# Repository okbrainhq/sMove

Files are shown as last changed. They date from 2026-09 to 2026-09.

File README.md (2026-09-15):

# sMove — PCB + three-piece enclosure

> **Schematic ECO 2026-09-15 (SCHEMATIC ONLY — no PCB change, no routing).** Added **SW1**, an off-board pack toggle switch in series in the battery + lead (hard "True OFF", ≥0.5 A / <50 mΩ, wired to the same 2.54 mm wire-pad footprint as J2); routed the charger's open-drain **CHG_N** to **U1 GPIO6** with a 100k pull-up (**R24**); and changed **U4** to **XC6220B331MR-G** (SOT-25, LCSC C86534) with a new footprint `SOT-25_XC6220`. The AP2112K's SOT-23-5 pin map is identical (1=VIN 2=VSS 3=CE 4=NC 5=VOUT), so no rewire was needed. ERC is **0 violations**, matching the pre-change baseline; the board, `dist/` and enclosure data are unchanged and stale until a forward update (F8) plus placement is done. See [Main PCB status](PCB/main/README.md) and [radio/battery architecture](docs/revision-r2/integrated/RADIO-BATTERY.md).

> **Current PCB workspace revision: components staged, UNROUTED.** [Main PCB status](PCB/main/README.md): schematic links repaired; ESP32/U1, USB-C/J1, IMU/U2 and battery +/− holes/J2 remain fixed, with the other 43 footprints staged to the right for manual placement. No tracks/vias; latest zone state preserved. Forward schematic update reports 0 errors/warnings and DRC finds 0 schematic-parity issues. A pre-existing J2/U1 courtyard overlap and unrouted connections remain. **Not for fabrication or charging; exports/enclosure data are stale.**

> **Historical routed PCB revision:** [Routing completion, plane selection and verification](docs/revision-r2/main-routing/README.md): the user's rotated-U8 USB layout is retained, remaining nets use top/bottom routing, In1 is GND and In2 contains power regions. **0 DRC errors, 0 unconnected items, 0 parity issues; one existing J2 library warning.** [Reusable routing/rotation tools](scripts/pcb_tools/README.md) include exact manual coordinates and vias. **Not a fabrication/charging release; `dist/` and enclosure exports remain stale.** Earlier enclosure descriptions below are historical. The prior RED LED GPIO3 change remains required.

> **Previous PCB update:** The [LED is now fully routed on the user's revised layout](docs/revision-r2/led-routing/README.md), with top-left/bottom-right space reserved for future M3 hardware. The enclosure and `PCB/main/dist/` remain older snapshots; their alignment/manufacturing claims below do not apply to the revised PCB without regeneration and review.

**Current review: white rounded Midframe + Top cover + Bottom cover. No screws, nuts, inserts or PCB enclosure-mounting holes. Default outer wall 0.8 mm; configurable and checked at 1.2 mm. No merge, manufacturing release or charging release.**

- [Current enclosure and regeneration](housing/README.md): opposite-side battery/PCB pockets, insulated support, optional PCB adhesive, screwless sleeve/snap covers and an internal perimeter BAT route around the separator edge.
- [PCB](PCB/main/README.md): targeted H1/keepout removal and copper refill; all 1,726 tracks and 97 vias preserved. Circuit, pad geometry, aligned buttons, antenna rules and battery interface unchanged.
- [JLCPCB fabrication/assembly export](scripts/jlcpcb/README.md): regenerates `PCB/main/dist/jlcpcb/` (`gerber.zip`, `bom.csv`, `pick_and_place.csv`, `export-report.json`) from the native KiCad `LCSC`/`MPN` fields on the symbols and footprints.
- [Historical screwless revision evidence](docs/revision-r2/screwless/README.md): fresh configured DRC/ERC, full native comparisons, manifold solids, collision/access checks, actual wall variation, FreeCAD images and hash manifests.
- [Printing/assembly and physical gates](housing/PRINTING-ASSEMBLY.md): actual pack/lead exit, insulation/adhesive, print supports, snap fit/creep, PCB deflection and charging qualification still required. No proven physical fit.

Default envelope including snap reinforcement: **42.85 L × 34.3 W × 19.0 H mm**. Accepted 30×20×3 mm battery candidate / 31×21×4.3 mm complete-pack allowance retained, behind the north antenna exclusion. Main underside faces the body; IMU +Z remains outward. LED, RESET/BOOT and USB-C accesses align to the current native PCB.

Previous [button alignment](docs/revision-r2/button-alignment/README.md), [PCB repair](docs/revision-r2/pcb-repair/README.md), and [two-part case](docs/revision-r2/two-part-case/README.md) records are historical snapshots, not current assembly instructions. Unrelated electronics and history are preserved.

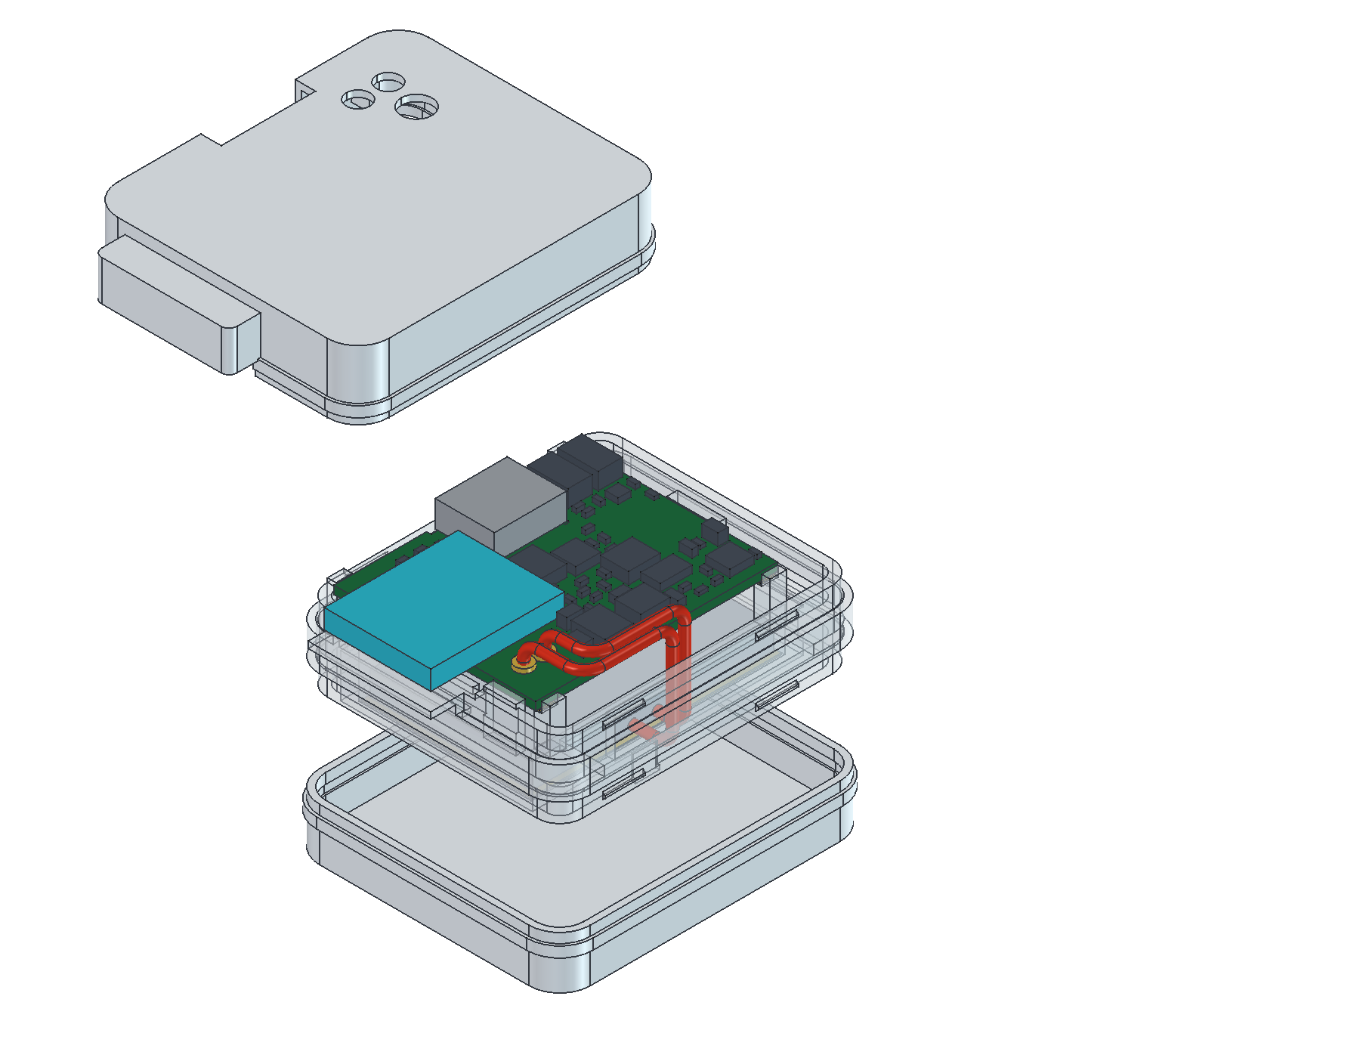
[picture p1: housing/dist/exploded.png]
Current three-piece exploded CAD


### Enclosure-only RF test prototype

Current `housing/` preserves the validated 25×30 mm PCB unchanged. Three screwless prints integrate a protected original-module antenna cap, source-derived flush USB mouth and internal perimeter BAT route around (not through) the separator. Overall 42.85×34.3×19.0 mm at 0.8 mm walls. See [housing documentation](housing/README.md) for source evidence, nominal checks and physical/RF/sweat qualification holds. No PCB shrinking or external antenna substitution.

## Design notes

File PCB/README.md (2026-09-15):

# PCB deliverables

> **Current alignment revision:** [RESET/BOOT switches and matching lid openings](../docs/revision-r2/button-alignment/README.md). Supersedes the historical unchanged-PCB claims below; review only, not released.

**Current design:** [repaired 25×30×1 mm main PCB](main/README.md), with the IMU fitted directly on top. All PCB/main files remain byte-identical to the complete e033031 repair recovered as 0610d60; no PCB edit accompanied the central-screw case revision.

The historical PCB-only mounting warning is retained in its original report. For the current central H1 M3×8 assembly use the [combined delivery](../docs/revision-r2/two-part-case/README.md) and [case assembly/insulation gates](../housing/PRINTING-ASSEMBLY.md). CAD checks do not release it for manufacture or charging.

Old compact-placement reviews are archival, NOT part of the current assembly; see the [bounded cleanup inventory](../docs/revision-r2/two-part-case/integration-cleanup.md) for their status.

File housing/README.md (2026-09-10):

# Enclosure-only — RF TEST PROTOTYPE

Three white rounded screwless prints: **Midframe + Top cover + Bottom cover**. Existing validated **25×30 mm PCB, schematic, routing, copper RF exclusions and native module remain unchanged**. No PCB shrinking or external antenna substitution. No manufacturing/charging release, no full Espressif housing-clearance compliance. Enlarge the housing if on-player testing requires it.

## Geometry and fit

- Default ordinary walls/roof/floor: **0.8 mm**, configurable through 1.2 mm. Main body including snap bands: **39.3 L ×34.3 W ×19.0 H mm**. Protected antenna extension makes overall **42.85 L ×34.3 W ×19.0 H mm**. At 1.2 mm: overall **43.65×35.1×19.4 mm**. Main-body length was reduced, not the PCB; the internal perimeter wire corridor adds width.
- Existing module end extends past the main compartment into a thin nonmetallic cap: floor integral with midframe, roof/skirt integral with top cover. No fourth print or bare exposed antenna. Cap floor/roof follow wall setting. This close plastic cap is explicitly an RF compromise, not a clearance-compliant housing or liquid seal.
- Battery candidate remains 30×20×3 mm; complete-pack allowance remains 31×21×4.3 mm (case XYZ 21×31×4.3). Pocket 21.4×31.4; separator gap 0.7. Optional qualified adhesive/insulating supports, no pouch compression. Hard perimeter stops take closure load.
- BAT wires now leave pads **upward +Z**, opposite the inherited below-board model, bend west and run along the **internal midframe perimeter**, descend around the separator's west edge, and return through a locator-only relief to the underside battery. The separator remains continuous over the entire pack. No wire hole through the separator. Exact two routes are in `validation/mechanical.json` and visible in `dist/assembled-wire-path.png` (orange wires, cyan module).
- Conditional wire OD≤1.2 mm, R2 centreline bends, 0.25 mm radial routing reserve; solder reserve radius 1.1 mm, height 0.55 mm above pads. Minimum nominal lead-to-print clearance 0.43 mm; reserve-to-print 0.18 mm, lead-to-lead 0.30 mm at both checked walls. Battery and wire reserves remain respectively 1.5 and 2.18 mm away from the retained forward RF exclusion. These are CAD measurements, not manufacturing tolerance guarantees.
- Sleeve clearance 0.18 mm; insertion flex 0.12 mm; groove radial clearance 0.12 mm. Snug covers require physical printer/material calibration. RESET/BOOT holes 2.9 mm, web 0.85 mm; LED aperture 3.8 mm retained.

## Source-derived flush USB-C

J1 is **HRO TYPE-C-31-M-12 / LCSC C165948**, retained native footprint. `sources/hro-type-c-31-m-12.pdf` is the supplier-hosted HRO drawing copied from workspace 032's mechanical evidence only, not its failed layout. `sources/usb-mechanical-evidence.json` preserves source URLs, drawing SHA256 and dimensional evidence; its prior proposed cutout is historical, superseded here.

Drawing nominal body W×D×H = 8.94×7.35×3.26 mm; maximum W/H = 9.09/3.36 mm. Native locator datum case X18.5 + drawing front distance 6.28 puts the metal mouth at **X24.78** (native X124.78), 0.03 mm beyond the inherited simplified envelope face. The local stepped exterior surround terminates at that exact nominal mouth plane; the plastic outside it is relieved. This is not a recessed insertion tunnel. Main lower shoulder remains wider.

Opening **10×4.3 mm** exceeds the source maximum plus **0.2 mm placement +0.2 mm print/fit allowance per side** (minimum 9.89×4.16). Nominal source body/mating aperture geometry is separately modeled; component collision checks also retain the conservative native envelope. Check the actual connector placement and selected cable overmould on a print: **no “any cable” guarantee**, and exact as-built flushness cannot be guaranteed from nominal CAD.

## Files and regeneration

`smove-r2-enclosure.FCStd` is editable native CSG with live `Parameters.Wall`. `dist/smove-r2-printable.step` contains exactly three solids; `dist/smove-r2-assembly.step` includes reference electronics, battery, insulation, wires and solder. Three STLs have print orientations; seven PNGs include opaque assembled, transparent wire-path, exploded and section views. Prints are white; transparent presentation is diagnostic only.

Edit `housing/screwless.json` → `outer_wall_mm` (default 0.8). From repository root:

```sh
/usr/bin/python3 scripts/freecad/bootstrap.py --verify-only
# If runtime absent, run bootstrap.py without --verify-only first.
/usr/bin/python3 scripts/r2/enclosure/extract.py
/usr/bin/python3 scripts/freecad/run.py housing/entry.py generate
/usr/bin/python3 scripts/freecad/run.py housing/entry.py generate 1.2
cp .cache/wall-1.2/validation/mechanical.json housing/validation/wall-1.2.json
/usr/bin/python3 scripts/freecad/run.py housing/check_native.py
/usr/bin/python3 scripts/freecad/run.py housing/qualify.py
# In an available authorized X11 display:
/usr/bin/python3 scripts/freecad/run.py housing/render.py
python3 housing/seal.py
python3 housing/seal.py --check
```

**Do not regenerate PCB exports.** Generation asserts hashes of retained PCB and board STEP. Alternate wall outputs stay in `.cache/wall-1.2`; default outputs remain 0.8. `check_native.py` and `qualify.py` expect the default 0.8 delivery and alternate 1.2 build. `entry.py verify` regenerates; it is not read-only. Other dimensions/route changes require deliberate source edits and complete revalidation, not just changing Wall.

## Evidence and qualification limits

`validation/mechanical.json` and `wall-1.2.json`: 819 nominal checks each, including three valid closed solids/STEP reimport, component/pack/wire interference, measured wall, accesses and sampled insertion. `native-parameter.json`: 16 reopened-native/live-wall checks. `prototype.json`: independent manifold/orientation checks of both sets of STLs, sampled cover travel without lead collision, cap coverage rays and outward USB opening. Sampled motion/coverage are not continuous physical simulations or waterproofness proofs. `pcb-preservation.json` hashes every tracked PCB file against the unchanged Git baseline. `dist/manifest.json` binds sources, CAD, exports and reports (self excluded).

Physical gates: actual pack lead exit and soldering process, wire bend rating/strain relief, print accuracy/support removal, snap force/creep/cycles, drop/body movement, skin contact, RF on-player in intended orientations, sweat ingress/abrasion, thermal and charging suitability. The vendor pack-to-modeled-entry connection remains conditional on the selected pack. Do not force fit, charge, or claim sweat resistance from these nominal checks. See `PRINTING-ASSEMBLY.md`.

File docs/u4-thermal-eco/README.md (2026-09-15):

# U4 thermal layout ECO — workspace delivery

## Result and scope

Implemented in `/home/azero/.okbrain/workspaces/smove-files/045`, branch
`okbrain/smove-files/045-ebca5b6f`, based on `main` at **43ee2ea**. No commit or
base-branch modification was made. All ignored/untracked lock, backup,
`docs/revision-r2/` and `housing/` content was left alone.

- Board: eight **GND / net 18** plated through vias, **0.6 mm land / 0.3 mm drill**, and two solid GND pours.
- `smove-r2-main.kicad_dru`: six appended lines defining a **0.21 mm clearance rule scoped only to the two named new zones**. The pre-existing global 0.15 mm rule overrides the zone-local clearance, so setting the zone property alone is insufficient. The original rules are unchanged.
- No new tracks; no moved/deleted tracks, vias, pads, footprints, outlines or existing zones. **Every existing board UUID object, including all four complete zones and their filled polygons, is byte-identical.**
- No schematic, symbol, footprint-library, project-settings or fabrication-output file changed. `dist/jlcpcb/*` was not regenerated.
- U6 was intentionally left untouched. Its exposed-pad cooling warrants a separate layout/assembly review; a drilled cluster under that SMD pad must not be casually treated as standard no-via-in-pad construction.

## Preflight, exact output

`git log --oneline -3`:

```text
43ee2ea board: user routing + direct C11 ground path (thermal-ECO baseline)
5c86d78 Merge okbrain/smove-files/043-2e05b855 into main
267618d fab: regenerate JLCPCB assembly/fab outputs for the routed board
```

`git status --porcelain -- PCB/`:

```text
?? PCB/main/smove-r2-main-backups/
?? PCB/main/~smove-r2-main.kicad_pcb.lck
?? PCB/main/~smove-r2-main.kicad_sch.lck
```

`git merge-base --is-ancestor 43ee2ea HEAD` returned 0. No tracked PCB changes;
only the allowed untracked noise. The base directory was checked again at the
end and still had exactly this HEAD and PCB status.

## Measured geometry — not thermal performance

Measurements are from native copper geometry in millimetres. Saved zone
polygons are unioned, other connected components excluded, and actual drill
voids subtracted. Pads/tracks use KiCad polygonization with maximum 0.001 mm
curve error; circular holes use 1024-sided polygons. Values are reported to
0.001 mm², not with a claim of fabricated-board dimensional accuracy.

### Copper area

| Metric | Before | After |
|---|---:|---:|
| F.Cu same-layer contiguous GND copper containing U4 pin 2, including pads/tracks/via lands, minus holes | 1.058 mm² | 27.802 mm² |
| Directly attached F.Cu zone-only copper, minus cutouts/other components/drills | 0 | **26.008 mm²** |
| B.Cu same-layer contiguous copper reached from U4's original via, minus holes | 0.212 mm² | 50.281 mm² |
| New B.Cu zone-only copper, minus cutouts/drills | 0 | **50.025 mm²** |
| Existing In1.Cu GND filled polygon (before subtracting drilled voids) | 680.173 mm² | 680.173 mm², unchanged |

**Important baseline correction:** the saved board does NOT have 15 mm² of
contiguous front copper on pin 2 or no interlayer path. It already has a
0.6/0.3 mm through via at **(110.3, 119.7)**, UUID
`84533de4-9e53-4210-9cdf-38a20bf1c6b0`, connected by a 0.2 mm track to pin 2
and to the existing In1.Cu plane. Its bottom copper was only an annular land,
not a spreader. The ECO improves an existing narrow connection; it does not
create the first interlayer connection. Electrically connected board-wide GND
area is not interchangeable with thermally effective area.

### Polygon area proof

Both new outlines are the same rectangle:

```text
(104.5,117.0) → (113.2,117.0) → (113.2,123.2) → (104.5,123.2)
gross area = 8.7 × 6.2 = 53.940000 mm²
```

**F.Cu** (`U4_THERMAL_F.Cu`):

```text
53.940000  gross polygon
-26.448115 clearance cutouts / unfilled regions
 -0.777169 other F.Cu component (not counted towards the requirement)
 -0.706854 drilled voids in the directly attached component
=26.007862 mm² directly attached to U4 pin 2 — exceeds 25 mm² by 1.008 mm²
```

**B.Cu** (`U4_THERMAL_B.Cu`):

```text
53.940000 - 3.145030 clearance/unfilled cutouts - 0.769796 drilled voids
=50.025175 mm², one contiguous spreader
```

All eight new via centres lie in both the **same directly attached F.Cu
component** and the B.Cu spreader. U4 pin 2 inherits the zone's **solid/full
connection**, not a thermal relief; its footprint/pad record was not edited.
Both zones use priority 1, 0.2 mm minimum fill thickness, 0.21 mm clearance and
unconnected-island removal. All original zone definitions and fills remain
verbatim. The new rectangles are **17.000 mm** from the antenna keep-out.

### New vias and measured clearances

All are ordinary F.Cu–B.Cu through vias spanning the four-copper-layer board,
GND/net 18, diameter **0.600 mm**, drill **0.300 mm**, no via-in-pad. Coordinates
are absolute KiCad board coordinates, not fabrication-origin offsets.

| X mm | Y mm | Minimum gap to ANY existing track/via/pad, all copper layers |
|---:|---:|---:|
| 108.500 | 121.400 | 0.215887 mm |
| 108.600 | 119.700 | 0.267680 mm |
| 110.200 | 120.600 | 0.300000 mm |
| 111.400 | 121.900 | 0.236396 mm |
| 111.700 | 119.500 | 0.233773 mm |
| 112.100 | 120.300 | 0.300000 mm |
| 112.100 | 121.200 | 0.300005 mm |
| 112.900 | 121.600 | 0.237500 mm |

Minimum new-via/new-via edge gap: **0.294427 mm**. The array is staggered around
existing routing rather than forcing a regular grid through it. Zone/foreign
copper minimum gaps: **0.209490 mm F.Cu**, **0.209585 mm B.Cu**. These additional
geometric checks are important because the board-wide rule permits 0.15 mm.

### Counts and preservation proof

| Board item | Before | After | Change |
|---|---:|---:|---:|
| Track segments | 426 | 426 | 0 |
| Vias | 77 | 85 | +8 GND |
| Zones, including 3 rule/keep-out areas | 4 | 6 | +2 GND |
| Footprints | 53 | 53 | 0 |

The PCB text diff is **243 insertions / 0 deletions**; the scoped rules diff
is **6 insertions / 0 deletions**. All **570 original UUID-bearing board
objects**, plus the board settings and net table, are identical. SHA-256 of
the sorted original-object contents, before AND after:

```text
2395968efe291f80d9d4094aeb9fcb709e6de5a6fb2a11288028f21f4feb7b15
```

C11's direct grounding path remains exactly:

```text
F.Cu, GND, width 0.2 mm:
(113.8,116.3) → (113.8,116.127486) → (113.987486,115.94)
0.6/0.3 mm GND through via at (113.987486,115.94)
```

Its two segments and terminal via have matching before/after individual
SHA-256 hashes, UUIDs and complete s-expressions in `geometry.json`:

| UUID | Before = after SHA-256 |
|---|---|
| d8e59a01-d4bc-4fee-9aa6-d1b957c9a084 | 3efd501127e1100831a573a04b7a733f456befd1b488be982abbc4ddbfa67016 |
| 772e4247-d55b-4c14-9ccd-2492ecce88d9 | cea57377c59c4c5105f0b803d8feb91c202f6ae6ba926a14cab701b00d2d21b4 |
| 8855345a-7815-4444-8592-dd19988b35d9 | 7880821dcc05619653ac3cdfea56daa081877ceac84ed72dd1585ad4da671673 |

C11's entire footprint and all other nets' geometry are also covered by the
byte-equality assertions. Added objects are restricted to eight GND vias
and two GND zones; nothing was silently deleted or reserialized.

## DRC and refill evidence

Baseline command, before any change:

```sh
kicad-cli pcb drc --exit-code-violations --format json --output /tmp/smove-u4-eco-045/before-drc.json PCB/main/smove-r2-main.kicad_pcb
```

Result: **0 violations, 0 unconnected items**, exit 0; archived as
`baseline-drc.json` (default errors/warnings).

Final command, KiCad **9.0.8**, all severities including exclusions:

```sh
kicad-cli pcb drc --exit-code-violations --severity-all --all-track-errors --format json --output docs/u4-thermal-eco/drc.json PCB/main/smove-r2-main.kicad_pcb
```

Result: **0 violations, 0 unrouted/unconnected**, exit 0. No rule suppression
or DRC exclusions were added. Schematic parity was not requested/tested.

A full second refill was also run on an isolated copy with the actual
`.kicad_pro` and `.kicad_dru`. The geometric symmetric difference for **each
of the three copper zones was exactly 0 mm²**, including the original In1.Cu
plane (`refill-check.json`). The copied project files are essential: refilling
a standalone PCB with default project rules gives different copper clearances.

## Estimated thermal result — conditional, not measured

**This ECO is not thermal sign-off for sustained 470–700 mW.** Neither
junction temperature nor thetaJA was measured. The baseline review's
220–250 °C/W is not independently validated, especially given the existing
via/inner-plane path found above. A claim of ~130 °C/W or halving the RF peak
rise would be unsupported.

### Datasheet reference

Torex's XC6220 datasheet, SOT-25 power-dissipation page 26, gives **166.67 °C/W**
for a **40 × 40 mm**, 1.6 mm FR-4 test board, approximately **800 mm² copper
on each face**, four 0.8 mm through holes, natural convection. Its 600 mW
rating at 25 °C uses **Tj = 125 °C**. That much larger reference fixture cannot
be substituted for this board. The unmounted 250 mW figure corresponds to
400 °C/W on the same 100 °C rise basis. [source](https://media.digikey.com/pdf/Data%20Sheets/Torex/XC6220.pdf)

### Transparent copper/connection adjustment

For an illustrative, deliberately limited estimate, use:

```text
thetaJA = 400 || (Rshared + Raccess + Rvia)
X || Y = X*Y/(X+Y)
```

- The 400 °C/W parallel bypass is an **assumed heuristic** based on the
  unmounted reference, not a measured package thetaJC or independently known
  heat-flow branch.
- Calibrate the before network to the review's **250 °C/W** upper estimate.
- **Measured/design geometry:** the old 0.2 mm neck has 0.341697 mm centreline
  outside the U4 pad and original via land. The specified copper is 35 µm;
  F.Cu-to-In1.Cu centre spacing is 0.315 mm. Importantly, the old via already
  reaches this inner plane; do NOT charge it the full 1 mm barrel resistance
  when modelling that path.
- **Assume** copper conductivity 390 W/(m·K) and 25 µm plated via walls.
  `R = L/(k*A)` gives **125.16 °C/W old neck**, **31.64 °C/W old via to In1**,
  and about 100.45 °C/W for a full-depth 1 mm barrel.
- The calibration leaves `Rshared = 509.86 °C/W`, representing the unknown
  die/lead/board path. This is fitted, not a datasheet parameter.
- After the solid F.Cu pour, **assume 60 °C/W spreading/access resistance**
  (~0.82 squares of 35 µm copper). Credit only **4.5 effective parallel vias**
  from the original one plus eight new ones, acknowledging non-isothermal
  access. The other existing vias now reached by the pour receive no credit.
- Keep the shared package/board resistance fixed: give **no additional
  board-to-air cooling credit** to the measured 50.025 mm² bottom spreader.
  This avoids inventing an area-to-thetaJA curve that the datasheet does not
  supply. It is a limited connection-improvement model, not an enclosure
  thermal simulation, and the assumptions are not guaranteed conservative.

```text
Before: 400 || (509.86 + 125.16 + 31.64) = 250.00 °C/W
After:  400 || (509.86 + 60.00 + 31.64/4.5) = 236.22 °C/W
Delta: -13.78 °C/W (~5.5%)

Relative to the 166.67 °C/W datasheet fixture:
assumed board/connection penalty +83.33 → +69.55 °C/W
```

Varying assumed access 40–120 °C/W and effective vias 2–9 gives **232–247 °C/W**
with the same 250 °C/W baseline. This is a model-sensitivity span, **not** a
confidence interval or a guaranteed bound; unknown die-to-GND coupling,
plating, assembly, U6 heating, airflow and enclosure conditions may dominate.

### Peak-power steady-state projections

Stated design scenario: **40 °C local board ambient**, Vin **5.3 V**, Vout
**3.3 V**. Treat peak dissipation as continuous for this deliberately severe
steady-state projection; quiescent power is neglected relative to the stated
470/700 mW. These are *pre-protection linear projections*, not actual measured
RF burst peaks.

| Peak-power scenario held continuously | Before thetaJA 250 | After estimated thetaJA 236.22 | Delta |
|---|---:|---:|---:|
| 235 mA, 470 mW: junction rise | 117.50 °C | 111.02 °C | **−6.48 °C** |
| 235 mA, 470 mW: junction temperature | 157.50 °C | 151.02 °C | **−6.48 °C** |
| 350 mA, 700 mW: junction rise | 175.00 °C | 165.35 °C | −9.65 °C |
| 350 mA, 700 mW: junction temperature | 215.00 °C | 205.35 °C | −9.65 °C |

These projections exceed the 125 °C power-rating basis and reach/exceed the
**typical 150 °C thermal shutdown** region; the device cannot be assumed to
remain regulating at those projected temperatures. Thermal shutdown is not
an operating target or a substitute for qualification. [source](https://media.digikey.com/pdf/Data%20Sheets/Torex/XC6220.pdf)

**Unverified:** actual transient RF peak temperature, duty-cycle response,
physical thetaJA, worst-case enclosure ambient/airflow, actual via plating,
and XC6220 die-to-pin-2 thermal coupling. Verify a populated board under the
real RF workload and charging conditions. If 470–700 mW is sustained at the
stated ambient, use a lower-loss supply/thermally stronger regulator solution
rather than treating this copper ECO as sufficient.

## Reproduction and artifacts

`verify.py` reads the baseline with `git show 43ee2ea:...`, asserts byte-level
preservation, measures net copper area and checks clearances/connectivity.
It never writes a PCB/project file. `thermal-model.py` separately calculates
the labelled conditional model; it does not conflate geometric and thermal
measurements. Both require KiCad's Python `pcbnew` module and Shapely 2.x.

The commands used with the temporary dependency directory were:

```sh
PYTHONPATH=/tmp/smove-u4-eco-045/pylibs /usr/bin/python3 docs/u4-thermal-eco/verify.py > docs/u4-thermal-eco/geometry.json
PYTHONPATH=/tmp/smove-u4-eco-045/pylibs /usr/bin/python3 docs/u4-thermal-eco/thermal-model.py > docs/u4-thermal-eco/thermal-model.json
```

With Shapely installed in the same Python environment, omit `PYTHONPATH`.
No project trick was silently saved.

- `geometry.json`: counts, positions, clearances, area arithmetic, individual and aggregate preservation hashes.
- `drc.json`, `baseline-drc.json`: CLI DRC reports.
- `refill-check.json`: all copper fills reproduce with zero symmetric difference.
- `thermal-model.json`: input geometry, assumptions, network values and temperature projections.
- `after-front.png`, `after-back.png`: native-copper review diagrams, **not fabrication artwork**.

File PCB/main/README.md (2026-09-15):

# Main PCB — 25 × 30 × 1 mm manual-layout reset

## Current schematic ECO — pack cutoff switch, charger status, 3V3 LDO (2026-09-15, SCHEMATIC ONLY)

Applied to `power.kicad_sch`, `compute.kicad_sch` and `smove-r2-main.kicad_sch`:

* **SW1 — hard pack cutoff.** An off-board toggle switch in series in the battery **+** lead, upstream of the `PACK_P` node. Schematic symbol uses the same 2.54 mm two-pad wire footprint as J2 (`smove-r2-main:BatteryWire_2x_PTH_P2.54mm_D1.0mm`), `in_bom no` (user-supplied off-board part: **≥0.5 A rating, contacts <50 mΩ, ≥6 V DC**). Net split: `/Power/PACK_RAW` = J2.1 + SW1.2, `/Power/PACK_P` = SW1.1 + C2.1 + R14.1 + U6.2 + U6.3. This provides the *True OFF* that `docs/revision-r2/integrated/RADIO-BATTERY.md` records as missing.
* **R24 (100k, LCSC C25741) + `/CHG_N` net — charger status to the MCU.** Charger open-drain `CHG_N` (U6 pin 9) is pulled up to 3V3_MAIN and routed to **U1 pad 20 = GPIO6**; `/CHG_N` = U6.9 + R24.2 + U1.20. New sheet pin added to both the Power and Compute sheet symbols.
* **U4 = XC6220B331MR-G** (Torex, LCSC C86534) replaces `AP2112K-3.3TRG1`. The SOT-25 pin map **1=VIN 2=VSS 3=CE 4=NC 5=VOUT** is the *same function map* as the AP2112K SOT-23-5 it replaces, so no rewire and no pad remap was needed. New footprint `assets/smove-r2-main.pretty/SOT-25_XC6220.kicad_mod` (JEDEC MO-178 Var AA land pattern, identical geometry to `SOT-23-5`); the SW1 symbol was added to `assets/smove-r2-main.kicad_sym`.
* `J2` was moved down 10.16 mm **on the sheet only** (cosmetic, no connectivity change) to make room for SW1.

Verification (KiCad 9.0.8): `kicad-cli sch erc` reports **0 violations — identical to the HEAD baseline**, and `kicad-cli sch export netlist` confirms the three nets above.

**Deliberately not done — no PCB change and no routing.** The board still carries the AP2112K SOT-23-5 at U4 (its footprint field now differs from the schematic) and has no SW1/R24 footprints, so a forward update (F8) plus manual placement is required before parity is restored. `dist/` and the enclosure data remain stale and must be regenerated (`python3 scripts/jlcpcb/export.py PCB/main --overwrite`) after the board is updated. **Engineering prototype — no charge or fabrication approval.**

## Library and asset layout

All project-local KiCad libraries and models now live under `assets/` (moved from the project root; content byte-identical apart from the references below):

| Path | Contents |
|---|---|
| `assets/smove-r2-main.pretty/` | main footprint library (nickname `smove-r2-main`) |
| `assets/imu.pretty/` | integrated-IMU footprint library (nickname `imu`) |
| `assets/smove-r2-main.kicad_sym`, `assets/imu.kicad_sym`, `assets/Device.kicad_sym`, `assets/power.kicad_sym` | project-local symbol libraries |
| `assets/imu-models/` | local STEP models, referenced as `${KIPRJMOD}/assets/imu-models/...` |

`fp-lib-table`/`sym-lib-table` stay at the project root and point at `${KIPRJMOD}/assets/...`. Schematic sheets, project/design-rule files and `dist/` are untouched; only the U2 3D-model path (in the board and in `assets/imu.pretty/InvenSense_QFN-24_3x3mm_P0.4mm.kicad_mod`) changed text.

Verified with KiCad 9.0.8: the board reloads with the same 47 footprints, 461 tracks and 7 zones; DRC reports 0 violations / 0 unconnected / 0 schematic-parity (the DRC library check covers footprint-library resolution), ERC reports 0 violations, and all four symbol libraries parse and still contain every referenced symbol. Historical ECO scripts under `scripts/r2/` (for example `integrated/migrate.py`, `integrated/layout.py`) still name the pre-move project-root paths; they are documented as destructive historical helpers and must not be rerun on this board.

**Status note:** the headings below describe earlier working states. DRC on the currently saved `smove-r2-main.kicad_pcb` reports 0 violations, 0 unconnected items and 0 schematic-parity issues, and no footprint origin lies outside the board outline, so the "UNROUTED / components staged" wording below is stale and has not been rewritten here.

## M3 screw mounting holes with grounded copper rings (2026-09-15)

Three plated 3.2 mm M3 clearance holes were added to the three free board corners, each
with a 5.0 mm grounded copper ring on all four copper layers:

| Ref | Corner | Centre (native mm) | Hole | Ring | Net |
|---|---|---|---|---|---|
| **H1** | top-left | 103.20, 103.20 | 3.2 mm plated | 5.0 mm Ø, 0.90 mm annular, mask open | `GND` |
| **H2** | bottom-left | 103.20, 126.80 | 3.2 mm plated | same | `GND` |
| **H3** | bottom-right | 121.80, 126.80 | 3.2 mm plated | same | `GND` |

* Each centre is exactly 3.20 mm in from both adjacent edges, so the three holes are
  identical except for the corner they avoid. The top-right corner is **occupied** by J2
  and R3/R4/U8 — 1.4 mm of clear width, less than the drill.
* Footprint `smove-r2-main:MountingHole_3.2mm_M3_Pad_5mm` lives in
  `assets/smove-r2-main.pretty/`. It is a reduced-ring variant of KiCad's
  `MountingHole:MountingHole_3.2mm_M3_Pad`: that part's 6.4 mm pad needs 3.45 mm of
  board-edge clearance and does not fit any corner of this board. 5.0 mm is the largest
  ring that keeps ≥0.25 mm copper-to-edge (actual 0.70 mm), ≥0.15 mm foreign-net
  clearance (actual 0.44/1.10/0.81 mm) and a non-overlapping courtyard (actual
  0.26/0.41/0.33 mm, courtyard = the 5.5 mm M3 head envelope) at all three positions.
* `board_only`, excluded from BOM and position files, no schematic symbol: mounting
  hardware is not a purchased or placed part, and schematic parity stays 0.
* **Zones were deliberately not refilled.** The rings join the GND node by overlapping
  the saved In1.Cu plane (all three centres are inside the fill, DRC 0 unconnected). A
  fresh refill would re-cut 31.6 mm² of that plane even on the unmodified board, which
  is not part of this change.
* Board diff is **+333 lines, 0 deletions**; deleting the three footprint blocks
  reproduces the previous board byte-for-byte. `bom.csv` and `pick_and_place.csv` are
  byte-identical; the Gerbers gain only the three 5.0 mm rings and their mask openings,
  and the PTH drill gains one `T4C3.200` tool with three hits.
* DRC **0 / 0 / 0**, ERC **0**. See the
  [change record](../../docs/revision-r2/m3-mounting-holes/README.md) and its
  `verification.json`; reproduce with `python3 scripts/r2/final/m3_mounting_holes.py
  --check --geometry` and `python3 scripts/r2/m3-mounting-holes/verify.py`.
* **The enclosure does not have these holes.** `housing/` is still the screwless
  revision (no bosses, threads or inserts); it needs a companion revision before M3
  hardware is usable. Physical fit, torque and the RF effect of the new metal near the
  ESP32-C3 antenna are unqualified.

## Silkscreen outlines, pin-1 markers and free-library parts (2026-09-15)

All 46 assembled parts still carry verified `LCSC`+`MPN` fields, and the export
(`python3 scripts/jlcpcb/export.py PCB/main`) now also reflects these changes; see the
[change record](../../docs/revision-r2/silk-and-basic-parts/README.md) and its
`verification.json`, renders and live BOM audit.

* **U6** (BQ24074RGTR) had *no* silkscreen, so it had no pin-1 indicator: three corner
  brackets plus the same outside pin-1 arrowhead the IMU (U2) uses now point at the
  TS/pad-1 corner.
* **U1** (ESP32-C3-MINI-1) body outline and antenna boundary existed only on `F.Fab`.
  `F.Fab` is not part of the Gerber set, so JLCPCB's placement preview showed the module
  as bare 0.4 mm pads — that is why it "did not line up" there. The body outline is now
  copied to `F.SilkS`, clipped at the 100.0 mm board edge where the module overhangs,
  and the `F.Fab` corner chamfer is deliberately not copied (it crosses the left anchor pad).
* **J1** (USB-C receptacle) had no silkscreen at all — the standard shell lines were on
  `F.Fab` — so the same problem applied. Its shell sides and pad-side end are now on
  `F.SilkS`, offset past the `S1` shell pads and clipped at the board-edge notch.
* **D1** (LTST-C19HE1WT) got a closed silkscreen outline outside the land pattern with a
  gap over the pad-1 corner.
* The same geometry was added to the project-local library footprints
  (`assets/smove-r2-main.pretty/*.kicad_mod`), so the DRC library check stays clean.
* **C3** moved from `C29277` (22 µF 10 V, Extended, $3 setup fee) to **`C45783`
  (22 µF 25 V X5R 0805, Basic)**. Every other resistor and capacitor is already
  Basic/Preferred Extended and therefore fee-free, including R21 (`C25924`); the
  estimated extended-part fee drops from $33.00 to $30.00, and the remaining charge is
  the ten design-fixed actives.

Verification: DRC **0 violations / 0 unconnected / 0 schematic-parity**, ERC **0**, added
silk keeps ≥0.17 mm to the nearest pad (board rule 0.10 mm), `F_Silkscreen.gto` gains 36
draw commands, `bom.csv` differs only in the C3 row and `pick_and_place.csv` is
byte-identical. C45783's pocket-height check and a fresh DC-bias screen are still open.

## JLCPCB fabrication and assembly export

`/usr/bin/python3 scripts/jlcpcb/export.py PCB/main` (add `--overwrite` to refresh an existing
set) writes `dist/jlcpcb/`: `gerber.zip` (all four copper layers, masks, silkscreen, paste, edge
cuts, separate PTH/NPTH millimetre drills), `bom.csv`, `pick_and_place.csv` and
`export-report.json`. See the [export tool documentation](../../scripts/jlcpcb/README.md).

- Generated from the currently saved board (47 footprints, 461 tracks, 70 vias, 7 zones, 4 copper
  layers, aux origin 100/135) at this revision. Native DRC/parity on that same file reports
  **0 violations, 0 unconnected items, 0 schematic-parity issues**; the export tool re-verifies
  KiCad's own position output against the board file before writing anything.
- All **46** assembled parts carry a JLCPCB/LCSC catalogue number in the native `LCSC` field,
  together with `MPN`, on both the schematic symbols and the board footprints. The verified
  numbers are recorded in [main-parts.csv](../../docs/revision-r2/main-parts.csv) and
  [stock.json](../../docs/revision-r2/stock.json). J2 (the two plated battery wire holes) is
  intentionally PCB-only and excluded from both BOM and CPL.
- Engineering export only: **not a fabrication, assembly or charging release**. The tool does not
  refill zones, run DRC/ERC, check supplier stock or qualify any purchase code, and `housing/`
  remains a separate historical snapshot.

## Current: schematic links repaired; components staged — UNROUTED

**All 47 schematic footprints are now present.** U1 (ESP32), J1 (USB-C), U2 (IMU), and J2 (battery +/− holes) retain their poses and geometry. The other **43 footprints are staged outside the board to the right** for manual placement. No tracks or vias were added.

The reported dialog was **Update Schematic from PCB**, the reverse direction. Use **Tools → Update PCB from Schematic (F8)** to bring schematic components into the board. The four old footprint paths also contained an extra root-sheet UUID; one reference-based re-link repaired them without replacing or moving the footprints. Re-link is now off for normal updates. A repeat forward-update preview reports **0 errors and 0 warnings**, without duplicate additions. KiCad also repaired duplicate pad UUIDs on save; all pad geometry/nets and footprint UUIDs remain unchanged.

[Update verification](../../docs/revision-r2/manual-layout-reset/schematic-update-verification.json): **0 schematic-parity issues**, 148 expected unconnected items, and one **pre-existing J2/U1 courtyard overlap**, left unchanged to preserve both fixed positions. Schematics and design rules on disk are unchanged. The latest saved zone state was preserved: five rule areas and one filled In1 GND plane; the earlier six-unfilled-zone reset below is historical. **Not for manufacture or charging; exports remain stale.**

## Historical: manual placement/routing reset — UNROUTED

Only **U1 (ESP32), J1 (USB-C), U2 (IMU), and J2 (battery +/− through-hole pads)** remain in the PCB layout, with their complete footprint definitions, positions, orientations and pad/net assignments unchanged. The other **43 footprints were deleted from the PCB only**; all schematic sheets and project/rule files remain unchanged.

Removed **500 track segments, 124 vias, and all 38 cached copper-fill polygons**. All six copper-zone definitions are retained **unfilled**, including In1 GND and the In2 GND / 3V3_MAIN / PACK_P regions. Board outline, stackup, drawings and all keepouts are unchanged. This is actual copper removal, not merely hidden pours.

[Verification](../../docs/revision-r2/manual-layout-reset/verification.json): exact-token preservation check and native board load pass; native DRC reports **0 geometric violations**, **45 intentionally unconnected items**, and **43 expected missing-footprint parity warnings**, plus the existing J2 library-footprint mismatch warning. Previous routed-board acceptance scripts/reports below are historical and are not acceptance criteria for this reset. **Not for fabrication/assembly/charging; existing exports and enclosure placement data are stale.**

For manual placement, open `smove-r2-main.kicad_pro` in KiCad and use **Update PCB from Schematic (F8)** when ready to re-add the missing footprints. Do not delete their schematic symbols. The standalone PCB Editor has this command disabled; launch the editors through the project. J2 was restored verbatim from the pre-reset board at the user’s request, retaining both battery +/− holes. The other 43 missing components have not been re-added or parked outside the board.

## Historical: routed review candidate

See the [routing completion and plane-selection evidence](../../docs/revision-r2/main-routing/README.md). The user's rotated-U8 USB routing is preserved, remaining nets are connected on **F.Cu/B.Cu**, In1 is continuous GND, and In2 has bounded **3V3_MAIN / PACK_P power regions** with GND elsewhere. C7 alone is rotated 180° to fix its isolated ground connection; other placements, pad nets and keepouts are unchanged.

**Fresh native checks: 0 DRC errors, 0 unconnected items, 0 schematic-parity issues, 0 ERC violations; one existing J2 footprint-library warning.** Reusable coordinate routing, via placement, rotation previews, explicit rip-up and cleanup tools are documented in [scripts/pcb_tools](../../scripts/pcb_tools/README.md). Run `/usr/bin/python3 scripts/r2/main-routing/verify.py` for current acceptance checks.

**Not released for fabrication or charging.** USB impedance, current/thermal margins and return paths still need engineering review. Some low-speed paths take long perimeter detours. `dist/` and the enclosure are stale; no manufacturing exports were regenerated.

## Historical: grouped placement review — UNROUTED

See the [placement revision and researched routing strategy](../../docs/revision-r2/placement-routing/README.md). U1, USB, battery pads, outline and both M3 reserved positions are unchanged. The LED/buttons are upper-left, charger/regulator parts are together beside USB, and U2 remains at X112.5 with its original orientation, now at Y126.5. RED is reassigned from GPIO6 to GPIO3; GREEN=GPIO7 and BLUE=GPIO10 remain unchanged. Firmware must adopt the RED pin change.

**Placement only: 152 unconnected items; zero tracks/vias.** Obsolete routing was removed deliberately, not left connecting the wrong pads. Current zone definitions are retained but unfilled; the researched power-region strategy is not implemented yet. Placement geometry, ERC and schematic parity pass, with the existing J2 library-footprint warning. This is **not a finished reroute or manufacturing/charging release**. Existing `dist/` and enclosure openings are stale.

Run `/usr/bin/python3 scripts/r2/placement-routing/review.py` for this revision's checks. Do not use the historical LED-only verifier or layout generators as current acceptance tests.

## Historical: LED routed on the previous layout

The [LED routing update](../../docs/revision-r2/led-routing/README.md) builds on the user's `b155f03` routing setup. All RGB channels are connected, with D1 and every other footprint left in place. Top-left and bottom-right 6 mm clear disks are protected for future M3 hardware; no mounting holes were added. Fresh checks report **0 DRC errors, 0 unconnected items, 0 schematic-parity issues**, with three unchanged pre-existing warnings.

**The native PCB is authoritative. `dist/` and the enclosure are older snapshots, not regenerated for this routing update.** Do not use the older manufacturing bundle without regeneration and review. Run `scripts/r2/main/verify_led_routing.py` for current checks; do not run historical layout generators over this board.

## Historical screwless revision (before the user's reroute)

**Current: [screwless revision](../../docs/revision-r2/screwless/README.md). Not released for manufacture, assembly or charging.**

- Removed the H1 3.2 mm NPTH footprint and its H1-specific copper exclusion. Refilled copper zones into the reclaimed region; **did not reroute** or run legacy routing generators. Clean configured DRC/connectivity/parity did not require disturbing the accepted routing.
- Exact token comparisons retain all **1,726 segments, 97 vias, 47 non-H1 footprints and pad/net/placement data**, board outline, layer/setup data and antenna/corner rules. All five schematics, project rules and electrical parts are unchanged. Existing corner copper-free regions remain dielectric contact reserves, not fastener mounting features.
- Fresh configured ERC / DRC / unconnected / schematic-parity counts: **zero**. Existing ignored defaults remain unchanged; this is not electrical or charging release.
- Four layers, 1 mm nominal total board; In1 GND reference and existing circuit retained. Integrated top IMU +Z outward, underside toward body. Aligned RESET/BOOT at native X121.25; no new UART/testpoints/connectors.
- BAT+ native (104.5,105.57), BAT− (104.5,103.03); 2.54 mm pitch, 1 mm drill target, 2 mm pads unchanged. **USB's two 0.65 mm component locating NPTH holes and plated connector/BAT holes remain**: these belong to the preserved electrical connector footprint, not enclosure mounting hardware. No enclosure mounting holes remain.
- `dist/` is regenerated for this native PCB: Gerbers/drills, BOM/CPL, assembly PDF, board/installed-model STEP and renders. Conservative populated STEP uses exactly one instance per reference, no duplicate display copies. Missing vendor models remain limitations of installed-model renders.
- PCB-only STEP uses drill origin (100,135), unlike housing Y=139−nativeY. Its 0.91 mm dielectric thickness omits copper; the housing conservatively reserves the accepted total 1 mm. Do not mistake this export convention for a board-thickness ECO.

The native board is authoritative. Do not run legacy routing or historical sync tools over it. `scripts/r2/screwless/pcb.py` is the targeted, idempotent ECO/check entry; `scripts/r2/screwless/verify.py` compares against recorded aligned predecessor `b8f2836ac2fb26fc0bf774b803c6613a79e66f1b`. The enclosure uses insulated lands, optional adhesive and travel stops, not PCB or pouch clamping. Physical support/fit still needs qualification.

Historical [PCB repair](../../docs/revision-r2/pcb-repair/README.md) and [button alignment](../../docs/revision-r2/button-alignment/README.md) retain their original scope. Current exports are indexed by `dist/manifest.json`.

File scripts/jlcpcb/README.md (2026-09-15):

# JLCPCB fabrication + assembly export

`export.py` turns one KiCad project directory into the three files JLCPCB asks for,
plus a validation report:

```text
PCB/main/dist/jlcpcb/
  gerber.zip          fabrication data — Gerbers + Excellon drills
  bom.csv             assembly BOM (grouped purchase rows)
  pick_and_place.csv  CPL / centroid file (one row per reference)
  export-report.json  validation report — for review, NOT for upload
```

Upload `gerber.zip` as the PCB fabrication file, `bom.csv` as the assembly BOM and
`pick_and_place.csv` as the CPL / pick-and-place file.

The project is never modified: KiCad is driven from a private temporary directory and
the four files are published only after every check passes.

## Requirements

* Python 3.8+ (standard library only — no pip packages, no `pcbnew` bindings).
* KiCad 9's `kicad-cli` on `PATH` (tested with 9.0.8); override with `--kicad-cli` or
  the `KICAD_CLI` environment variable.

## Usage

```sh
# From the repository root: defaults to PCB/main -> PCB/main/dist/jlcpcb/
python3 scripts/jlcpcb/export.py

# Explicit project, explicit destination
python3 scripts/jlcpcb/export.py PCB/main --output /tmp/jlc-order

# Replace a previous export (existing files are protected by default)
python3 scripts/jlcpcb/export.py PCB/main --overwrite

# Other project layouts / options
python3 scripts/jlcpcb/export.py PCB/main --board smove-r2-main.kicad_pcb
python3 scripts/jlcpcb/export.py PCB/main --schematic main.kicad_sch
python3 scripts/jlcpcb/export.py PCB/main --pcb-only            # ignore the schematic
python3 scripts/jlcpcb/export.py PCB/main --side bottom         # one assembly side only
python3 scripts/jlcpcb/export.py PCB/main --include-through-hole
python3 scripts/jlcpcb/export.py PCB/main --part-field "Supplier Code"
python3 scripts/jlcpcb/export.py PCB/main --require-part-numbers
```

Fabrication layers are always plotted for the whole board, whatever `--side` selects
for assembly. Exit status: `0` success (warnings allowed), `1` error, `2` argument error.

## Cost check: Basic vs Extended parts

`parts_check.py` audits a generated BOM against the live JLC component library and reports
which parts are fee-free. JLCPCB's Economic PCBA charges **USD 3 per unique Extended
part**; Basic parts and *Preferred Extended* parts carry no setup fee, so a Basic or
Preferred replacement for one passive is worth more than its unit price.

```sh
python3 scripts/jlcpcb/parts_check.py PCB/main/dist/jlcpcb/bom.csv --json /tmp/audit.json
```

```text
OK  basic              C45783     stock=   4808921 $ 0.2432 22uF / 25V         C3
OK  preferred-extended C25924     stock=    220063 $ 0.0021 8.2k               R21
FEE extended           C54313     stock=       621 $ 2.1254 BQ24074RGTR        U6

28 BOM rows, fee-free 18, charged 10, estimated extended-part fee $30.00 (3.00/part)
```

This is a read-only query against the same public endpoint the JLC parts page uses: no
account, upload, reservation or order. Stock and library membership change daily, so
re-run it before ordering — the numbers in `docs/revision-r2/silk-and-basic-parts/`
are a dated snapshot, not a guarantee.

## How JLCPCB part numbers are stored in KiCad

The exporter reads **native KiCad fields**; no plugin, custom library or third-party
tool is involved. Add the field `LCSC` in the Schematic Editor (**E** on a symbol →
*Symbol Properties* → add field) and let **Tools → Update PCB from Schematic (F8)**
copy it onto the footprint. Fields added directly in the PCB Editor's *Footprint
Properties* work too. Leave the field's *Show* checkbox off if you do not want it
drawn on the schematic.

Field names are matched ignoring case, spaces and punctuation, so `LCSC`,
`LCSC_Part_Number` and `LCSC Part Number` are the same field.

| Output column | Recognized native fields |
| --- | --- |
| `LCSC Part #` | `LCSC`, `LCSC PN`, `LCSC Part #`, `LCSC Part Number`, `LCSC Part`, `JLCPCB`, `JLCPCB PN`, `JLCPCB Part #`, `JLCPCB Part Number`, `JLCPCB Part`, `JLC`, `JLC Part #` |
| `MPN` | `MPN`, `Manufacturer Part Number`, `Manufacturer Part #`, `Mfr Part #`, `Part Number` |
| `Manufacturer` | `Manufacturer`, `Mfr` |

Extra recognized LCSC fields can be added with `--part-field NAME` (repeatable).

Rules the exporter enforces:

* A part number must be `C` followed by digits (`c1525` is normalized to `C1525`).
  URLs, manufacturer part numbers and other text are **rejected** instead of being
  uploaded as a wrong catalogue code.
* The same part number may be stored on the schematic and on the board; a
  **conflicting** pair stops the export — the tool never guesses which part was meant.
* A part number stored only on the schematic is still exported (the schematic is read
  through `kicad-cli sch export netlist`, hierarchical sheets included).
* A missing part number leaves the BOM cell blank and prints a warning; add
  `--require-part-numbers` to make that an error instead.

In this repository all 46 assembled parts carry verified `LCSC` + `MPN` fields on both
the symbols and the footprints. J2 (the two plated battery wire holes) is deliberately
PCB-only and has no purchase code.

## What is exported

### `gerber.zip`

* Every copper layer declared in the board (all inner layers included), plus front/back
  mask, silkscreen and paste where present, and `Edge.Cuts`.
* Separate plated (`PTH`) and non-plated (`NPTH`) Excellon drill files in millimetres.
* Only freshly plotted fabrication files, flat at the ZIP root — no BOM, no project
  metadata, no stale plots. Protel-style extensions (`.gtl`, `.g1`, `.gbl`, `.drl`, …)
  plus KiCad's `.gbrjob`.

KiCad writes its plot creation date into every Gerber (`%TF.CreationDate%` and a `G04`
comment), so the per-file hashes in `export-report.json` differ between runs even though the
plotted geometry is byte-identical. `bom.csv` and `pick_and_place.csv` are byte-stable for
unchanged inputs.

### `bom.csv`

```csv
Comment,Designator,Footprint,LCSC Part #,Quantity,Manufacturer,MPN
47uF / 6.3V,"C2, C13",C_0805_2012Metric,C16780,2,,CL21A476MQYNNNE
```

The illustrative row above is real for this board. `Comment` is the board value,
`Footprint` is the footprint name without its library prefix, and references are listed
explicitly (never compressed to ranges) with correct CSV quoting. Rows are grouped only
when **value, footprint, part number, manufacturer and MPN all match**, so two
different purchase codes are never merged. If one part number legitimately appears in
more than one row (same part, different schematic values), the report lists it under
`part_number_used_by_several_rows` for review.

### `pick_and_place.csv`

```csv
Designator,Mid X,Mid Y,Layer,Rotation
C13,7.3000,15.0500,Top,270.00
```

Coordinates are millimetres in KiCad's **drill/place file origin** frame (this board:
`aux_axis_origin 100 135`), `Layer` is `Top`/`Bottom`, and `Rotation` is KiCad's
counter-clockwise footprint angle normalized to `[0, 360)`. Both CSVs always contain the
same reference set.

If a part needs a vendor orientation correction, add the native field
`JLCPCB Rotation Offset` with signed degrees (`90`, `-90`). It is added to the exported
rotation and recorded in the report; check the result in JLCPCB's placement preview.
Position offsets are not supported — fix the footprint anchor in KiCad instead.

## Selection rules

A footprint is assembled when all of the following hold:

* it has electrical pads (pure graphics and non-plated mounting holes are ignored);
* it is an SMD footprint (add `--include-through-hole` to also assemble through-hole
  parts after checking JLCPCB's availability);
* it is not marked *Do Not Populate*, *Exclude from BOM* or *Exclude from position
  files* on the board, and not *Exclude from BOM* / *Exclude from board* in the
  schematic;
* it is on the side selected by `--side` (default: both).

Skipped references and their reasons are listed in `export-report.json`. These flags do
**not** remove copper from the Gerbers.

## Checks performed

* KiCad's position file must agree with the board file this tool parses (origin, X, Y and
  rotation), so a mismatched or stale input cannot be exported silently.
* Duplicate or unannotated references, unreadable/absent positions, malformed or
  conflicting part fields and KiCad CLI failures stop the export.
* Value or footprint differences between schematic and board are warnings; the physical
  board wins. References present in only one source are reported.
* The plotted layer set, drill split, unique filenames and ZIP contents are validated
  before publishing.
* `export-report.json` records the SHA-256 of every source file, every fabrication file
  and the three upload files, plus layers, counts, skipped parts and warnings.

## Limits — read before ordering

The report is explicitly **not** a manufacturing release. This tool exports the saved
design; it does **not** refill copper zones, run DRC/ERC, repair outlines, edit the
project, check part stock or validate that a purchase code is electrically suitable.
Before ordering: save both editors, update the PCB from the schematic, refill zones, run
DRC and check the ZIP in a Gerber viewer; then verify part matches, polarity, placement
anchors, rotations and both sides in JLCPCB's preview.

## Tests

```sh
# Unit tests + end-to-end test with a fake kicad-cli (KiCad not required)
python3 -B -m unittest scripts.jlcpcb.test_export -v

# Additionally run the real exporter against PCB/main
JLC_INTEGRATION=1 python3 -B -m unittest scripts.jlcpcb.test_export -v
```

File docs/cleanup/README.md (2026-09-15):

# Repository cleanup evidence

Source-cleanup baseline: former main `9c7bb84cde1e7ee5842be48dd34e0169e0914b47`, isolated workspace 016. That source-cleanup phase performed no commits, history rewrites, branch/workspace deletion, advisors, sourcing or GUI probing. The subsequent local Git-maintenance phase consolidates this tree into one parentless `main` commit; saved CodeChat workspaces, their branch histories and the remote are retained. No remote fetch/push, shared reflog expiry or garbage collection is performed.

[evidence.json](evidence.json) records the BEFORE SHA256 and old-to-new file mapping captured before moves. All 282 baseline entries were independently checked against the baseline Git blobs after recovery from an interrupted provider response. Native projects, models, FCStd, STL/STEP, fabrication ZIPs, BOM and renamed CPL have byte parity; no native path repairs or engineering changes were necessary. Local relative library/model references travel with the boards.

## Retired checks — NOT PASSED

CFIX archival immutability, pre-R22 reference-board comparison, pre-ECO placement preservation, old carrier export preservation and whole-release bundle smoke tests no longer define current validity. Those inputs/checkpoints are not part of the current root snapshot; saved CodeChat workspaces and retained remote history remain available. No unsafe/reference KiCad files are retained just to satisfy obsolete tests.

Current equivalents are native configured ERC/DRC/net exports, main pin/net/fitted/outline/antenna/retention invariants, combined electrical/connector/endpoint checks, canonical housing extraction/contact checks, native BOM/CPL/CID/placement validation and before/after SHA256 parity. Historical test counts are not recycled as new results.

## Layout and scope

`PCB/main` owns one native project and its own dist. `housing` owns one editable FCStd and printable/reference outputs in dist. Fabrication ZIPs contain only Gerber/drill fabrication files, with separate BOM and pick-and-place CSVs. No top-level release/mega ZIP or archive junk folder.

Current source evidence, exact Samsung curves, footprint/pin audits, original models/licenses and historical stock retrieval receipts remain. Reports written by checks are disposable `.cache/` files. Old snapshots, synthetic fixtures, build/reroute/ECO scripts and historical entrypoints are removed.

## Limitations

GUI review remains blocked/not performed. No new visual approval, manufacturing or charge approval. FreeCAD native reopen/regeneration and the former 1938 geometric checks are not claimed as rerun without the pinned runtime. FCStd ZIP integrity and byte parity are not equivalent to recomputation. Optional heavyweight export/bootstrap commands are documented separately from read-only checks.

## Actual cleanup results

Seven read-only verification commands passed in a new project-local clean copy with all legacy directories physically absent. Fresh configured ERC/DRC: both boards zero violations, opens and parity issues; main 17 checks; combined electrical 96; carrier independent audit PASS (no invented assertion count). Standalone CSV/ZIP/manifest/library/link audit: 262 checks. Python syntax: 15 files. Byte parity: 28 critical CAD/model/fabrication/geometry files, and 260 of 282 retained baseline files overall. Support-script/document edits account for the remainder.

Five **external, unbundled model references remain unavailable** in this runtime: Espressif ESP32-C3-MINI-1, JST PH two- and four-pin headers, HRO USB-C and LiteOn LED. These are explicit non-passing model availability gaps, not missing moved local models; exact unavailable paths are recorded in evidence.json. All supplied project-local models resolve. Preserved populated STEP includes labelled conservative envelopes. No substitute models or native path edits were made. FreeCAD pinned runtime is absent; no reopen/regeneration or heavyweight export was run.

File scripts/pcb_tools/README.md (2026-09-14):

# Reusable PCB routing tools

Run from the repository root with `PYTHONPATH=scripts /usr/bin/python3 -m pcb_tools ...`.
Requires the installed KiCad `pcbnew` Python bindings and `kicad-cli`; image previews also use `python3-cairo`.

## Manual routing first for difficult areas

`waypoints` places **exact coordinates**, without a router changing the path. Units are mm in native board coordinates. Repeat the same position on the other outer layer to request a through via:

```sh
PYTHONPATH=scripts /usr/bin/python3 -m pcb_tools waypoints INPUT.kicad_pcb \
  --net '/SIGNAL' --width .2 \
  --points '[[10,10,"F.Cu"],[12,10,"F.Cu"],[12,10,"B.Cu"],[16,14,"B.Cu"],[16,14,"F.Cu"],[18,14,"F.Cu"]]' \
  --output-dir .cache/manual-candidate
```

Coordinates/net above are illustrative, not a recipe for this board. Output directory must be new. Unknown nets, internal trace layers, malformed layer transitions, nonfinite coordinates, obstructed edges, via/paste overlaps and hole conflicts are rejected before insertion. Rejections identify blocking pads/tracks; no half-route is inserted. Explicit `--ripup-id UUID` or `--ripup-net NET` removes selected copper **only in the candidate copy**.

For several coordinated manual edits:

```sh
PYTHONPATH=scripts /usr/bin/python3 -m pcb_tools.recipe INPUT.kicad_pcb edits.json .cache/candidate
```

JSON accepts `remove_ids`, `remove_nets`, `routes` (`net`, `width`, `points`, optional `rules`), optional `zones` (`name`, `net`, `layer`, `priority`, polygon `points`), and optional `move_footprints` (`reference`, `expected_rotation`, `rotation`, optional absolute `position`). Explicit copper invalidation is required for footprint movement; it does **not** automatically reroute stale connections. Recipes in `scripts/r2/main-routing/` record reviewed intermediate edits and contain revision-specific UUIDs: they are examples/audit records, **not an idempotent final-board generator**.

Every saved candidate receives a native DRC/parity report. A saved candidate is not necessarily acceptable: inspect its DRC counts, connectivity, copper fill and image before adopting it. No command overwrites the input board or modifies the input project's rules. Failed recipe geometry leaves the initial candidate copy unchanged.

## Two-point routing

```sh
PYTHONPATH=scripts /usr/bin/python3 -m pcb_tools route INPUT.kicad_pcb U1:26 R3:2 \
  --width .2 --layers top --output-dir .cache/two-point
```

Omit `--output-dir` for a read-only plan. Endpoint pads must belong to the same net; duplicate pad numbers are rejected as ambiguous. Routing tries exact-endpoint straight/45-degree/orthogonal patterns, simple corridors and deliberate bottom-layer fanouts, then bounded, bend-penalized weighted A*. Visibility simplification rechecks every replacement segment at full width. It penalizes bends and vias, rather than optimizing distance alone. Only F.Cu/B.Cu are available for tracks; internal planes are never used for signal detours. Python API: `Router(board, Rules(...)).plan(...)`, `.apply(plan)`, or `.connect(...)`.

Use a coarser grid (e.g. `Rules(grid=.2)`) for long open corridors and finer grids for fine-pitch escape planning. A fine global grid can exhaust the node budget without finding an otherwise simple route. A node-limit failure is **not proof that a route is impossible**. Inspect, place manual waypoints or move the obstructing copper instead of endlessly increasing the search budget. This is not a shove router and does not guarantee shortest paths or optimal placement.

## Rotation / placement previews

```sh
PYTHONPATH=scripts /usr/bin/python3 -m pcb_tools rotate INPUT.kicad_pcb U8 \
  --angles 0 90 180 270 --positions '113.5,113.5' \
  --ripup-connected-nets --output-dir .cache/u8-comparison
```

Refuses locked footprints or connected copper unless explicit preview rip-up is requested. The rip-up flag removes **all tracks on the footprint's connected nets**, including GND, in each isolated preview, not just nearby stubs. Candidates have separate boards, top PNGs, native DRC reports and a ranked `comparison.json`. The approximate connection-length score is topology-only: it is not routing completion, signal-integrity analysis or proof of optimality. Each orientation uses a separate worker process because the installed native bindings showed registry/lifetime failures when loading multiple boards after removals in one process. Keep the full KiCad project beside the input board for schematic parity.

## Safe copper cleanup

```sh
PYTHONPATH=scripts /usr/bin/python3 -m pcb_tools.polish INPUT.kicad_pcb .cache/polished
```

Simplifies degree-two chains while retaining pad/via anchors and protected USB data nets. Each accepted chain passes a fresh native DRC/connectivity check; rejected changes are rolled back. `CopperTransaction` also exposes explicit in-memory rip-up/rollback for other tools. It covers copper only, not footprint/zone transactions.

## Tests and limits

```sh
PYTHONPATH=scripts /usr/bin/python3 -m unittest pcb_tools.test_tools -v
```

Tests cover exact endpoints, deterministic patterns, staircase cleanup, full-width collisions, pad-paste exclusion, both outer layers/vias, bend-aware search, stale-plan rejection, no partial insertion, locked copper, rollback, and output/source guards.

The geometry model is conservative, not a replacement for KiCad's custom-rule engine. Copper zones are refilled after insertion; connectivity can change even when individual segments clear obstacles. Always check native DRC, unconnected items and schematic parity with the original project rules. Do not suppress rule violations to make a route pass. Impedance, differential skew, return-current paths, thermal/current capacity, assembly and fabrication remain separate engineering gates. Runtime SWIG leak warnings can occur on removed objects; tools preserve source files and use isolated candidates/workers to limit that native-binding risk.

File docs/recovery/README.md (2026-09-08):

# Compact delivery recovery — workspace 022

## Result and limits

The compact native PCB, schematics, libraries, source scripts, FreeCAD assembly and exports are recovered from existing Git objects, **not redesigned or regenerated**. All **138 entries** of the recovered complete source/export manifest match their original SHA256 hashes. The two original PCB/housing manifests also pass in full (87 and 28 entries).

**The claimed original 152-path staged index is not present. Do not describe this as a proven restoration of all 152 original pathnames.** The original commit contains only 30 paths. Recovery restores 51 tracked modifications, 44 missing manifest-listed files, and 23 original reports/documents. Twenty report/document paths were correlated from recovered links, script inputs/outputs and report identity; three reports with uncertain original names are explicitly kept under `original-reports/`. All 1,004 initially unreachable Git objects are additionally preserved in `preserved-unreachable.pack`, including older variants and objects not assigned a current pathname. This preserves the evidence for further pathname reconciliation rather than guessing design contents.

No files, workspaces, refs or Git objects were deleted. No merge, push, hardware redesign, firmware work, manufacturing release or advisor activity was performed.

## Provenance

- Before ECO: `c1050a07339897e7203f43137aec96de5bbc41cc`.
- Partial delivery: `87913796a185f379374e7adadf464d674c40f12e`, **30 changed paths**.
- Main merge: `f7c6bc0cd1c727314fc17b57df88e27d1f8647bd`.
- The partial commit and merge have the **same tree**, `5abb41bdf736b86afe5b136d2c0ac3b9a8174c63`. The missing content was already absent from the delivery commit, not dropped by Git's tree merge.
- Orphaned old-workspace autostash: `a5e32962dd6f6561775f31e52b0cef898f6d3663`, directly parented by `87913796…`; recovered worktree tree `d335cd6dc690bb05a4014d4a0ec59af23648235f`.
- Its index parent `8a54357569f0ab25db3695c738830fc39b927478` has the partial 30-path tree, not a full 152-path index.
- Autostash adds 51 modifications and one deletion relative to the partial delivery. The deletion of the unused `PCB/main/smove-r2-main.pretty/Debug_5.kicad_mod` was **not applied**, because deletion was forbidden. The footprint is not placed in the recovered native board or schematic.
- The orphan blob `b4767a0d2e2fd8463130ff67ee8234fff10d200d` is the final 138-entry delivery manifest. Every listed content hash was located in the Git object database; none required reconstruction.
- Detailed path → Git blob → SHA256 evidence: `provenance.json`.
- The preserved-object pack was validated with `git index-pack`. It is evidence, **not an instruction to apply any historical tree**. It also preserves the autostash commit/tree and old variants for later inspection.

## Fresh verification

All tests operate on the recovered exact native files. Original reports and manifests are preserved; fresh results are under `checks/`.

- **1,214/1,214 electrical assertions pass**, including native ERC 0, DRC 0, opens 0 and schematic parity 0 under the unchanged configured severities and manufacturing rules. These are not checks of ignored KiCad defaults or physical electrical qualification.
- **657/657 source/export coherence checks pass**: exact 47-item BOM population/CPL/assembly poses and pad nets; Gerber outline; two M3 Excellon positions; byte-for-byte Gerber ZIP members; all manifest hashes.
- Native outline centreline bounds **25 × 39 mm**. KiCad's drawing bounding-box API includes the 0.05 mm stroke and returns 25.05 × 39.05; this is not a board-size redesign.
- **U2 ICM-20948** at native (112.5, 117.5) mm, −90 degrees: centred across width and 2 mm above the bounding-box centre. No J3 UART/service header or TP1–TP14 in the board or schematic. BOOT/RESET and USB programming remain.
- H1=(103.6,103.6), H2=(121.4,135.4) mm: diagonal **3.2 mm NPTH** holes for M3. Fresh four-layer bearing/copper audit passes.
- Fresh native FreeCAD recompute reproduces **2,087/2,088** mechanical checks, and the entire assertion list exactly equals the original report. Case L×W×H = **49.8 × 29.4 × 19.6 mm** nominal, including modelled recessed heads.
- The one retained failure is conservative `Main_J2_MatingInsertion` / PCB overlap **2.16 mm³**. This is a conservative reservation, not proof of actual PHR-2 plastic interference. J2 remains `S2B-PH-SM4-TB(LF)(SN)`; the user-supplied connector investigation identifies mating housing `PHR-2` and official reference https://www.jst-mfg.com/product/pdf/eng/ePH.pdf. No new hardware geometry, connector change or warning suppression was made. Exact purchased mate/wiring and physical fit remain qualification gates.
- All 160 protected source/export/historical report files stayed byte-identical through verification.
- **Inherited stale evidence:** `housing/validation/input-geometry.json` was not updated by the prior compact delivery. It remains unchanged for provenance, not current compact evidence. Use `checks/current-input-geometry.json` and the fresh mechanical report. Historical carrier/body-layout documents also remain archival, not current assembly instructions.

### Repeat verification without replacing original evidence

```sh
/usr/bin/python3 scripts/freecad/recovery_verify.py electrical
/usr/bin/python3 scripts/r2/enclosure/extract.py
/usr/bin/python3 scripts/freecad/run.py scripts/freecad/recovery_verify.py mechanical
/usr/bin/python3 scripts/r2/enclosure/contact_audit.py
/usr/bin/python3 scripts/freecad/recovery_coherence.py
```

The mechanical command intentionally returns 1 while the conservative PH2 qualification gate remains open. The wrappers redirect report destinations only; recovered assertions are not weakened. Do not rerun destructive historical migration/layout scripts or `seal.py` over this evidence.

## FreeCAD assembly and desktop outcome

The recovered FCStd already has **7 independent movable `App::Part` display groups** — **Base, Lid, Main, Divider, Battery, Cables, Hardware** — containing **58 individually movable linked parts**. Fresh tests move each group and each individual link separately, confirm other groups/links and fixed engineering sources do not change, then restore without saving. All 65 movement checks pass (`checks/movement.json`). This is an inspection assembly, not a newly invented constrained mechanical redesign.

The actual desktop was initially visible, then capture failed with **PipeWire: Session creation inhibited**. A later native AX observation exposed **“Click or press a key to unlock”**. Therefore **the casing and controls were not opened/visually verified on the user's current desktop**. Do not treat the recovered screenshot as a new live capture. A FreeCAD `--help` startup probe was not a successful casing launch.

The existing local AppImage was SHA256-verified against the recovered runtime lock and extracted into this workspace without downloading or substituting a version. Runtime evidence is in `checks/runtime.json`.

Actual file:

```text
/home/azero/.okbrain/workspaces/smove-files/022/housing/smove-r2-enclosure.FCStd
```

After unlocking the desktop:

1. Open that FCStd in FreeCAD (the verified workspace launcher is `.tools/freecad/1.1.3/squashfs-root/AppRun`).
2. Use **Macro → Macros**, select `/home/azero/.okbrain/workspaces/smove-files/022/housing/InspectAssembly.FCMacro`, and **Execute**.
3. Click **Lift lid only**, **Explode all parts**, or choose a group, enter X/Y/Z offsets and click **Apply group offset**. Expand a display group to manipulate an individual linked part if needed.
4. Use **Restore ASSEMBLED** to reset display placements. Prefer a separate inspection copy if saving; do not overwrite the hash-preserved recovered original with an exploded pose.

Recovered original screenshot URL (historical, not a fresh desktop image):

`/uploads/7594e394-466d-4209-89a3-395642bcb4d2.webp`

Original image file: `housing/dist/freecad-inspection.png`.

Protected-cell charging/discharge/envelope, exact plug, print/fastener tolerances, stiffness, USB signal integrity, RF and thermal qualification remain open. This is a recovered engineering prototype, **not manufacturing approval**.

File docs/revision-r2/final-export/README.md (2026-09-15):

> **Historical/superseded topology.** Current integrated main-PCB design and release gates: [integrated ECO](../integrated/README.md). Carrier/PH4/old enclosure/count/hash claims below are archival, not current build instructions.

# Current R2 deliverables and reproduction

**Engineering prototype; manufacturing_release=false.** The current work implements a unified D1 schematic symbol and an actual coplanar/body-outward enclosure redesign. This supersedes the old cleanup-only/perpendicular-assembly status, not electrical, physical-fit or charging qualification limits. [Change record](../rgb-body/README.md), [main](../../../PCB/main/README.md), [housing / GUI](../../../housing/README.md).

## Electrical and retention regression

Run from the repository root with the system interpreter providing pcbnew:

```sh
/usr/bin/python3 scripts/r2/main/unify_rgb.py --check
/usr/bin/python3 scripts/r2/main/verify_rgb.py
/usr/bin/python3 scripts/r2/main/verify_button_labels.py
/usr/bin/python3 scripts/r2/enclosure/extract.py
/usr/bin/python3 scripts/r2/enclosure/contact_audit.py
/usr/bin/python3 scripts/r2/enclosure/audit_body_frame.py
```

The RGB verifier compares exact hierarchical net names/pin attributes and component UUIDs with saved pre-edit XML, reruns both boards' configured ERC/DRC/parity and verifies unchanged PCB/fabrication bytes. The four-page main schematic retains wired overview, USB, Power and Compute sheets. Carrier remains a separate single-root design. No DRC rule/severity changes or exclusions were added.

The legacy `main/verify.py` has **three inherited hierarchy-name assertion failures**; the pre/post result is recorded rather than silently normalizing net scopes. `package.py` also fails on inherited missing historical Markdown links. The scoped checks do not claim these full legacy scripts pass. Carrier standalone verification passes.

`contact_audit.py` screens pads, actual track/via shapes and stored copper fills against main retention lands and actual carrier annular seats. No new refill or inferred zero-sized components. The compact native mechanical receipt retains category counts, key checks and all failures; detailed zero-intersection rows are in ignored `.cache/housing/verification.json`.

## Regenerate only affected electrical presentation

```sh
/usr/bin/python3 scripts/r2/main/unify_rgb.py
/usr/bin/python3 scripts/r2/main/render_rgb.py
```

Local/embedded symbols update together. The crop is from KiCad's real SVG, not redrawn wiring. PDFs and SVG/PNGs contain all four main sheets. `scripts/r2/final/export.py` was corrected to retain all main pages and hash child/library sources; unrelated board fabrication/STEP outputs were not rebuilt for this ECO because the boards are byte-identical.

## Native FreeCAD regeneration and verification

The pinned official runtime is defined by `housing/toolchain.lock.json`. It was downloaded and verified in this workspace using publisher sidecar + official release metadata + pinned SHA256. No system package/version replacement was made.

```sh
/usr/bin/python3 scripts/freecad/bootstrap.py --verify-only
# On a fresh workspace without the pinned runtime, omit --verify-only to install it.
/usr/bin/python3 scripts/r2/enclosure/extract.py
/usr/bin/python3 scripts/freecad/run.py housing/entry.py generate
/usr/bin/python3 scripts/freecad/run.py housing/entry.py verify
```

Generation overwrites FCStd, two-part printable STEP/STLs and separate-solid assembly STEP; the source parameters and canonical PCB inputs are authoritative. Major case dimensions are editable in the spreadsheet; frozen outlines, fits and harness routes live in the generator. Arbitrary edits are not automatically requalified. Verification reopens/recomputes native solids and freshly imports STEP/STLs; ZIP CRC is not a substitute.

## FreeCAD GUI / review rendering

For ordinary inspection, open `housing/smove-r2-enclosure.FCStd`, then explicitly run `housing/InspectAssembly.FCMacro` from FreeCAD's Macro dialog. No downloads, saves, fabrication exports or fixed-source placement changes occur. Native MOVE THESE groups have lift/explode/restore, transparency and per-group XYZ controls. The shipped file defaults to **assembled**. [Instructions and screenshot](../../../housing/PRINTING-ASSEMBLY.md).

To rebuild the styled native document and review images after generation, close existing copies of the enclosure, then in the **real FreeCAD GUI Python console**:

```python
import sys
sys.path.insert(0, '/absolute/path/to/this/repository/scripts/r2/enclosure')
import present
document, panel = present.main()
```

This intentionally saves styled FCStd at assembled poses, renders `assembled/exploded/top/body-side/section/freecad-inspection.png`, and activates the delivered macro's actual Qt buttons for a GUI smoke test. `present.py` requires a real OpenGL display: the pinned headless Python runner's Qt offscreen backend cannot render this viewport. In this run the actual FreeCAD GUI was available on Xwayland; desktop-agent capture was inhibited, so no mouse-driven desktop review is claimed. Captured GUI and viewport images were visually inspected. Exploded offsets never change fixed CSG used for native checks/exports.

After GUI rendering, rerun native verify and `audit_body_frame.py` so receipts hash the styled FCStd, then reseal intended outputs:

```sh
/usr/bin/python3 scripts/freecad/run.py housing/entry.py verify
/usr/bin/python3 scripts/r2/enclosure/audit_body_frame.py
/usr/bin/python3 scripts/r2/final/package.py --seal
/usr/bin/python3 scripts/r2/main/verify_rgb.py
```

Keep disposable FreeCAD backups outside the deliverable tree before sealing. The package command seals design inventories before its inherited missing-link failure; this does **not** turn that command into a passing release check. No whole-repository ZIP, merge or manufacturing release.

All actual cable/crimp/slack, fit/preload/strength, magnetic/RF/thermal/USB/bench and on-body acceptance gates remain open. Qualified protected pack, supervised off-body charging and no TS cell-temperature monitoring remain required.

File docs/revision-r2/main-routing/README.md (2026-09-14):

# Main-board routing completion — review candidate

The authoritative PCB is `PCB/main/smove-r2-main.kicad_pcb`. This revision resumes the user's saved rotated-U8 routing, **not** the rejected USB seed. The latter generator is disabled.

## Verified result

- **0 DRC errors, 0 unconnected items, 0 schematic-parity issues, 0 ERC violations.**
- One unchanged warning: J2's battery-wire footprint differs from its library copy. No exclusions or rule weakening were added.
- **411 F.Cu segments, 104 B.Cu segments, 125 through vias, 47 footprints.**
- Every user USB data segment is preserved; the missing U1:26 → R3:2 connection is completed. The two old dangling D+ vias were removed. USB data remains entirely on F.Cu.
- U8 remains at the user's 90° orientation. **C7 alone is rotated 180°**, in place, to give its ground pad access to the connected ground pour and simplify its supply feed. All pad numbers/nets/sizes, other component placements, outline, antenna rules, IMU under-package keepout and reserved M3 regions are retained.
- Complex fanouts were placed with explicit coordinates. IMU SDA/power escapes and CC2 routing were moved to free the SCL route; VBUS and nearby ground stubs were changed to free the charger TS connection. No net was reassigned.
- A subsequent native-DRC-gated cleanup simplified 17 chains. Long BOOT and STRAP8 routes still take perimeter detours: connectivity and clean straight sections are verified, **global route-length optimality is not claimed**.

Evidence: [verification.json](verification.json), [DRC](drc.json), [ERC](erc.json), [cleanup](polish.json), [tool tests](tool-tests.txt), and [C7 comparison](c7-rotation-comparison.json). Comparison paths refer to temporary review copies, not release files.

## Plane selection

| Layer | Implemented use |
|---|---|
| F.Cu | Components, USB data, short local connections and selected signal bridges; connected GND pour |
| In1.Cu | Unbroken GND reference, one filled region; no routed traces |
| In2.Cu | Bounded 3V3_MAIN and PACK_P power-distribution regions, GND elsewhere; no routed traces |
| B.Cu | Signal routing and local power links, through-via transitions; connected GND pour |

The PACK_P region replaces the battery trunk that previously cut diagonally through the bottom routing area. Its upper end contacts J2's plated battery pad; its lower end feeds the charger/battery capacitor escape. The long thin PACK_P branch to R14 is the low-current voltage-sense branch, not the main charger feed. The 3V3 region distributes power on the left side without cutting the In1 reference.

A signal/GND/power/signal stack requires attention to reference-plane splits: bottom-side fast signals must not casually cross splits, and signal transitions need local return paths. Espressif recommends a complete GND reference and minimizing USB layer transitions; the power layer need not be indiscriminately divided into many rails. [source](https://docs.espressif.com/projects/esp-hardware-design-guidelines/en/latest/esp32c3/pcb-layout-design.html) [source](https://resources.altium.com/p/right-way-use-power-planes-4-layer-pcb-stackup)

Here USB remains on top, over In1 GND. Sampling its copper centerlines every 0.05 mm found **1,015 samples, zero uncovered**. This verifies reference coverage, not impedance or electromagnetic performance. Bottom I2C, configuration and control routes still require return-path/edge-rate review around the In2 power boundaries; no new fast USB routing was placed there.

The charger datasheet calls for short bypass loops, appropriately sized current paths and thermal-pad grounding. Four original thermal vias are retained; a final fabrication/thermal assessment is still required. [source](https://www.ti.com/lit/ds/symlink/bq24074.pdf)

## Reusable tools

See [scripts/pcb_tools/README.md](../../../scripts/pcb_tools/README.md):

- `waypoints` / `recipe`: exact coordinates, explicit vias and layers, selected copper removal and explicit footprint rotation; no pathfinding.
- `route`: exact two-pad routing, bend-aware search, short fanouts and bottom routing.
- `rotate`: isolated orientation/position comparisons with PNGs, DRC and approximate connection-length scores.
- `polish`: clearance-checked chain simplification with per-change connectivity/DRC rollback.
- 21 regression tests cover geometry, both routing layers, vias, locked copper, no partial insertion, stale plans and source/output guards. Orientation comparisons use isolated processes to avoid the installed native bindings' multi-board lifetime problems.

`manual-*.json` files are intermediate, UUID-specific audit recipes, not a regeneration pipeline. In particular, `manual-short-host.json` was an evaluated alternative **not adopted** because it increased detours. Do not replay recipes against the completed PCB.

Recheck the current board:

```sh
/usr/bin/python3 scripts/r2/main-routing/verify.py
PYTHONPATH=scripts /usr/bin/python3 -m unittest pcb_tools.test_tools -v
kicad-cli sch erc --format json --severity-all \
  -o docs/revision-r2/main-routing/erc.json PCB/main/smove-r2-main.kicad_sch
```

## Release limitations

This is a **routed review candidate, not a fabrication, assembly or charging release**. Native connectivity/DRC does not establish controlled USB impedance/skew, current capacity, RF/EMC performance, thermal margins, cell protection/temperature sensing or enclosure fit. Confirm the fabricator's actual stackup, via/plating and assembly requirements and review the relatively long low-speed detours before release. Existing `PCB/main/dist/` manufacturing outputs and enclosure openings are stale and were not regenerated. Firmware still needs the previously documented RED LED GPIO3 reassignment.

## Review images

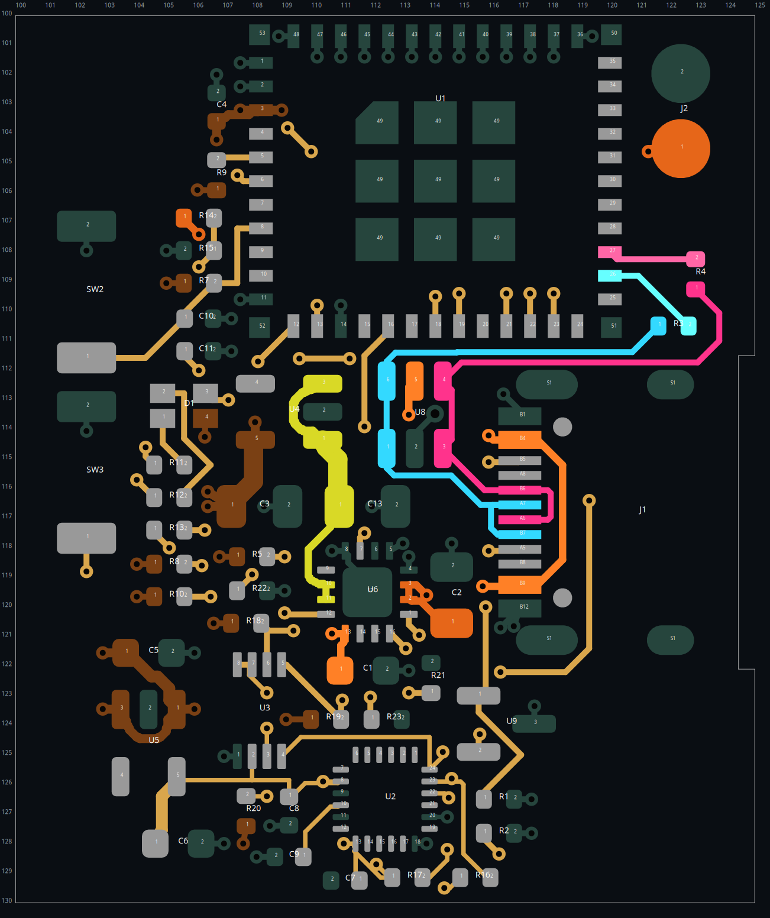
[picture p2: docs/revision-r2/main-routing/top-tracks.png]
Top tracks

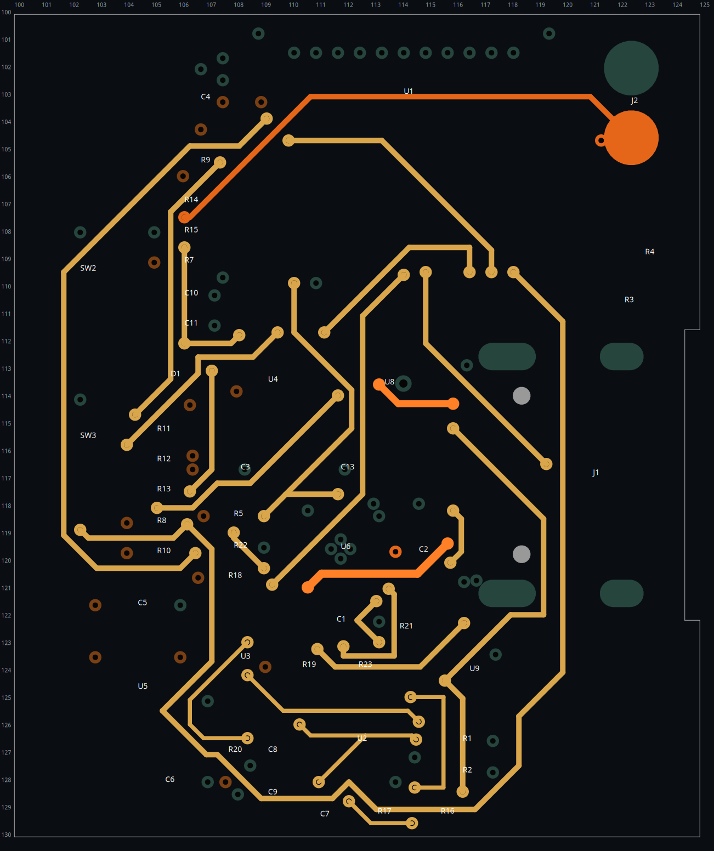
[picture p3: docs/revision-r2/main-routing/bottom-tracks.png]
Bottom tracks

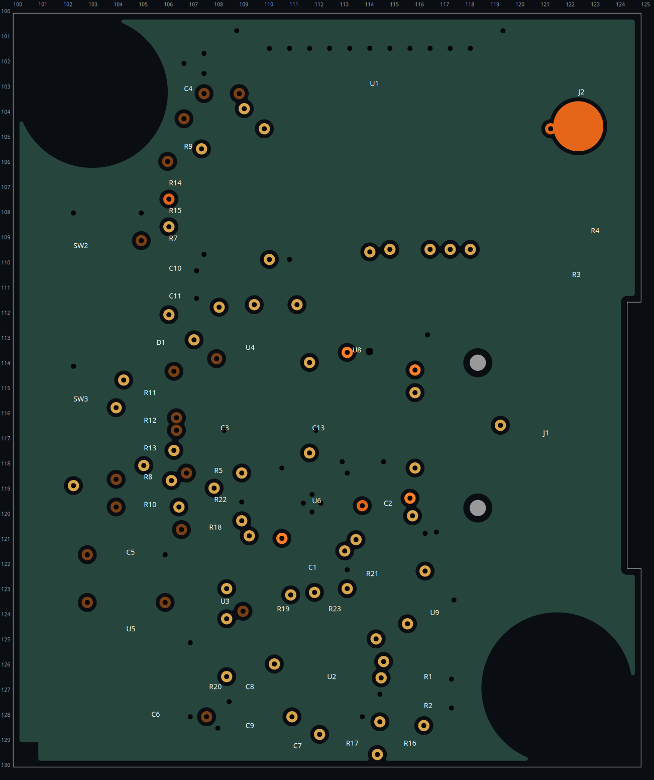
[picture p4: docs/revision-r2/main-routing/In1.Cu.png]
In1 GND

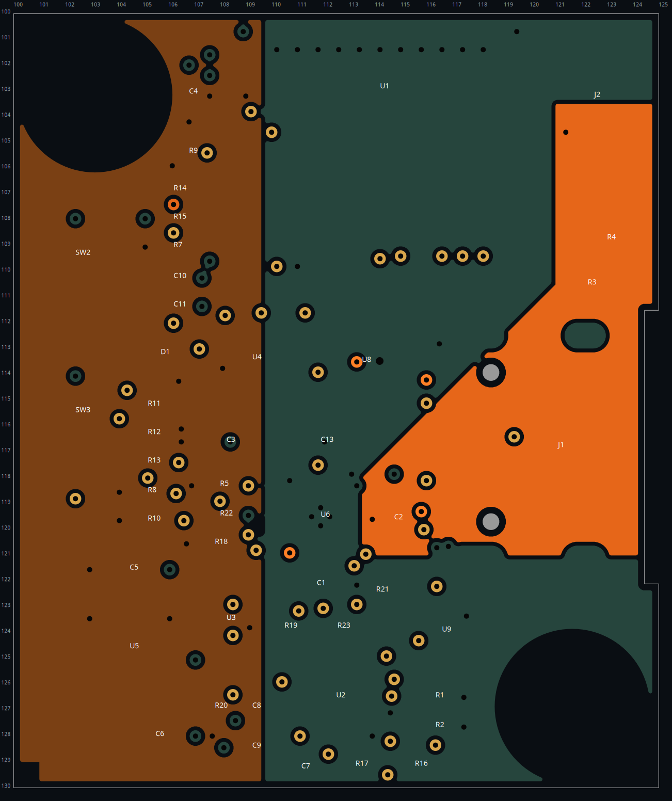
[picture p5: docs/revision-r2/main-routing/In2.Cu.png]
In2 power regions


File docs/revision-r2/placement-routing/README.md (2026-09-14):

# Grouped placement and routing study — UNROUTED REVIEW

**This is a placement-stage revision, not a completed reroute.** The working main PCB has been rearranged and the old copper routes removed instead of leaving tracks attached to the wrong pads. There are **152 unconnected items**. The copper-zone definitions are retained but unfilled; the proposed power-plane strategy below is **not implemented or electrically verified yet**. Do not fabricate, assemble or charge from this candidate.

Native file: `PCB/main/smove-r2-main.kicad_pcb`. Baseline: `7128028`. This work is isolated on the chat workspace branch; the original project directory and its locally modified project preferences were not overwritten. No enclosure or manufacturing exports have been regenerated.

## Placement delivered

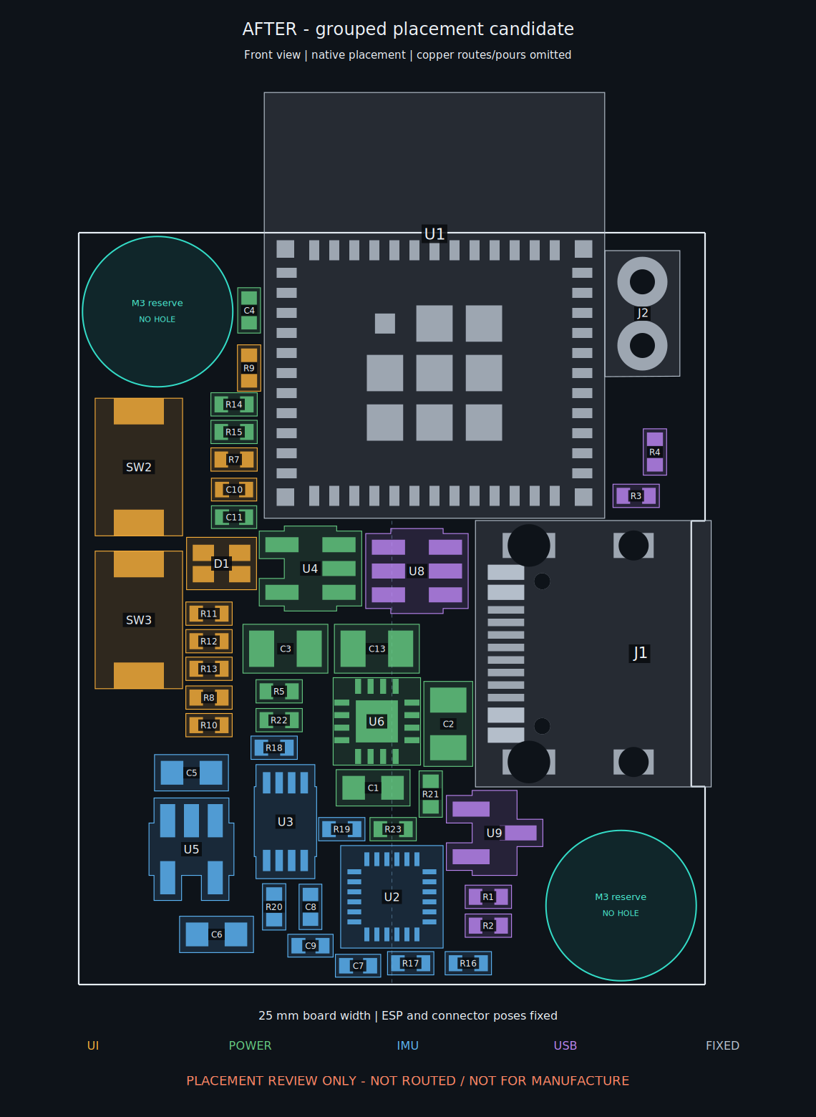
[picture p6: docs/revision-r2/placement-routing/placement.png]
Grouped front placement


- **Fixed:** U1 ESP32-C3-MINI-1, J1 USB-C, J2 battery connection, board outline, four-layer/1 mm nominal board, antenna exclusion and both M3 reserves. The reserves remain at `(103.15, 103.15)` and `(121.65, 126.85)` mm, each a 6 mm clear disk. **These are existing reserved positions, not actual drilled screw holes.** No holes were added or moved.
- **Upper left:** SW2 RESET and SW3 BOOT form a vertical column below the NW reserve. D1 and R11/R12/R13 sit beside it, close to the ESP's lower-left corner. R7/C10 and R8 stay with the reset/boot area. The native RESET silk is abbreviated `RST` to fit without reducing the configured minimum text height.
- **Power:** U4 and U6, C1/C2/C3/C13 and the charger programming/status resistors are grouped below the ESP and immediately left of USB. C4 remains beside the ESP supply input rather than being moved away with the charger. The ADC divider/filter is beside the ESP.
- **IMU:** U2 moves from `(112.5, 117.5)` to `(112.5, 126.5)` mm: **same centreline, 9 mm down, same −90° orientation and front-side +Z direction**. U3/U5 and all IMU capacitors/pull-ups form the lower sensor group. C7/C8/C9 are beside U2's VDD/VDDIO/REGOUT sides.
- **USB:** the USB connector and its data protection U8 retain their placements; R3/R4 remain beside the ESP's USB pins. CC protection U9 and R1/R2 are grouped below the connector, outside the SE screw reserve. The final CC routes must encounter the ESD protection before travelling into the circuit.
- All 47 references, component values, footprint types and assembly sides are retained. This is **repositioning**, not a component-substitution/BOM change.

`placements.csv` records every old/new coordinate and angle. `before.png` is the same style of unrouted-placement diagram for the baseline. These diagrams show native courtyard/pad positions, but simplify pad/drill drawing shapes; `placement-native.svg` is KiCad's actual native plot.

### Geometric evidence of grouping

These are footprint-origin distances, **not copper lengths**:

| Relationship | Before | After |
|---|---:|---:|
| Charger U6 to USB J1 | 20.922 mm | 9.588 mm |
| Charger U6 to regulator U4 | 15.602 mm | 6.651 mm |
| Charger U6 to SYS capacitor C13 | 16.720 mm | 2.900 mm |
| IMU U2 to level shifter U3 | 8.280 mm | 5.202 mm |

The summed Euclidean pad minimum-spanning-tree estimate, excluding GND/unconnected nets but including power nets, falls from **474.206 mm to 340.260 mm (about 28%)**. This is a placement proxy only: obstacles, layer changes, return paths, differential routing and manufacturability have not yet been accounted for by a completed route.

## Authorized LED pin reassignment

The user allowed ESP LED pin selection changes. Only **RED** is reassigned, to the available left-side GPIO3. GPIO3 is module pad 6; GPIO6 is module pad 20. The module datasheet and GPIO documentation identify GPIO2/8/9 as strapping pins, which this ECO does not repurpose. [source](https://documentation.espressif.com/esp32-c3-mini-1_datasheet_en.html) [source](https://docs.espressif.com/projects/esp-idf/en/stable/esp32c3/api-reference/peripherals/gpio.html)

| LED channel | Old ESP GPIO / module pad | New ESP GPIO / module pad | Series resistor |
|---|---|---|---|
| Red | GPIO6 / 20 | **GPIO3 / 6** | R11, unchanged 1 kΩ |
| Green | GPIO7 / 21 | GPIO7 / 21 | R12, unchanged 1 kΩ |
| Blue | GPIO10 / 16 | GPIO10 / 16 | R13, unchanged 1 kΩ |

GPIO6 is now explicitly no-connect. The compute schematic, local U1 symbol, embedded symbol cache, PCB pad nets, parts inventory and exported netlist agree. `native-layout-contract.json` also carries the revised poses, sensor origin, M3 reserve status and LED GPIO map; the separate old enclosure extraction snapshots remain stale. The common-anode connection stays 3V3_MAIN. No USB, I²C, ADC, EN, BOOT, power-status or strap assignment changes.

**Firmware handoff:** change the red LED pin from 6 to **3**. Green stays 7; blue stays 10. These are GPIO numbers, not module pad numbers. No firmware sources exist in this repository, so firmware was not changed. Review common-anode drive polarity when integrating the mapping.

## Researched routing strategy

### Four layers: continuous reference first, then short connections

| Layer | Proposed use for the reroute |
|---|---|
| F.Cu | Components, USB data pair and the shortest local IC/capacitor/signal connections; useful ground fill tied to In1. |
| In1.Cu | **Unbroken GND reference. No signal or power tracks.** Preserve the antenna and screw exclusions rather than filling them. |
| In2.Cu | **Power distribution regions**, mainly 3V3_MAIN, plus bounded local rails where needed; retain GND beneath sensitive/reference-critical regions. Avoid turning this into another general signal layer. |
| B.Cu | A small number of short secondary signal connections and ground fill. No new underside components. Each route needs a continuous adjacent reference and an appropriate return path. |

Espressif recommends top-side components/signals, a complete layer-2 ground plane, layer-3 power routing with ground retained for RF/crystal isolation, and limited bottom routing. Its guidance does **not** justify replacing every square millimetre of layer 3 with one power net. [source](https://docs.espressif.com/projects/esp-hardware-design-guidelines/en/latest/esp32c3/pcb-layout-design.html)

**Important qualification to “top and bottom for short wiring”:** short is not sufficient if the return current has to detour around a split. A bottom trace sees In2 first; if In2 is split into VBUS/BAT/SYS/3V3/1V8 regions, an arbitrary bottom trace can cross a broken reference. Keep USB on F.Cu over In1, keep other fast-edge traces over continuous reference copper, and reserve ground regions on In2 for necessary bottom routes. A GND via alone does not turn a split power plane into a continuous GND reference. TI explicitly warns against routing high-speed signals over plane splits/voids. [source](https://www.ti.com/lit/pdf/slla414)

The board only specifies nominal total thickness; a fabricator-qualified dielectric/copper stackup was not supplied. **Do not infer controlled impedance or trace-current capacity from the 1 mm total thickness or the existing default track settings.** Obtain the actual stackup before selecting USB pair width/gap and finishing power-path dimensions.

### Power routing and grounding

- Route `J1 VBUS → C1/U6 IN`, `J2 PACK_P → C2/U6 BAT`, `U6 OUT → C13/U4 IN`, and `U4 OUT → C3/3V3_MAIN` as compact power paths. Keep VBUS, PACK_P, SYS and 3V3 electrically distinct; do not assign them to one plane.
- Tie U6's exposed pad and VSS to the same GND potential, use thermal vias and real heat-spreading copper, and maintain a direct connection to the VSS pin. Place input/output/battery bypass capacitors close to their corresponding pins. TI's thermal-pad note explicitly says not to use the exposed pad as the sole primary ground input. [source](https://www.ti.com/lit/ds/symlink/bq24074.pdf)
- Keep the ISET/ILIM/TS small-signal ground paths away from high-current charge/discharge paths and join them at the IC's local ground region. This is **not** a reason to cut the board-wide In1 reference into analog/digital islands. TI recommends separating these current paths and using a single-point local ground technique. [source](https://www.ti.com/lit/ds/symlink/bq24074.pdf)
- Keep the 100 nF C4 at the module supply entrance; route the regulator's bulk output C3 and the module feed through a low-impedance distribution region. Use short capacitor-ground connections with adjacent return vias. Espressif recommends ground vias close to decoupling pads and multiple vias for main supply transitions; its main-supply trace-width guidance is a starting point, not a current/thermal sign-off for this assembled board. [source](https://docs.espressif.com/projects/esp-hardware-design-guidelines/en/latest/esp32c3/pcb-layout-design.html)
- The existing charger configuration, including the fixed TS resistor rather than a cell thermistor, is unchanged. Thermal, cell-protection, charging-current and worn-device qualification remain separate release gates.

### IMU routing

C7/C8/C9 must connect by short local traces to U2's VDD, VDDIO and REGOUT functions, with local ground returns. Keep the existing 1.8 V IO domain and U3 level shifting; ICM-20948 VDDIO is **not a 3.3 V domain**. Do not add a soldered exposed-pad connection under U2: TDK explicitly says the exposed die pad should not be soldered because of thermomechanical stress. [source](https://product.tdk.com/system/files/dam/doc/product/sensor/mortion-inertial/imu/data_sheet/ds-000189-icm-20948-v1.5.pdf)

Keep charger/battery high-current routes and their returns away from the U2 region, and keep outgoing/return current paths close together. Ground copper does not remove quasi-static magnetic interference from charging current or magnetic screws. Final screw material, battery contacts, USB shell and assembled magnetic calibration need review; NXP identifies screws, battery contacts and high-current traces as magnetometer interference sources. [source](https://www.nxp.com/company/about-nxp/smarter-world-blog/BL-MAGNETOMETER-PLACEMENT-WHERE-WHY) [source](https://www.nxp.com/docs/en/application-note/AN4247.pdf)

### USB and completion order

Route the USB pair first on top over uninterrupted In1 GND, through the protection footprint with no unnecessary stubs; preserve the separate MCU-side series-resistor nets. Espressif calls for a **90 Ω differential pair, ±10%**, parallel/equal-length routing, few layer changes, and ground-return vias at necessary transitions. Actual width/gap must come from the chosen stackup. [source](https://docs.espressif.com/projects/esp-hardware-design-guidelines/en/latest/esp32c3/pcb-layout-design.html)

After USB, finish the charger/regulator paths and decoupling, then the IMU's local connections, then I²C/control/LED signals. Add return/stitching vias deliberately, fill copper, inspect plane continuity, measure USB skew/impedance assumptions and power bottlenecks, and run ERC/DRC/parity again. **None of these routing-completion checks is replaced by the placement pass below.**

## Verification and reproducibility

Run the read-only native checker/report renderer (it writes reports, not the board):

```sh
/usr/bin/python3 scripts/r2/placement-routing/review.py
```

Fresh placement evidence reports:

- 47 references/values/footprint types retained; all components remain on the front.
- ESP/USB/battery positions and pad geometry unchanged; IMU centreline/orientation retained.
- Both M3 clear disks and all existing antenna/corner rule areas unchanged and clear.
- **No courtyard overlaps, no geometric DRC error-severity violations, no schematic parity issues, no ERC violations.**
- One existing warning: J2's embedded footprint differs from its library copy.
- **152 unconnected items; zero routed tracks/vias. NOT routing-complete.**

`verification.json`, `placement-drc.json`, `erc.json`, `netlist.xml` and `placements.csv` are the evidence. Board/source hashes bind the checks to this candidate. No rule severities, clearances, exclusions, project settings or unrelated schematics were weakened/changed.

For intentional regeneration only, `place.py INPUT OUTPUT` creates the placement from a preserved baseline and **removes all routes in OUTPUT**. It rejects identical input/output paths. Then run `led_pin.py` to apply the authorized net change, `sync_metadata.py` to refresh the handoff coordinates/pin map, and `review.py`. Do not run placement regeneration over later routing work. The old baseline remains recoverable from Git; no legacy routing/layout generator was run.

**Handoff status:** placement and research delivered; new copper routing, power-region implementation, fabrication outputs, enclosure LED/button openings and manufacturing/charging release remain outstanding.

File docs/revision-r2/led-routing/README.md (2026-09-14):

# LED routing on the user's revised layout

Base: `b155f033f849d78e28f899b0d9df355177c8b5ed` ("Add a different routing setup"). The native board is `PCB/main/smove-r2-main.kicad_pcb`.

## Changes

- Completed the three missing ESP32-to-resistor connections: U1.20 → R11.1 (red), U1.21 → R12.1 (green), U1.16 → R13.1 (blue). Existing R11/R12/R13-to-D1 cathode routes and D1.4 common-anode 3.3 V connection are preserved.
- Kept D1 at native `(109.725, 126.025)` mm, 90°, on the front. Relocation was not necessary; all 47 footprints, including the ESP32 and LED resistors, are exactly unchanged.
- Added 36 signal segments (0.15 mm), three signal vias (0.45 mm copper / 0.20 mm drill), and one GND stitching via at `(103.0, 123.7)` mm. The blue escape via is beside R13, **not in its solder pad**. Routing uses F.Cu, In2.Cu and B.Cu; no signal tracks were added on the In1 GND reference plane.
- The GND stitch connects the isolated R21/R23 front-copper region exposed by a fresh refill. No zone island-removal settings or electrical rules were relaxed.
- Removed the obsolete, open-ended BOOT branch that extended into the bottom-right screw reserve: 13 In2 segments, its redundant via, and four front escape segments back to the U1 pad. The working BOOT circuit is preserved and connectivity/parity verified. All other **1,072 existing track/via objects** are token-identical to the base.

## Screw space

Two rule areas now reserve a **6.0 mm diameter clear disk** for each future M3 mounting location:

| Location, viewed from front | Native centre (mm) | Rule area |
|---|---|---|
| Top left | X103.15, Y103.15 | `M3_NW_RESERVE` |
| Bottom right | X121.65, Y126.85 | `M3_SE_RESERVE` |

Both exclude tracks, vias, pads, copper pours and footprints on all four copper layers. The actual 96-sided keepout outline is circumscribed with a 0.005 mm radial allowance so polygon/nanometre rounding cannot encroach on the 6.0 mm clear disk. Verification checks actual tracks, pads, footprint courtyards and refilled copper against those disks.

**No mounting holes were drilled/added.** These are reserved positions, not a finalized fastener design. Hole diameter, screw head/washer envelope and enclosure alignment must be checked for the selected M3 hardware before manufacture. The antenna exclusion and the pre-existing corner keepouts are unchanged.

## Verification

Run from the repository root:

```sh
/usr/bin/python3 scripts/r2/main/verify_led_routing.py --output .cache/led-route/verification
```

The verifier compares exact native tokens to the base commit, checks net mappings and screw reserves, and runs fresh KiCad DRC with all track errors, all severities and schematic parity enabled.

| Check | Base | Routed board |
|---|---:|---:|
| Unconnected items | 3 (all LED) | **0** |
| DRC error-severity violations (excluding the separate unconnected list) | 0 | **0** |
| Schematic parity issues | 0 | **0** |
| Warnings | 8 | **3** |

The three remaining warnings are unchanged from the base:

- J2 embedded footprint differs from the library copy.
- Existing dangling USB CC2 via at `(116.25, 122.2)` mm.
- Existing dangling IMU SCL_1V8 track at `(115.3, 127.6)` mm.

See `baseline-drc.json`, `drc.json` and `verification.json`. No new exclusions, ignored severities or weakened clearances were introduced.

## Review images and release scope

The PNGs are native-geometry inspection diagrams with pours omitted for trace visibility: yellow highlights LED nets; teal circles indicate the nominal clear disks. They are not fabrication artwork. Native KiCad SVG plots include the actual copper pours.

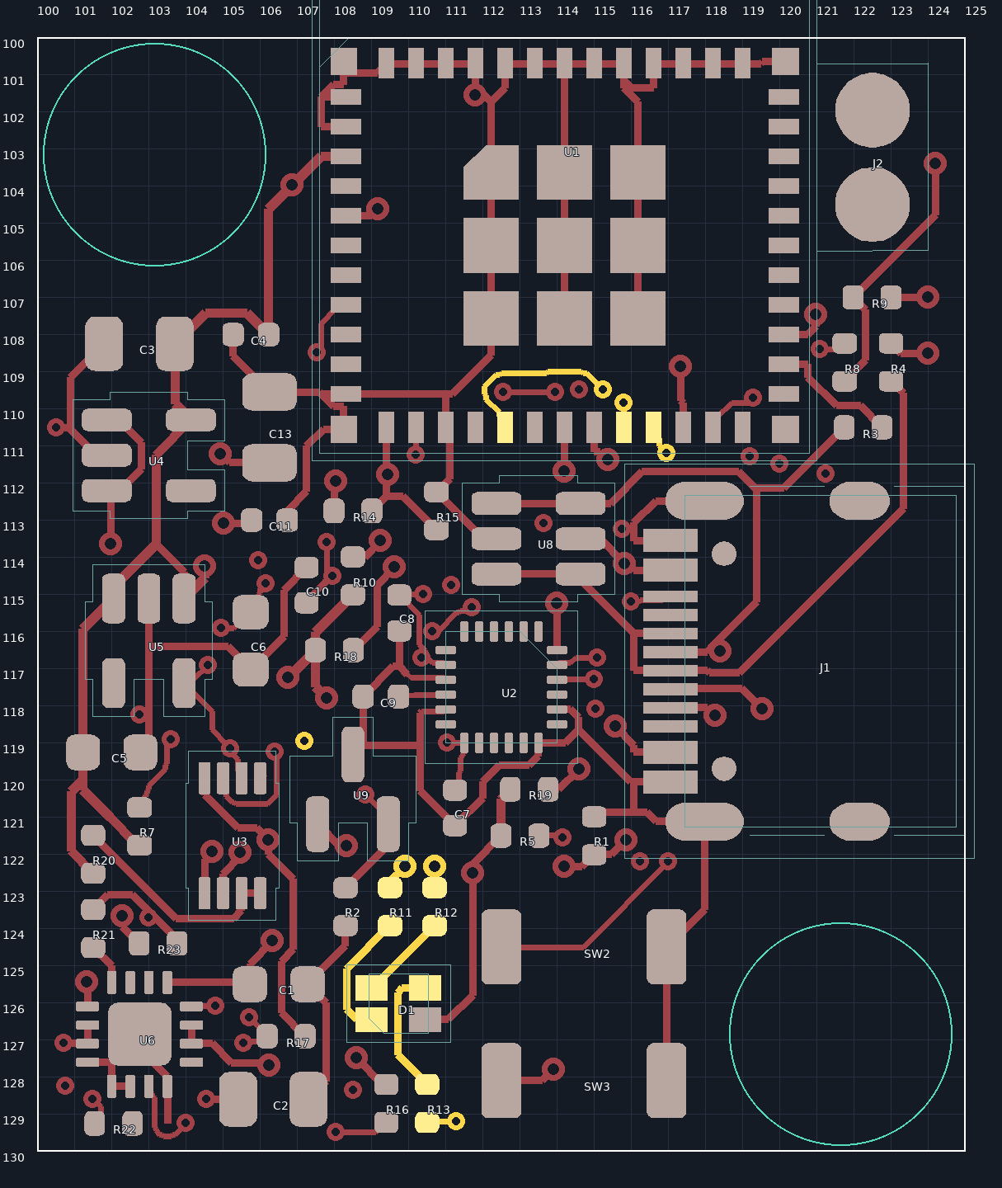
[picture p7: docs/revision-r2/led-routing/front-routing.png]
Front placement and LED routing


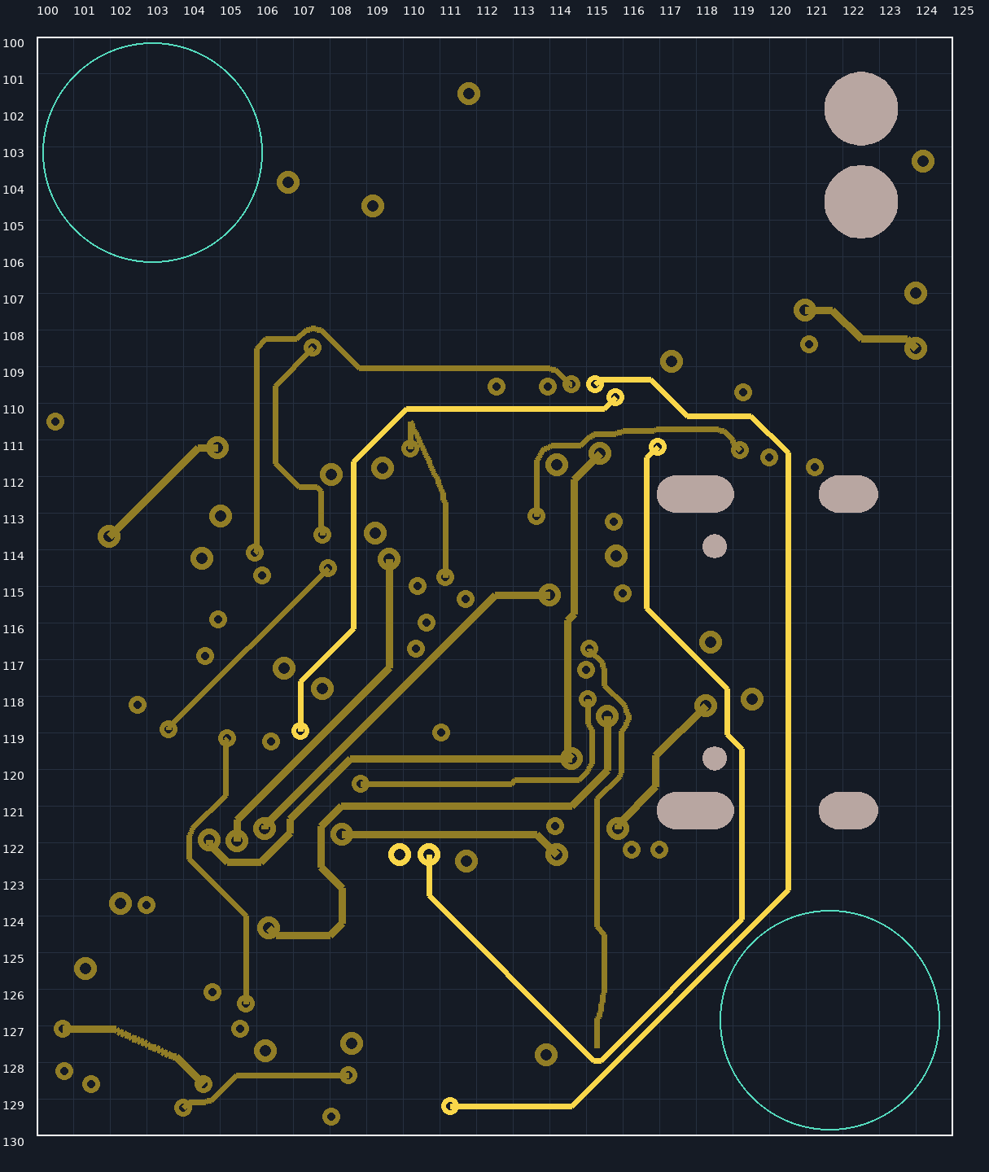
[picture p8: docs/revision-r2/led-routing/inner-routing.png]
Inner signal layer with completed LED routes


This is a native-PCB routing change, **not a manufacturing release**. Existing `PCB/main/dist/` Gerbers, assembly files, 3D exports and the enclosure describe older revisions and were not regenerated by this task. Do not manufacture from that old bundle; regenerate and review it from the updated board first. No enclosure files or schematic files were changed.

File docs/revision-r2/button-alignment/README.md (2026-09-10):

# RESET / BOOT physical alignment — historical predecessor

**Historical snapshot, superseded by [the screwless revision](../screwless/README.md).** Button coordinates remain accepted, but the screw/two-piece artifacts and counts below describe this older snapshot only.

Original review update; supersedes the previous byte-identical-PCB claim in the two-part-case delivery. Manufacturing and charging remain on hold.

| Switch | Previous native XY (mm) | Updated native XY (mm) |
|---|---|---|
| SW2 RESET | 121.50, 124.05 | 121.25, 124.25 |
| SW3 BOOT | 121.05, 128.00 | 121.25, 128.00 |

Both switches now share X=121.25 mm, with 3.75 mm center spacing. RESET moved slightly down to retain copper clearance; BOOT remains outside the southeast retention keepout. No tracks/vias were rerouted, no pad sizes/net assignments changed, and no design rules or schematic files changed. Copper zones were refilled. Both PCB labels are horizontal and centered on the same X axis; label placement is secondary to physical clearance.

The enclosure generator uses the updated native-board interface anchors. Both 3.3 mm lid openings are concentric with the switch axes: case XY (21.25,14.75) and (21.25,11.00) mm. Nominal material between openings is 0.45 mm; physical printing and actuation still require a trial. Base geometry, outer dimensions, battery allowance and H1 fastener location are unchanged.
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

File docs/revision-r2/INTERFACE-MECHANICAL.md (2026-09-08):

# Reusable IMU carrier contract / two-piece case handoff

**Historical pre-layout architecture handoff — not current geometry.** Native CAD now exists; dimensions and frame intentions in this old study are superseded by [the current assembly guide](../../housing/PRINTING-ASSEMBLY.md) and [the measured-from-artifacts alignment review](hierarchy-alignment/ALIGNMENT.md). The owner has since fixed main BOTTOM/base as body-facing; the actual coplanar redesign and explicit signed transforms are in those current records. Physical fit and calibration remain unqualified. This document originally froze electrical interface meaning, not unplaced dimensions.
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

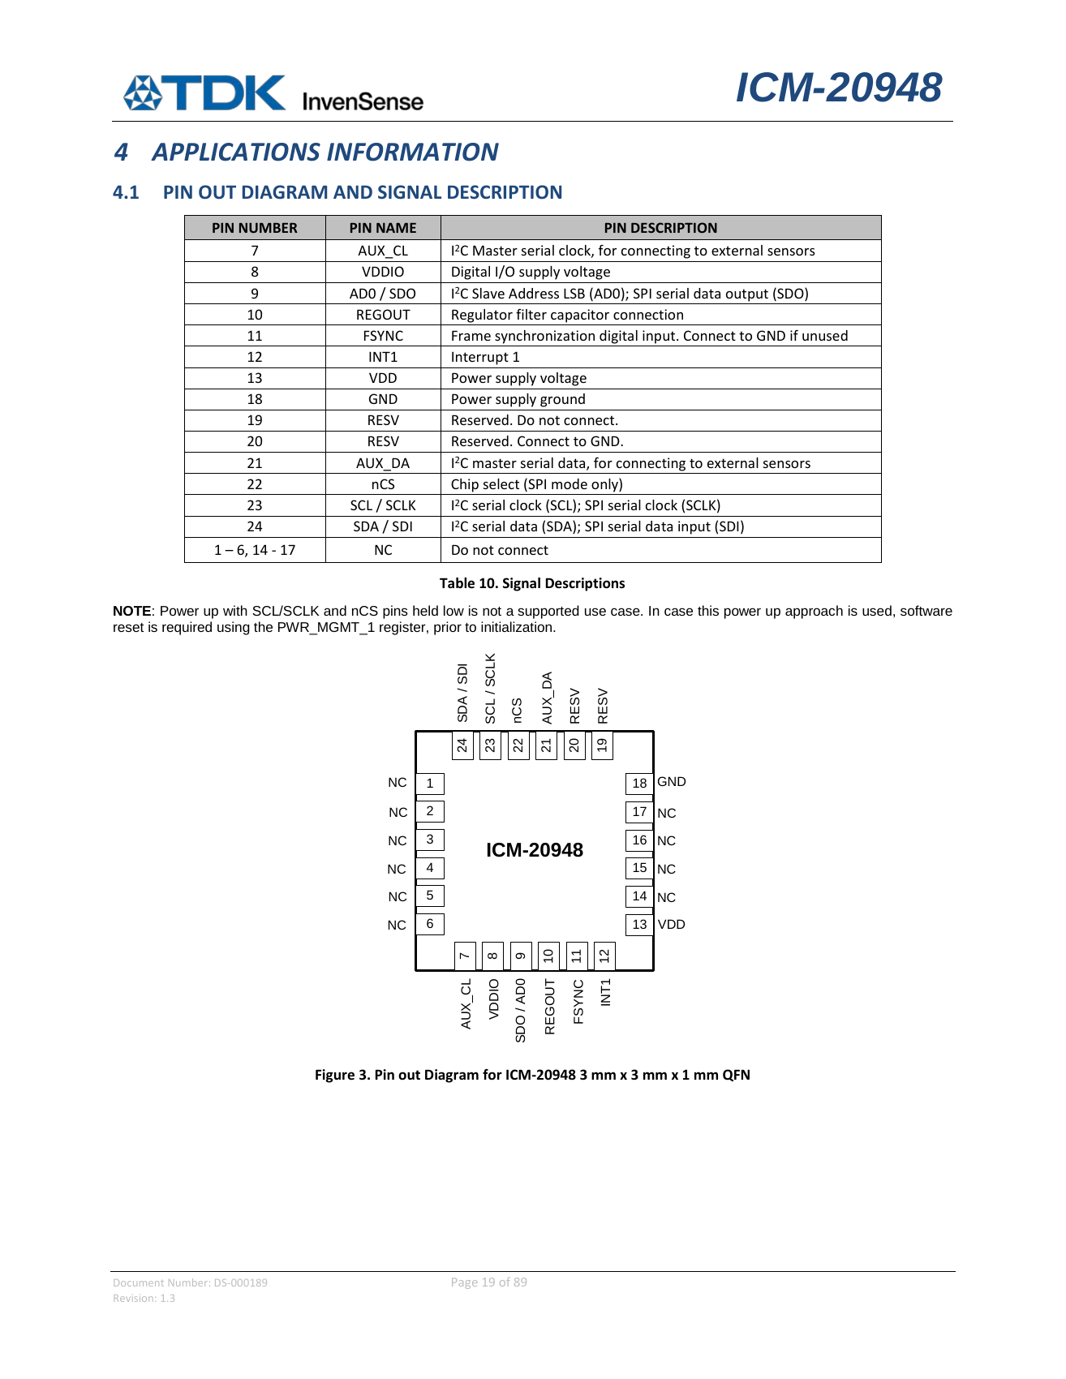
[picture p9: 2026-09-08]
docs/revision-r2/rgb-body/evidence/icm-pinout.png

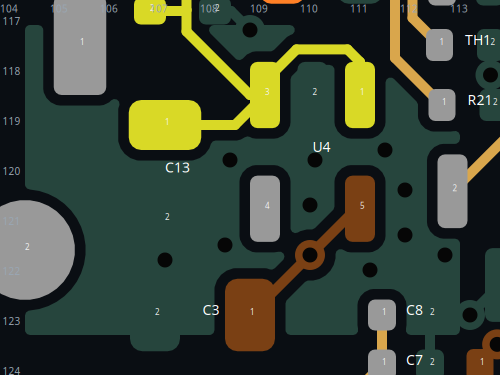
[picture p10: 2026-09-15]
docs/u4-thermal-eco/after-front.png

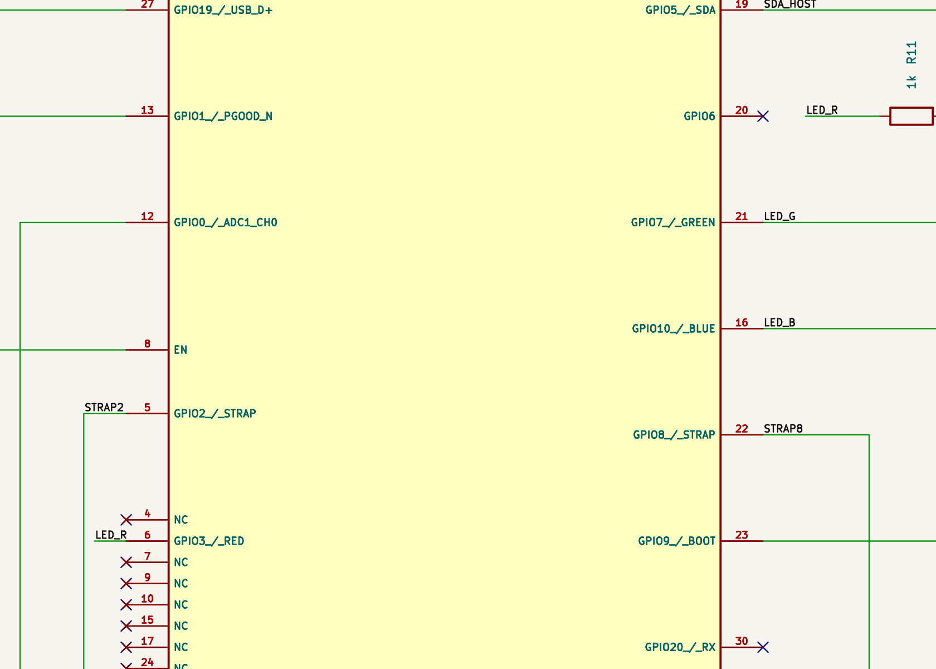
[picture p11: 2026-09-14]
docs/revision-r2/placement-routing/led-pin-change.png

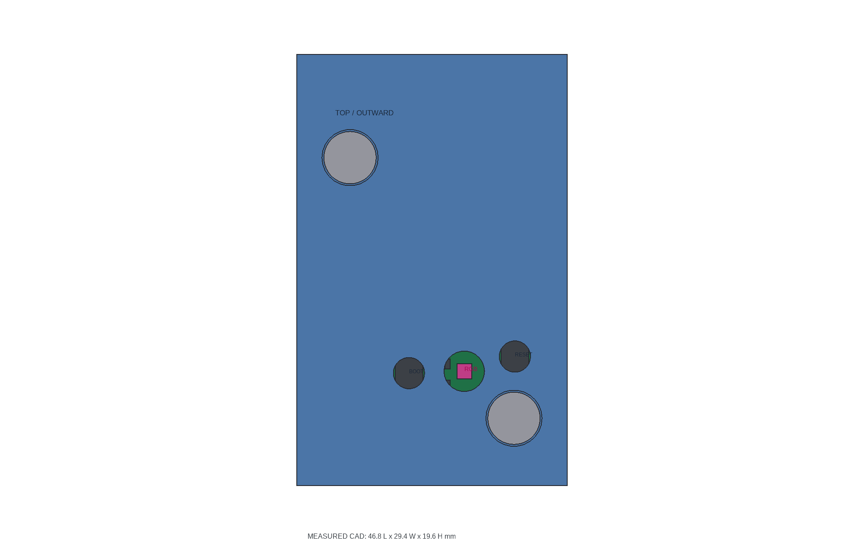
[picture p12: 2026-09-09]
docs/revision-r2/compact-placement/images/before-dimensions.png

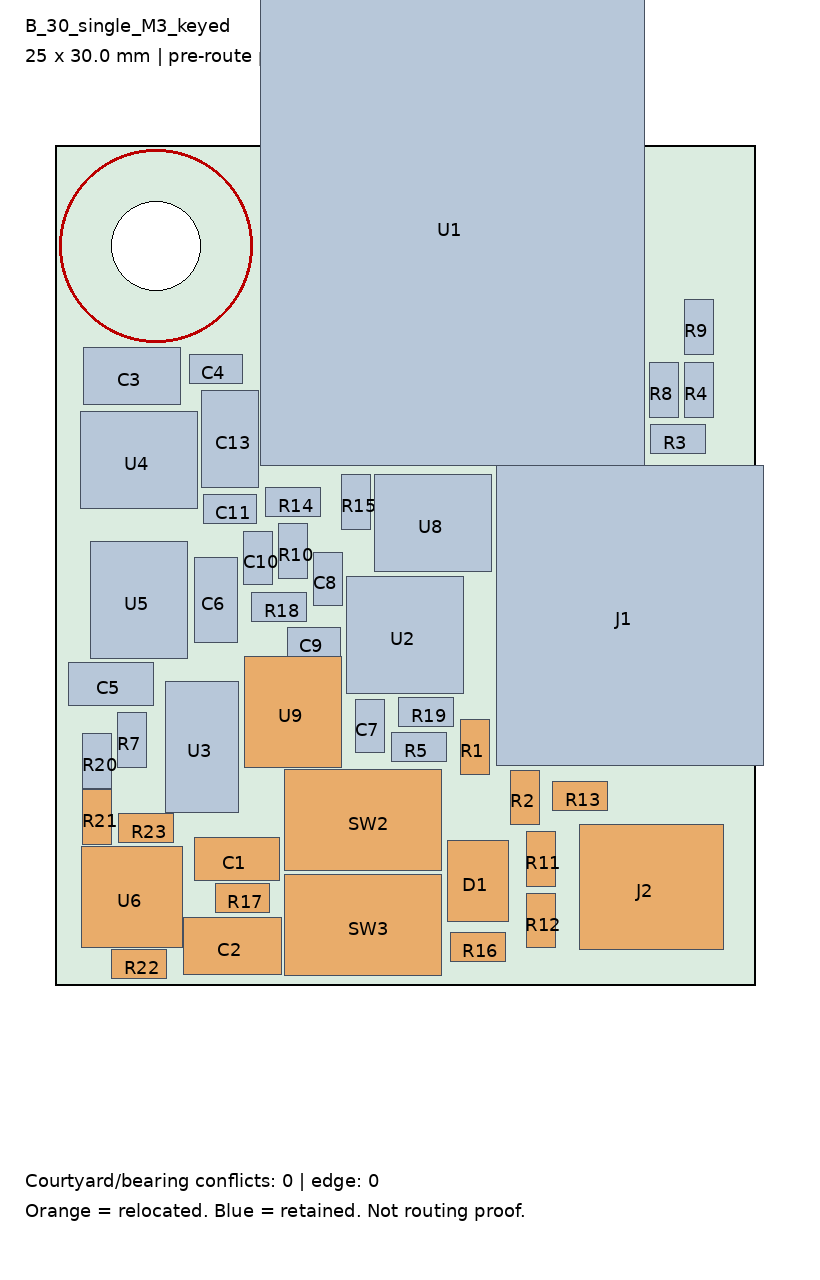
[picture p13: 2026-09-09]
docs/revision-r2/compact-placement/images/B_30_single_M3_keyed.png

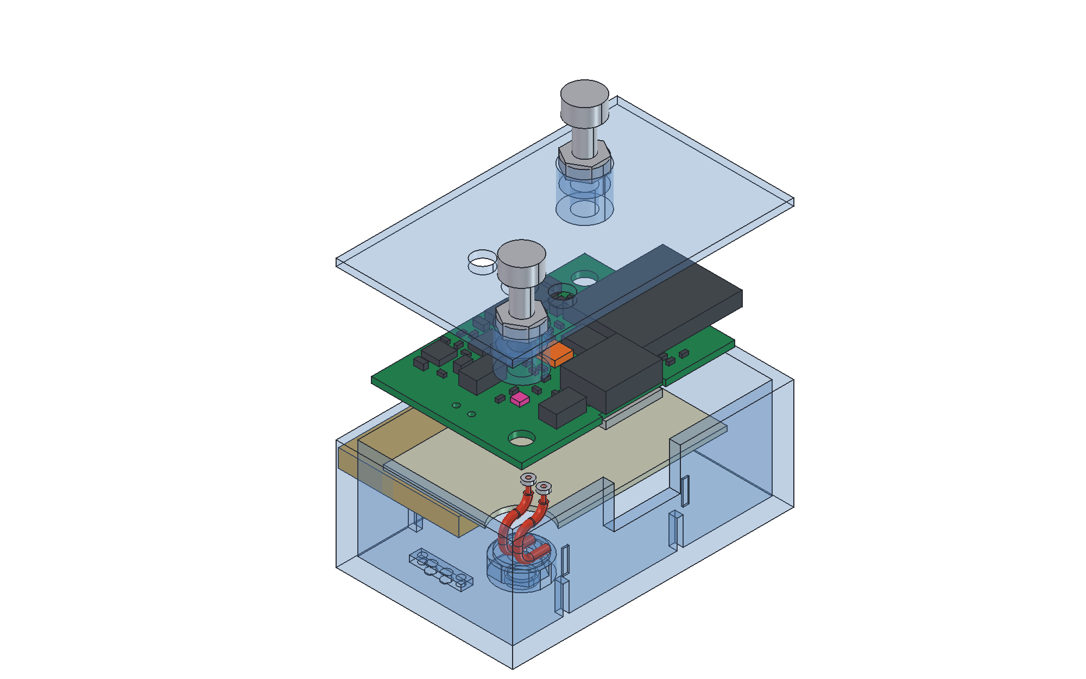
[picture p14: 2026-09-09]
docs/revision-r2/compact-placement/images/before-housing.png

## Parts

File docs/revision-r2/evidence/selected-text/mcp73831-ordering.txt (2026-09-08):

                                                                                                         MCP73831/2
PRODUCT IDENTIFICATION SYSTEM
To order or obtain information, e.g., on pricing or delivery, refer to the factory or the listed sales office.
  PART NO.            X             XX                X              /XX                 Examples: *
                                                                                        a)   MCP73831-2ACI/OT: 4.20V VREG,
                                                                                             Options AC, 5LD SOT23 package
    Device         VREG          Options Temperature Package                            b)   MCP73831T-2ACI/OT: Tape and Reel,
                                           Range                                             4.20V VREG, Options AC, 5LD SOT23 package
                                                                                        c)   MCP73832-2ACI/MC: 4.20V VREG,
                                                                                             Options AC, 8LD DFN package
  Device:               MCP73831:          Single-Cell Charge Controller                d)   MCP73832T-2ACI/MC: Tape and Reel,
                        MCP73831T:         Single-Cell Charge Controller                     4.20V VREG, Options AC, 8LD DFN package
                                           (Tape and Reel)
                        MCP73832           Single-Cell Charge Controller                a)   MCP73831-2ATI/OT: 4.20V VREG,
                        MCP73832T:         Single-Cell Charge Controller                     Options AT, 5LD SOT23 package
                                           (Tape and Reel)                              b)   MCP73831T-2ATI/OT: Tape and Reel,
                                                                                             4.20V VREG, Options AT, 5LD SOT23 package
                                                                                        c)   MCP73832-2ATI/MC: 4.20V VREG,
  Regulation            Code       VREG
                                                                                             Options AT, 8LD DFN package
  Voltage:
                                                                                        d)   MCP73832T-2ATI/MC: Tape and Reel,
                        2    =     4.20V                                                     4.20V VREG, Options AT, 8LD DFN package
                        3    =     4.35V
                        4    =     4.40V                                                a)   MCP73831-2DCI/OT: 4.20V VREG,
                        5    =     4.50V                                                     Options DC, 5LD SOT23 package
                                                                                        b)   MCP73831T-2DCI/OT: Tape and Reel,
                                                                                             4.20V VREG, Options DC, 5LD SOT23 package
  Options: *            Code       IPREG/IREG     VPTH/VREG    ITERM/IREG   VRTH/VREG   c)   MCP73832-2DCI/MC: 4.20V VREG,
                            AC         10            66.5          7.5        96.5           Options DC, 8LD DFN package
                            AD         10            66.5          7.5         94       d)   MCP73832T-2DCI/MC: Tape and Reel,
                            AT         10            71.5          20          94            4.20V VREG, Options DC, 8LD DFN package
                            DC         100            x            7.5        96.5
                                                                                        a)   MCP73831-3ACI/OT: 4.35V VREG,
                        * Consult Factory for Alternative Device Options                     Options AC, 5LD SOT23 package
                                                                                        b)   MCP73831T-3ACI/OT: Tape and Reel,
  Temperature           I        = -40C to +85C (Industrial)                               4.35V VREG, Options AC, 5LD SOT23 package
  Range:                                                                                c)   MCP73832-3ACI/MC: 4.35V VREG,
                                                                                             Options AC, 8LD DFN package
                                                                                        d)   MCP73832T-3ACI/MC: Tape and Reel,
  Package:              MC       = Dual-Flat, No-Lead (2x3 mm body), 8-Lead                  4.35V VREG, Options AC, 8LD DFN package
                        OT       = Small Outline Transistor (SOT23), 5-Lead
                                                                                        a)   MCP73831-4ADI/OT: 4.40V VREG,
                                                                                             Options AD, 5LD SOT23 package
                                                                                        b)   MCP73831T-4ADI/OT: Tape and Reel,
                                                                                             4.40V VREG, Options AD, 5LD SOT23 package
                                                                                        c)   MCP73832-4ADI/MC: 4.40V VREG,
                                                                                             Options AD, 8LD DFN package
                                                                                        d)   MCP73832T-4ADI/MC: Tape and Reel,
                                                                                             4.40V VREG, Options AD, 8LD DFN package

                                                                                        a)   MCP73831-5ACI/OT: 4.50V VREG,
                                                                                             Options AC, 5LD SOT23 package
                                                                                        b)   MCP73831T-5ACI/OT: Tape and Reel,
                                                                                             4.50V VREG, Options AC, 5LD SOT23 package
                                                                                        c)   MCP73832-5ACI/MC: 4.50V VREG,
                                                                                             Options AC, 8LD DFN package
                                                                                        d)   MCP73832T-5ACI/MC: Tape and Reel,
                                                                                             4.50V VREG, Options AC, 8LD DFN package

                                                                                        * Consult Factory for Alternate Device Options

 2005-2020 Microchip Technology Inc.                                                                                  DS20001984H-page 26

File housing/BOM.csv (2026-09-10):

Item | Qty | Description | Acceptance
Midframe | 1 | White nonconductive print with separator and battery/PCB locators and internal perimeter wire corridor plus antenna cap floor | Support removal and fit trial required
Top cover | 1 | White nonconductive print with sleeve snap grooves and flush USB/button/LED access plus antenna cap roof | Retention cycles and creep and access gauges required
Bottom cover | 1 | White nonconductive print with sleeve snap grooves | No pouch preload; retention qualification required
PCB land films | 4 | 0.2mm dielectric film; west0.7x2 and east0.9x2 contact areas | Measure coplanarity and abrasion
PCB adhesive or shim | 4 | 0.2mm controlled nonconductive adhesive OR dielectric shim | Optional bonding; no glue on solder/pads/vias
Pack floor liner | 1 | 21x31x0.2mm smooth dielectric film | No burrs or pouch seal pressure
Battery | 1 | Unqualified 30x20x3mm candidate; complete allowance31x21x4.3mm | Actual pack exit/swelling/protection/charging qualification required
Battery leads | 2 | Conditional OD<=1.2mm and R2 centreline bends; no gauge selected | Actual bend rating and polarity and pull/flex test required
Wire strain-relief adhesive | as qualified | Nonconductive compatible adhesive on vertical midframe land; bond process unqualified | No adhesive type or bond process approved

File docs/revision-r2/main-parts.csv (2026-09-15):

refs | quantity | mpn | manufacturer | jlc | value | package | purpose | notes | board
U1 | 1 | ESP32-C3-MINI-1-N4 | Espressif Systems | C2838502 | ESP32-C3-MINI-1-N4 | Espressif MINI-1 13.2x16.6mm | Wireless/native USB | N4 specifically; Standard Only/MSL3/X-ray; all-layer antenna keepout | main
U4 | 1 | XC6220B331MR-G | Torex Semiconductor | C86534 | XC6220B331MR-G | SOT-25 | Main 3.3V LDO | IN/CE from BQ OUT/SYS; 20mV@100mA and 60mV@300mA dropout (VOUT=3.0V test point), 8uA PS / 50uA HS quiescent; SOT-25 pin map 1=VIN 2=VSS 3=CE 4=NC 5=VOUT matches the AP2112K it replaces (no pad remap); SOT-25 Pd 250mW standard board - keep (VIN-VOUT)xIOUT inside it, PD/thermal + burst qualification still mandatory; schematic ECO 2026-09-15, PCB not yet updated | main
U6 | 1 | BQ24074RGTR | Texas Instruments | C54313 | BQ24074RGTR | VQFN-16 RGT 3x3mm + EP | 4.2V power-path charger | USB100 fixed; OUT feeds LDO; default timers; 10k TS bias means NO cell-temperature sensing | main
U8 | 1 | USBLC6-2SC6 | STMicroelectronics | C7519 | USBLC6-2SC6 | SOT-23-6 | USB data/VBUS ESD | Rail clamp to VBUS, not 3V3; no sustained overvoltage guarantee | main
U9 | 1 | PESD5V0S2BT,215 | Nexperia | C49338 | PESD5V0S2BT,215 | SOT-23 | CC1/CC2 ESD | One dual array, not duplicate TVS layers | main
J1 | 1 | TYPE-C-31-M-12 | Korean Hroparts Elec | C165948 | TYPE-C-31-M-12 | HRO USB-C 16-contact SMT with shell anchors | Single USB port | Native USB data plus charge input; no PD | main
J2 | 1 | S2B-PH-SM4-TB(LF)(SN) | JST | C295747 | S2B-PH-SM4-TB(LF)(SN) | JST PH 2.0mm right-angle SMT | Protected-pack connection | Pin1 PACK_P; pin2 GND; verify mating polarity; 5.8mm height reserve | main
SW2 SW3 | 2 | TS-1088-AR02016 | XUNPU | C720477 | TS-1088-AR02016 | 4x3mm SMT | Reset and boot/user buttons | Verify contact-pair footprint mapping; preserve separate physical actions | main
SW1 | 1 | off-board toggle switch | n/a |  | Off-board pack toggle switch | SOT-25 (SOT-23-5 body; JEDEC MO-178 Var AA) two-pad wire block | Hard pack cutoff in the J2 + lead | NOT a JLC part and excluded from BOM/pos: user-supplied off-board switch wired to the same 2.54mm wire-pad footprint as J2; require >=0.5A rating, contacts <50mOhm, >=6V DC; contact resistance adds directly to the pack IR drop | main
D1 | 1 | LTST-C19HE1WT | Lite-On | C458749 | LTST-C19HE1WT | 1.6x1.6mm 4-pad RGB | RGB status | Common anode; 1k per cathode; low-current indication; off while charging | main
R1 R2 | 2 | 0402WGF5101TCE | UNI-ROYAL(Uniroyal Elec) | C25905 | 5.1k 1% | 0402 | USB-C Rd | Separate CC resistors; never join CC1 and CC2 | main
R3 R4 | 2 | 0402WGF220JTCE | UNI-ROYAL(Uniroyal Elec) | C25092 | 22R 1% | 0402 | USB series damping | Near MCU, one per data line; validate signal integrity | main
R5 R14 R15 R24 | 4 | 0402WGF1003TCE | UNI-ROYAL(Uniroyal Elec) | C25741 | 100k 1% | 0402 | USB valid-power pull-up; battery ADC divider; charger-status pull-up | R5 pulls BQ PGOOD to 3V3 for GPIO1; R14/R15 PACK_P/2 to GPIO0; R24 pulls BQ CHG_N to 3V3 for GPIO6; no raw VBUS GPIO | main
R7 R8 R9 R10 R23 | 5 | 0402WGF1002TCE | UNI-ROYAL(Uniroyal Elec) | C25744 | 10k 1% | 0402 | EN and GPIO9/2/8 pulls; charger TS bias | R23 TS-to-GND is manufacturer-permitted NO-temperature-sensing bias, not a thermistor | main
R11 R12 R13 | 3 | 0402WGF1001TCE | UNI-ROYAL(Uniroyal Elec) | C11702 | 1k 1% | 0402 | RGB current limiting | No LED on boot-strapping pins | main
R22 | 1 | 0402WGF4701TCE | UNI-ROYAL(Uniroyal Elec) | C25900 | 4.7k 1% | 0402 | I2C pull-ups and charger ILIM | R16/R17 low side; R18/R19 high side; R22 ILIM-to-GND required even in fixed USB100 mode | main
R21 | 1 | 0402WGF8201TCE | UNI-ROYAL(Uniroyal Elec) | C25924 | 8.2k 1% | 0402 | BQ fast-charge programming | 108.5mA nominal before input limiting; actual USB input <=100mA including system; validate qualified cell | main
C1 | 1 | CL10A475KO8NNNC | Samsung Electro-Mechanics | C19666 | 4.7uF 16V X5R 10% | 0603 | VBUS bypass and 1.8V LDO input/output | Bias/stability gates; C5/C6 effective >=1uF; C1 USB attach/stability test | main
C2 C13 | 2 | CL21A476MQYNNNE | Samsung Electro-Mechanics | C16780 | 47uF 6.3V X5R 20% | 0805 | BQ BAT and SYS reservoirs | C2 PACK_P at 4.23V; C13 SYS at 4.5V max. Exact Samsung biased-capacitance screen closed; see FINAL-ELECTRICAL.md. | main
C3 | 1 | CL21A226MAQNNNE | Samsung Electro-Mechanics | C45783 | 22uF 25V X5R 20% | 0805 | 3V3 reservoir at MCU/LDO output | JLC Basic (no extended-part setup fee); 25V replaces the earlier 10V part; require >=10uF effective at 3.3V plus burst test, and re-run the DC-bias screen plus a pocket-height check | main
C4 C11 | 2 | CL05B104KO5NNNC | Samsung Electro-Mechanics | C1525 | 100nF 16V X7R 10% | 0402 | Local bypass, IMU REGOUT and ADC filter | C7 VDD; C8 VDDIO; C9 REGOUT; C11 battery ADC | main
C10 | 1 | CL05A105KA5NQNC | Samsung Electro-Mechanics | C52923 | 1uF 25V X5R 10% | 0402 | MCU EN reset RC | 10k nominal RC ~10ms; bias tolerance/timing bench check | main
J4 | 1 | S4B-PH-SM4-TB(LF)(SN) | JST | C265102 | S4B-PH-SM4-TB(LF)(SN) | JST PH 2.0mm 1x4 side-entry SMT | Reusable carrier interface | Main J4 / carrier J5; 1=3V3 2=GND 3=SDA 4=SCL; PHR-4 keyed housing; <=50mm straight-through harness; local variant/pitch/polarity/availability pending | main

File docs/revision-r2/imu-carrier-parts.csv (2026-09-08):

refs | quantity | mpn | manufacturer | jlc | value | package | purpose | notes | board
U2 | 1 | ICM-20948 | TDK InvenSense | C726001 | ICM-20948 | TDK 24-pad 3x3x1mm | Integrated nine-axis IMU | VDD and VDDIO both 1.8V; exact manufacturer land pattern; lifecycle risk | imu-carrier
U3 | 1 | PCA9306DCUR | Texas Instruments | C33196 | PCA9306DCUR | VSSOP-8 DCU | I2C 1.8V/3.3V translation | VREF2 tied EN; 200k to 3V3, NOT directly to 3V3 | imu-carrier
U5 | 1 | AP2112K-1.8TRG1 | Diodes Incorporated | C176944 | AP2112K-1.8TRG1 | SOT-25 | IMU 1.8V LDO | Input and enable 3V3; same supply for IMU VDD/VDDIO | imu-carrier
R16 R17 R18 R19 | 4 | 0402WGF4701TCE | UNI-ROYAL(Uniroyal Elec) | C25900 | 4.7k 1% | 0402 | I2C pull-ups and charger ILIM | R16/R17 low side; R18/R19 high side; R22 ILIM-to-GND required even in fixed USB100 mode | imu-carrier
R20 | 1 | 0402WGF2003TCE | UNI-ROYAL(Uniroyal Elec) | C25764 | 200k 1% | 0402 | PCA9306 bias | 3V3 to joined VREF2/EN | imu-carrier
C5 C6 | 2 | CL10A475KO8NNNC | Samsung Electro-Mechanics | C19666 | 4.7uF 16V X5R 10% | 0603 | VBUS bypass and 1.8V LDO input/output | Bias/stability gates; C5/C6 effective >=1uF; C1 USB attach/stability test | imu-carrier
C7 C8 C9 | 3 | CL05B104KO5NNNC | Samsung Electro-Mechanics | C1525 | 100nF 16V X7R 10% | 0402 | Local bypass, IMU REGOUT and ADC filter | C7 VDD; C8 VDDIO; C9 REGOUT; C11 battery ADC | imu-carrier
J5 | 1 | S4B-PH-SM4-TB(LF)(SN) | JST | C265102 | S4B-PH-SM4-TB(LF)(SN) | JST PH 2.0mm 1x4 side-entry SMT | Reusable carrier interface | Main J4 / carrier J5; 1=3V3 2=GND 3=SDA 4=SCL; PHR-4 keyed housing; <=50mm straight-through harness; local variant/pitch/polarity/availability pending | imu-carrier

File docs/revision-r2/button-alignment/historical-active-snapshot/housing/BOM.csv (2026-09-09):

Item | Qty | Description | Acceptance
Base | 1 | Nonconductive printed base with integral battery ceiling and central nut boss and solid corner seats | Print bridge and nut roof stiffness/gauges required
Lid | 1 | Nonconductive printed lid with central bearing and integral entry skirt | Fit and low-preload creep qualification required
Screw | 1 | ONLY M3x8 ISO4762 socket cap through H1; max head5.68x3 | Length7.71..8.29mm; shank<=3.00mm; no released torque
Nut | 1 | M3 hex AF5.5x2.4 envelope in central front-entry pocket | Verify thread/chamfer and pocket fit
Floor liner | 1 | Smooth insulating film21.6x31.8x0.2mm | No sharp edges or pouch preload
Seat liners | 4 | Smooth insulating film0.95x1.8x0.2mm front and0.95x2x0.2mm rear | Coplanar supports; no PCB preload
Battery | 1 | Unqualified candidate body30x20x3mm | Complete pack<=31x21x4.3mm; NOT charging approved
User-routed leads | not modeled | No wire specification or dedicated space supplied | User chooses and verifies route/strain relief/polarity; avoid RF and pinching

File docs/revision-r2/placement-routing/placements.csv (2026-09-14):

reference | value | group | old_x_mm | old_y_mm | old_deg | old_layer | new_x_mm | new_y_mm | new_deg | new_layer
C1 | 4.7uF / 16V | POWER | 106.5 | 125.5 | 0.0 | F.Cu | 111.75 | 122.15 | 0.0 | F.Cu
C10 | 1uF / 25V | UI | 107.25 | 114.75 | 90.0 | F.Cu | 106.2 | 110.25 | 0.0 | F.Cu
C11 | 100nF / 16V | POWER | 106.25 | 113.0 | 0.0 | F.Cu | 106.2 | 111.35 | 0.0 | F.Cu
C13 | 47uF / 6.3V | POWER | 106.25 | 110.5 | 90.0 | F.Cu | 111.9 | 116.6 | 0.0 | F.Cu
C2 | 47uF / 6.3V | POWER | 106.35 | 128.6 | 0.0 | F.Cu | 114.75 | 119.6 | 90.0 | F.Cu
C3 | 22uF / 10V | POWER | 102.75 | 108.25 | 180.0 | F.Cu | 108.25 | 116.6 | 0.0 | F.Cu
C4 | 100nF / 16V | POWER | 105.75 | 108.0 | 180.0 | F.Cu | 106.8 | 103.1 | 90.0 | F.Cu
C5 | 4.7u / 16V X5R | IMU | 102.0 | 119.25 | 0.0 | F.Cu | 104.5 | 121.55 | 0.0 | F.Cu
C6 | 4.7u / 16V X5R | IMU | 105.75 | 116.25 | -90.0 | F.Cu | 105.5 | 128.0 | 0.0 | F.Cu
C7 | 100n / 16V | IMU | 111.25 | 120.75 | -90.0 | F.Cu | 111.15 | 129.25 | 0.0 | F.Cu
C8 | 100n / 16V | IMU | 109.75 | 115.5 | -90.0 | F.Cu | 109.25 | 126.9 | -90.0 | F.Cu
C9 | 100n / 16V | IMU | 109.25 | 117.75 | 180.0 | F.Cu | 109.25 | 128.449999 | 180.0 | F.Cu
D1 | LTST-C19HE1WT / CA | UI | 109.725 | 126.025 | 90.0 | F.Cu | 105.7 | 113.2 | 90.0 | F.Cu
J1 | TYPE-C-31-M-12 | FIXED | 121.1 | 116.8 | 90.0 | F.Cu | 121.1 | 116.8 | 90.0 | F.Cu
J2 | Battery wire pads 2.54mm | FIXED | 122.5 | 103.23 | 90.0 | F.Cu | 122.5 | 103.23 | 90.0 | F.Cu
R1 | 5.1k | USB | 115.0 | 121.5 | 90.0 | F.Cu | 116.35 | 126.5 | 0.0 | F.Cu
R10 | 10k | UI | 108.5 | 114.5 | 90.0 | F.Cu | 105.2 | 119.65 | 0.0 | F.Cu
R11 | 1k | UI | 109.5 | 123.41 | -90.0 | F.Cu | 105.2 | 115.2 | 0.0 | F.Cu
R12 | 1k | UI | 110.7 | 123.41 | -90.0 | F.Cu | 105.2 | 116.3 | 0.0 | F.Cu
R13 | 1k | UI | 110.5 | 128.71 | 90.0 | F.Cu | 105.2 | 117.4 | 0.0 | F.Cu
R14 | 100k | POWER | 108.5 | 112.75 | 0.0 | F.Cu | 106.2 | 106.85 | 0.0 | F.Cu
R15 | 100k | POWER | 110.75 | 112.75 | 90.0 | F.Cu | 106.2 | 107.95 | 180.0 | F.Cu
R16 | 4.7k 1% | IMU | 109.4 | 128.71 | 90.0 | F.Cu | 115.55 | 129.15 | 0.0 | F.Cu
R17 | 4.7k 1% | IMU | 106.7 | 126.9 | 0.0 | F.Cu | 113.25 | 129.15 | 0.0 | F.Cu
R18 | 4.7k 1% | IMU | 108.0 | 116.5 | 0.0 | F.Cu | 107.8 | 120.55 | 0.0 | F.Cu
R19 | 4.7k 1% | IMU | 113.25 | 120.25 | 0.0 | F.Cu | 110.5 | 123.8 | 0.0 | F.Cu
R2 | 5.1k | USB | 108.3 | 123.41 | -90.0 | F.Cu | 116.35 | 127.65 | 0.0 | F.Cu
R20 | 200k 1% | IMU | 101.5 | 122.0 | 90.0 | F.Cu | 107.8 | 126.9 | 90.0 | F.Cu
R21 | 8.2k | POWER | 101.5 | 124.0 | 90.0 | F.Cu | 114.05 | 122.4 | 90.0 | F.Cu
R22 | 4.7k | POWER | 102.05 | 129.25 | 0.0 | F.Cu | 108.0 | 119.45 | 0.0 | F.Cu
R23 | 10k | POWER | 103.25 | 124.4 | 0.0 | F.Cu | 112.55 | 123.8 | 0.0 | F.Cu
R3 | 22R | USB | 122.25 | 110.5 | 0.0 | F.Cu | 122.25 | 110.5 | 0.0 | F.Cu
R4 | 22R | USB | 123.0 | 108.75 | 90.0 | F.Cu | 123.0 | 108.75 | 90.0 | F.Cu
R5 | 100k | POWER | 113.0 | 121.5 | 0.0 | F.Cu | 108.0 | 118.3 | 0.0 | F.Cu
R7 | 10k | UI | 102.75 | 121.25 | 90.0 | F.Cu | 106.2 | 109.05 | 0.0 | F.Cu
R8 | 10k | UI | 121.75 | 108.75 | 90.0 | F.Cu | 105.2 | 118.55 | 0.0 | F.Cu
R9 | 10k | UI | 122.49 | 107.0 | 0.0 | F.Cu | 106.8 | 105.4 | 90.0 | F.Cu
SW2 | RESET | UI | 114.725 | 124.5 | 0.0 | F.Cu | 102.4 | 109.35 | 90.0 | F.Cu
SW3 | BOOT / USER | UI | 114.725 | 128.1 | 0.0 | F.Cu | 102.4 | 115.45 | 90.0 | F.Cu
U1 | ESP32-C3-MINI-1-N4 | FIXED | 114.2 | 102.9 | 0.0 | F.Cu | 114.2 | 102.9 | 0.0 | F.Cu
U2 | ICM-20948 | IMU | 112.5 | 117.5 | -90.0 | F.Cu | 112.5 | 126.5 | -90.0 | F.Cu
U3 | PCA9306DCUR | IMU | 105.25 | 121.5 | -90.0 | F.Cu | 108.25 | 123.5 | 90.0 | F.Cu
U4 | AP2112K-3.3TRG1 | POWER | 103.0 | 111.25 | 0.0 | F.Cu | 109.25 | 113.4 | 180.0 | F.Cu
U5 | AP2112K-1.8TRG1 | IMU | 103.0 | 116.25 | -90.0 | F.Cu | 104.5 | 124.6 | -90.0 | F.Cu
U6 | BQ24074RGTR | POWER | 102.75 | 126.85 | 0.0 | F.Cu | 111.9 | 119.5 | 180.0 | F.Cu
U8 | USBLC6-2SC6 | USB | 113.5 | 113.5 | 0.0 | F.Cu | 113.5 | 113.5 | 0.0 | F.Cu
U9 | PESD5V0S2BT,215 | USB | 108.5 | 120.25 | 90.0 | F.Cu | 116.6 | 123.95 | 0.0 | F.Cu

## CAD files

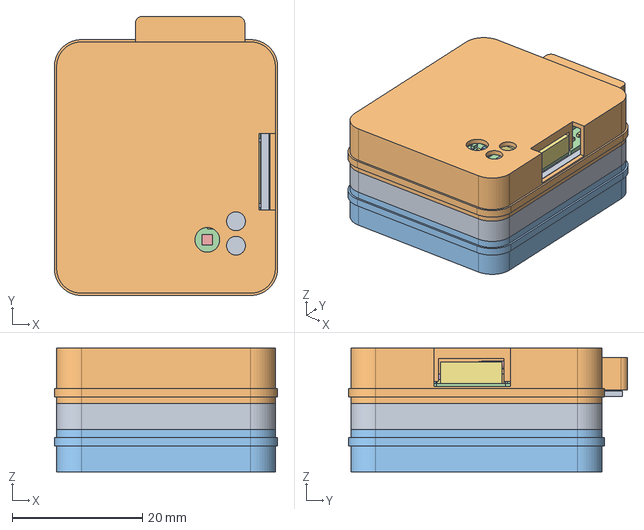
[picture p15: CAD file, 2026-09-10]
housing/dist/smove-r2-assembly.step
34.3 x 42.9 x 19.0 mm

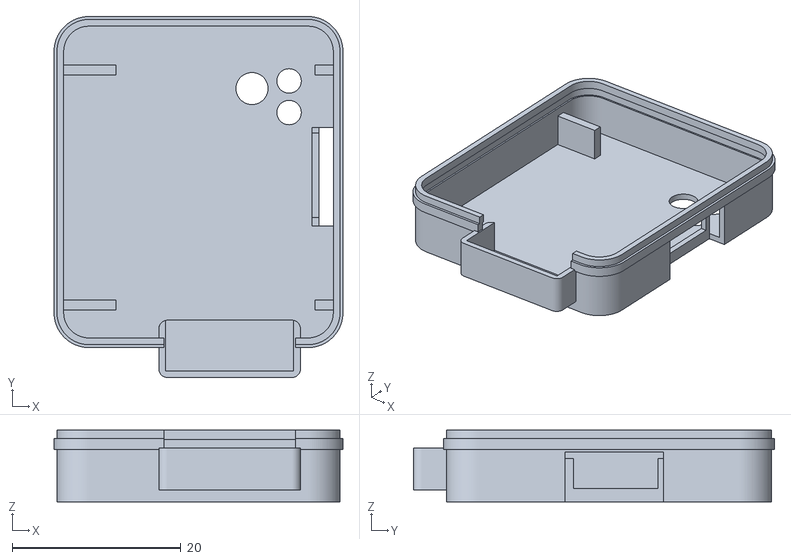
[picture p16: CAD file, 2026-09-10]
housing/dist/top-cover.stl
34.3 x 42.8 x 8.50

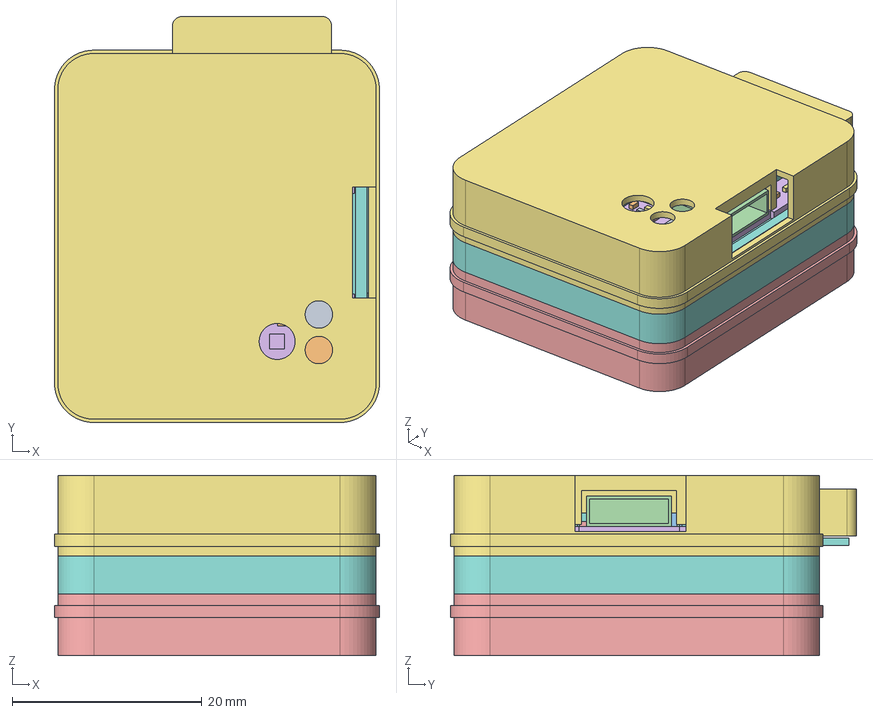
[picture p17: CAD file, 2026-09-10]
housing/smove-r2-enclosure.FCStd
34.3 x 42.8 x 19.0 mm
Dielectric1
Dielectric2
Dielectric3
Dielectric4
BOTTOM | white | body-facing
MainPCB
Component_R9
Component_U5
Component_SW2
Component_R4
Component_C10
Component_R17
Component_C8
Component_D1
Component_U2
Component_C4
Component_R5
Component_C7
Component_R23
Component_U3
Component_C9
Component_R3
Component_R18
Component_R2
Component_R15
Component_C3
Component_R7
Component_U4
Component_R8
Component_C5
Component_C6
Component_U1
Component_C1
Component_R10
Component_C13
Component_R13
Component_R22
Component_R20
Component_R19
Component_U9
Component_U6
Component_R12
Component_U8
Component_R11
Component_R1
Component_C2
Component_R16
Component_C11
Component_R21
Component_SW3
Component_R14
USBSourceShell
BatteryCandidate
PackFloorInsulator
TOP | RF TEST PROTOTYPE | protected antenna cap | flush USB
MIDFRAME | continuous pack barrier | internal perimeter wires | cap floor
BATSolderReserve1
BATSolderReserve2

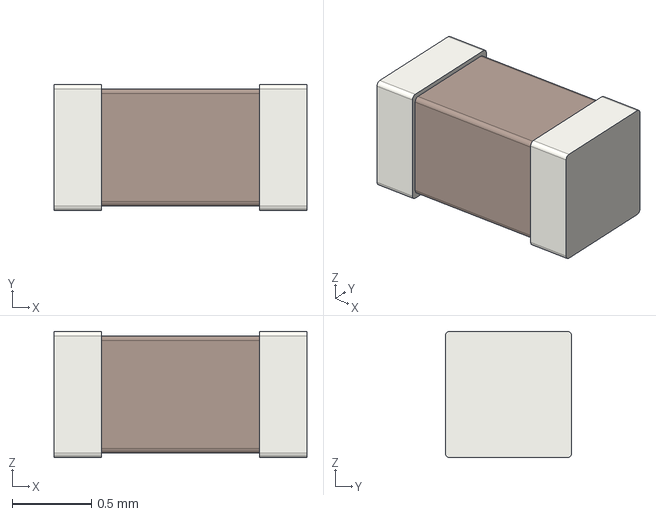
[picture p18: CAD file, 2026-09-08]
PCB/main/assets/imu-models/C_0603_1608Metric.step
1.60 x 0.8 x 0.8 mm

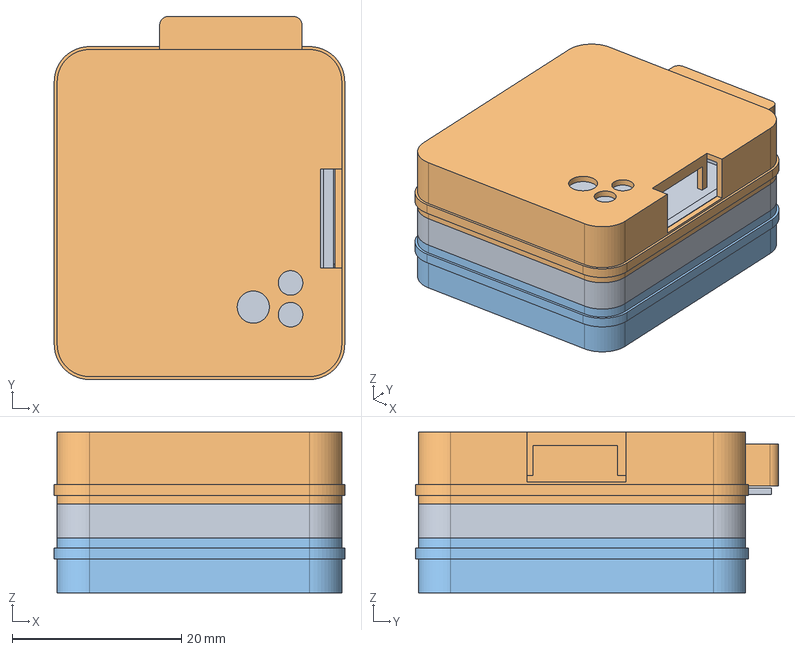
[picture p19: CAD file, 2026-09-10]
housing/dist/smove-r2-printable.step
34.3 x 42.9 x 19.0 mm

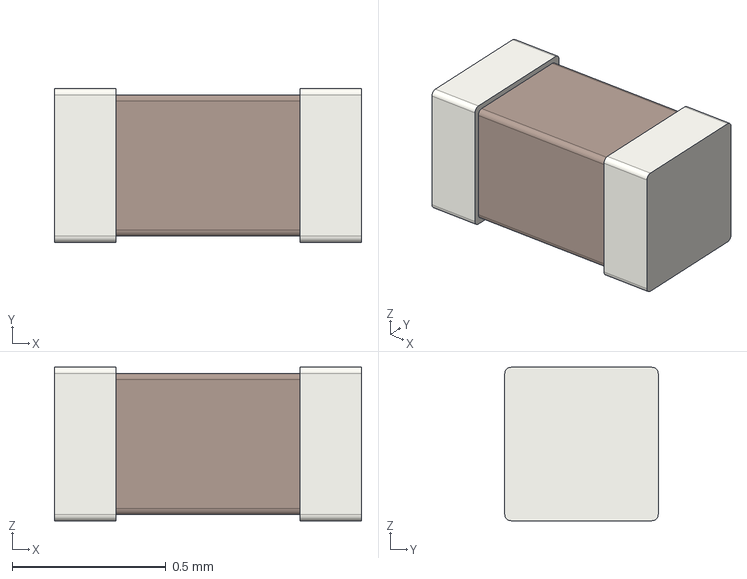
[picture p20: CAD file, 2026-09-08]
PCB/main/assets/imu-models/C_0402_1005Metric.step
1.00 x 0.5 x 0.5 mm

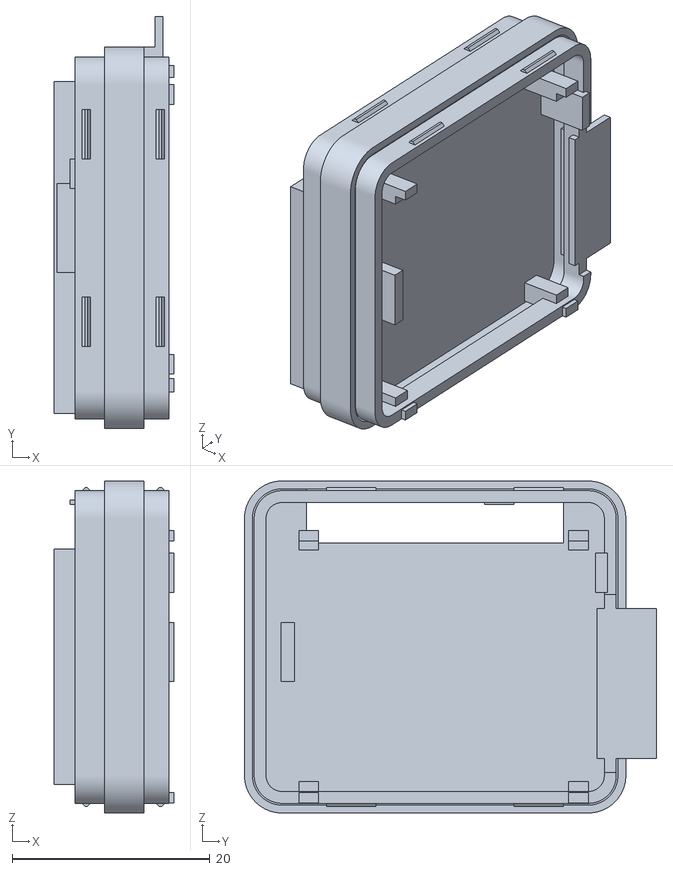
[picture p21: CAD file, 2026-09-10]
housing/dist/midframe.stl
12.1 x 41.7 x 33.6

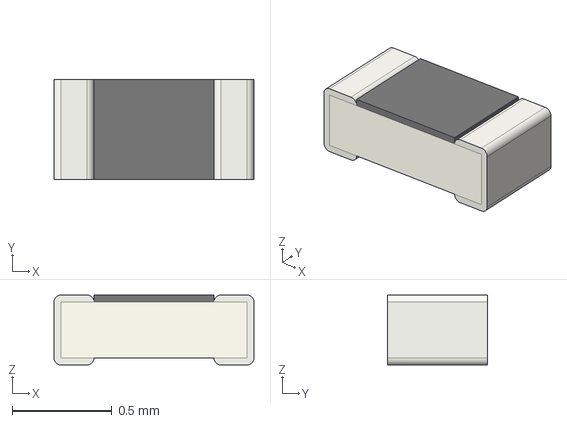
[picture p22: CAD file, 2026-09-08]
PCB/main/assets/imu-models/R_0402_1005Metric.step
1.00 x 0.5 x 0.35 mm

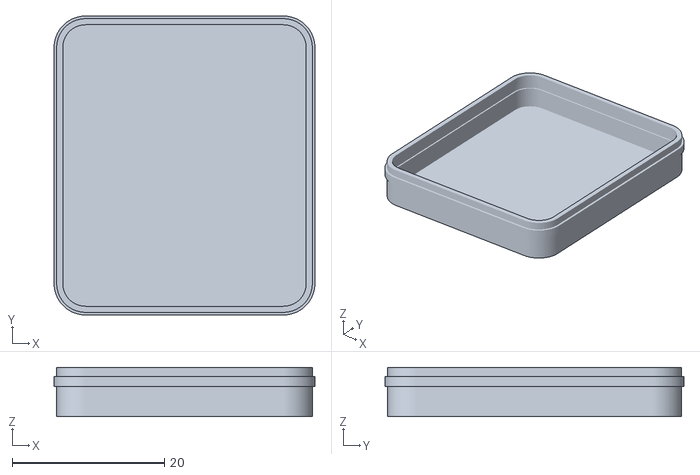
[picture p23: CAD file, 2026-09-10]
housing/dist/bottom-cover.stl
34.3 x 39.3 x 6.50

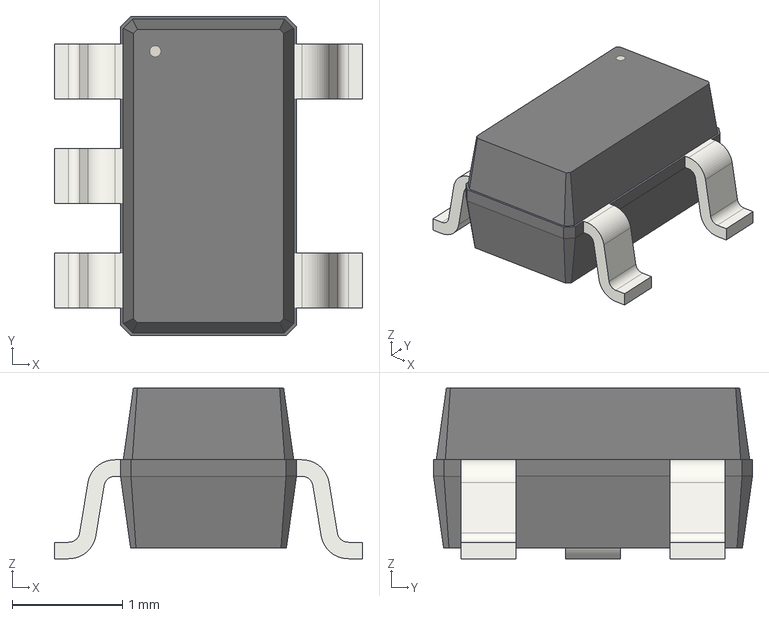
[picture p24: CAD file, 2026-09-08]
PCB/main/assets/imu-models/SOT-23-5.step
2.80 x 2.90 x 1.55 mm

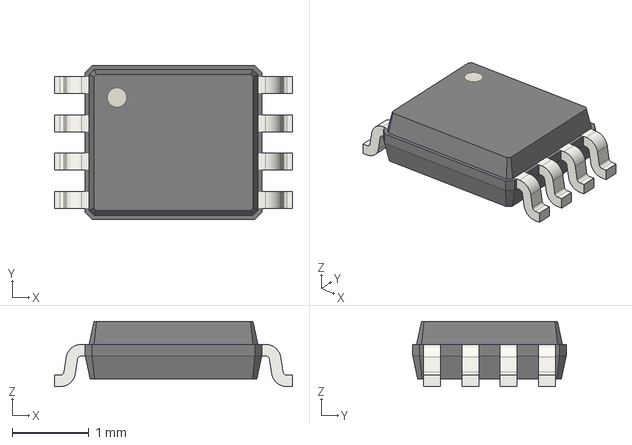
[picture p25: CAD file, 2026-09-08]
PCB/main/assets/imu-models/VSSOP-8_2.3x2mm_P0.5mm.step
3.10 x 2.00 x 0.85 mm

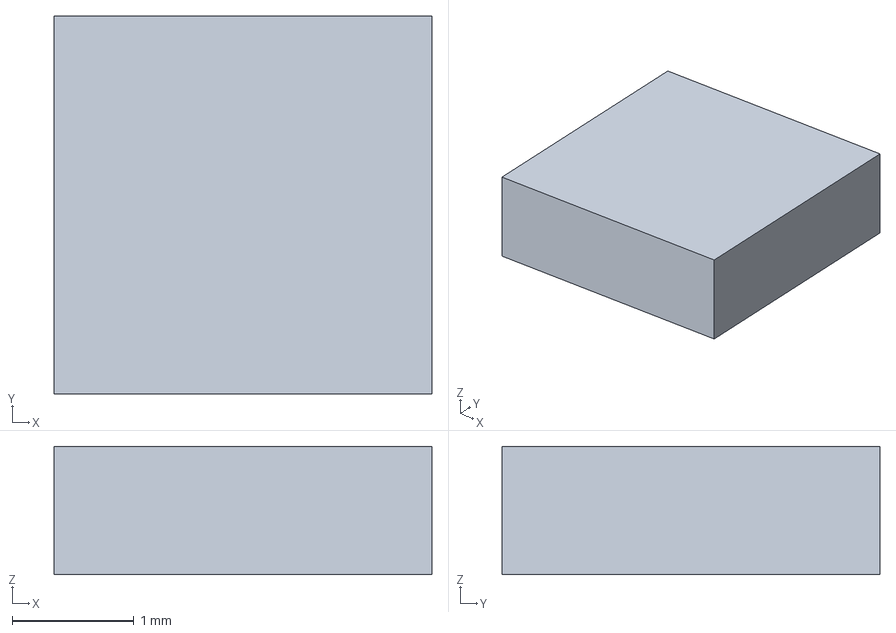
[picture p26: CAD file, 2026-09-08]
PCB/main/assets/imu-models/U2_MAX_PACKAGE_ENVELOPE.step
3.10 x 3.10 x 1.05 mm

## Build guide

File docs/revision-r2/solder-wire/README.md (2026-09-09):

# Compact PTH battery-wire revision — engineering prototype

Based on current main **4cb3c32193bda18d624b7974b65162a7a44f69a0**, in isolated workspace **023**. No merge, push, advisor, other-chat work, purchase or firmware changes.

## Implemented and measured

| Nominal CAD measurement | Before | After | Reduction |
|---|---:|---:|---:|
| PCB bounding substrate, W × L | 25 × 39 mm | **25 × 35.5 mm** | 3.5 mm length; **8.97% bounding area** |
| Actual outline area, before drills | 911.57 mm² | **881.67 mm²** | **3.28%** |
| Complete housing, L × W × H, including recessed M3×8 hardware | 49.8 × 29.4 × 19.6 mm | **46.8 × 29.4 × 19.6 mm** | 3.0 mm length; **6.02% bounding volume** |

[Measured geometry](validation/dimensions.json). The smaller percentage for real outline area is deliberate: the obsolete deep connector notch is filled in. These are not printed-part or purchased-hardware tolerance guarantees.

- **J2 was actually an SMT JST S2B-PH-SM4-TB**, not a through-hole connector. The family documentation also identifies the surface-mount variant. [source](https://www.jst-mfg.com/product/pdf/eng/ePH.pdf)
- J2 is now **two plated through-hole wire solder pads at exactly 2.54 mm (0.1 inch) centre-to-centre pitch**, as clarified by the user. **No fitted JST, pin header, mating body or connector BOM/CPL item.** The old footprint, two MP hold-down pads and schematic MP pin/ground stub are removed.
- **2.0 mm copper pad diameters, 1.0 mm finished-hole target, 0.5 mm nominal annular ring**, 0.54 mm copper separation and **0.44 mm nominal mask web** with 0.05 mm mask expansion. No paste. BAT+ and BAT- are visible on top silk.
- Engineering wire envelope: **tinned conductor bundle ≤0.7 mm diameter**, insulation **≤1.2 mm OD**. A **0.9–1.1 mm finished-hole acceptance screen** leaves ≥0.2 mm diametral threading clearance at the smallest hole and ≥0.45 mm radial annulus at the largest. **No exact wire gauge was supplied or asserted.** Measure the finished plated hole and prepared wire; qualify strand area, insulation, flexibility, current and temperature. Do not drill out a plated hole to fit a wire.
- Solder accessible from the top, wires threaded from below; top lead/fillet protrusion reserved to **0.6 mm maximum**. Main J2 launch is widened to 0.5 mm where clear; the established 0.2 mm power/fine-pin fanout remains, and the separate battery-voltage-sense branch may use 0.15 mm. This is not a certified current rating: measure peak load drop and heating on the real stackup/pack/wires.
- **SW3, D1 and R11–R13 are physically relocated and rerouted into the freed connector area**, H2 moves inward by 3.5 mm, and the board is shortened. Not an outline-only crop. U1, U2, regulators, charger, USB and all decoupling capacitor placements stay unchanged.
- U2 remains the **actual ICM-20948 at (112.5,117.5) mm, F.Cu, −90°**: width-centred and 0.25 mm north of the new board bounding centre. Actual **accelerometer/gyro +Z outward**, raw magnetometer +Z inward; underside of the ESP PCB faces the body. Signed sensor transforms and package evidence are retained.
- Dedicated **wired IMU sheet**, single placed RGB symbol, top-visible RGB aperture, USB programming and BOOT/RESET silk retained. **No testpoints or UART connector**. In1 remains a GND reference plane without signal tracks; the original all-layer RF exclusion is unchanged.
- **46 fitted electronic BOM/CPL entries**; J2 and two NPTH mounting holes are PCB features, not assembly purchases.

## Mechanical retention and wiring

Two separated **3.2 mm NPTH M3 holes** remain for positive antirotation and rigid registration: H1=(103.6,103.6), H2=(121.4,131.9) mm. The two-screw arrangement avoids relying on a lone screw's friction. 3.45 mm all-layer copper reserves surround 3.4 mm insulating bearing faces. No contact with U2 or antenna; no screw or PCB load goes through the battery.

The same verified nominal vertical screw stack is retained: M3×8 underhead Z15.4, tip Z7.4, captured nut Z7.6–10.0 (2.4 mm engagement), PCB Z10.8–11.8, recessed head top Z18.4, outer roof Z19.6. The **measured 7.9–8.1 mm underhead-length screen** is narrow and must be checked on real screws, nuts and prints. See [full assembly instructions](../../../housing/PRINTING-ASSEMBLY.md).

The smaller case has a **dedicated paired-wire bay**, two 1.6 mm guide bores and two **1.2 mm lacing bores in an integral insulating bridge**. Fit nonconductive lacing around the insulated leads through these bores; leave a service loop above the divider. CAD models two independent 1.2 mm OD wire envelopes with R2 centreline bends, not a phantom connector reserve. Straight lacing passages and knot space are screened; **actual lacing/knot/preload and pull/flex resistance are not qualified or fully modelled**. Solder joints alone are not strain relief. No clamp presses on the pouch.

A nominal rigid **20×30×3 mm** body insertion path passes **630 sampled poses**, including entry from above, tilt about −Y and XY translations; no bending/compression. This does **not** establish insertion/removal of the complete 21×31×4.3 reservation or an actual protected pack with PCM, tabs and wires. Try an inert dummy first and never force a pouch.

## Verification

- **Baseline and post: ERC 0, DRC 0, opens 0, schematic parity 0**, under unchanged configured rules/severities, no new exclusions. Ignored KiCad defaults remain disclosed in the export report.
- [Electrical assertions](validation/electrical.json): **1256 pass**, including exact retained endpoint sets, the sole J2.MP removal, critical placements, signed axes, RF, pad/hole/mask geometry and BOM.
- [Net migration](validation/net-migrations.json): only J2.MP is intentionally removed; J2.1 protected PACK_P and J2.2 GND endpoints and all retained electrical architecture are unchanged.
- [Mechanical checks](../../../housing/validation/mechanical.json): **2314 pass**; current native solids, assembly bounds, hardware/PCB/pack/RF/USB/wire collision screens, nut insertion, screw engagement, bearing contacts, STL/STEP and independent display groups. The **obsolete PH2 mate check is removed because the part is removed**, not suppressed; its 2.16 mm³ baseline failure remains in the baseline report.
- [Bearing/copper audit](validation/retention.json): both physical bearing areas free of pads, tracks, vias and filled copper on all four layers.
- [Nominal insertion](../../../housing/validation/battery-insertion.json); [FreeCAD GUI control tests](../../../housing/validation/gui-inspection.json). `InspectAssembly.FCMacro` retained; real desktop Explode/Restore was also visually checked. Base, Lid, Main, Divider, Battery, Cables and Hardware remain independent movable groups.
- [Source/export coherence](validation/coherence.json): **400 checks pass**; [commit handoff instructions](HANDOFF.md), and complete delivery manifest/hash verification cover native CAD, libraries, generators, exports, BOM, documentation and reports.

## Battery/runtime and remaining limits

**Actual cell suitability is still gated.** The 150 mAh / 30×20×3 listing is not a qualified protected battery specification. Preserve the **BQ24074 → AP2112 3.3 V → AP2112 1.8 V** architecture and external protected-pack requirement; R21 ISET, R22 ILIM and R23 TS bias are unchanged. No automatic cell-temperature sensing. Do not connect/charge a candidate merely because it fits.

Retain the **one-hour session with ten 30-second bursts** (300 s active, 3300 s standby). [Existing what-if budget and qualification gates](../integrated/RADIO-BATTERY.md) are unchanged, not a runtime promise. No firmware was implemented. Direct soldering removes convenient battery unplugging; there is still **no latching master OFF switch**. RESET does not isolate the pack or charger.

Physical gates remain: full protected-pack envelope/insertion, current/ESR/charge acceptance, real hole/wire/solder fit and strain relief, print/hardware tolerances, torque/rigidity/creep, magnetic bias, radio/on-body detuning, thermals, USB download reliability and controlled impedance. Native DRC does not certify USB signal integrity. KiCad installed-model renders omit some component models; the housing's complete component bodies are conservative envelopes, not vendor-exact solids. **Manufacturing release=false.**

## Current images

- [PCB top](/uploads/affa7739-2cb2-41de-a6d8-bc5b959e94e7.webp)
- [Power schematic / J2](/uploads/9b5bdd6d-a0ea-4af8-bc6d-db4bad226110.webp)
- [Dedicated wired IMU schematic](/uploads/9a4a96c2-1345-4f35-9fb5-a6689980eeff.webp)
- [Housing exploded](/uploads/37ebcfaa-a060-4ff5-87e2-ec7d9e834bde.webp)
- [Measured housing](/uploads/b14dbb23-9e6c-436b-8fcc-e7d46cc0d2af.webp)
- [Live desktop Explode](/uploads/0beae6ef-4f15-4944-8319-3dd63456cf03.webp), [Restore](/uploads/9949a2b5-adea-46c5-ad0f-6fecbacd4433.webp)

## Safe rebuild

Native routed PCB + parts/interface JSON are canonical. `solder_wire.py --apply` is a one-shot ECO record, not a release rebuild; do not replay it on routed output. Historical placement scripts are likewise not current rebuild entrypoints. After a deliberate native edit:

```sh
/usr/bin/python3 scripts/r2/integrated/sync.py
/usr/bin/python3 scripts/r2/enclosure/extract.py
/usr/bin/python3 scripts/freecad/run.py housing/entry.py generate
/usr/bin/python3 scripts/freecad/run.py housing/entry.py verify
/usr/bin/python3 scripts/freecad/run.py housing/insertion-check.py
/usr/bin/python3 scripts/r2/enclosure/contact_audit.py
/usr/bin/python3 scripts/r2/final/export.py
/usr/bin/python3 scripts/r2/integrated/verify_wire.py
/usr/bin/python3 scripts/r2/integrated/coherence_wire.py
```

Run `PresentAssembly.FCMacro` explicitly in FreeCAD only when refreshing GUI styling/images, then rerun mechanical verification to record the final native hash. The pinned local runtime was reused; no downloaded runtime/substitution or other workspace edits. Older integrated/recovery reports and the backup ZIP are historical provenance, not approvals for this revision.

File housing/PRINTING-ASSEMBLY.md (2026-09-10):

# Screwless prototype: print, insulate, fit, then qualify

**RF TEST PROTOTYPE. No proven physical fit, strength, sealing, RF performance or charging release.** Three prints only: white Midframe, Top cover, Bottom cover. No fasteners, threaded features, inserts or enclosure mounting holes in the PCB.

## Print plan and limitations

- Candidate process: nonconductive white PETG, 0.4 mm nozzle, approximately 0.2 mm layers; configure wall lines to achieve the actual 0.8 mm CAD wall. These are starting settings, not a validated material/profile. Do not use metal/carbon/conductive filament near the antenna or pouch.
- Covers are exported exterior face down. Inspect the internal groove and cover PCB-stop overhangs in the slicer; use removable supports where needed. Protect all mating lands from support scars and elephant-foot growth.
- Midframe is exported **east edge down**. Use a brim and carefully placed removable supports under the separator and locating features. It is not claimed support-free. Do not force an unsupported 21 mm ceiling bridge; an alternate orientation needs its own support/removal review. Smooth every pouch-facing edge after support removal.
- Cut a local sleeve/snap sample in the slicer before spending material on the entire set. The full delivery still contains exactly three printable parts, not an extra insert or latch. Test both assembly and non-destructive disassembly; repeated cycle retention, creep, temperature and impact remain gates.
- Default wall is 0.8 mm, not a recommendation to reduce inner structural features to 0.8 mm. Separator and sleeve stock are 1.2 mm; groove reinforcement preserves the ordinary outer wall thickness. Optional 1.2 mm outer walls were also checked; dimensions grow outward (floor grows up), not into component-side clearance.
- 2.9 mm recessed RESET/BOOT holes have a 0.85 mm web. Verify sliced continuity and access with a blunt insulating tool. Do not assume unsupported sub-nozzle details print. USB is a conservative rectangular plug aperture; gauge it with the actual plug/overmold.

## Datums and clearance budget (mm)

Case X=nativeX−100; Y=139−nativeY. PCB outline spans X0..25, Y9..39, including the actual east USB recess. Exact exported KiCad substrate face/holes are mapped from drill origin (100,135) to this case frame; the STEP's dielectric-only 0.91 mm thickness is expanded to the accepted **1.0 mm total board envelope**. Component envelopes remain conservative contract AABBs, not exact vendor solids.

| Feature | Nominal allocation |
|---|---|
| PCB bottom / top | Z12.6 / 13.6 |
| Underside support land top | Z12.2 |
| Land insulation / adhesive or shim | 0.2 + 0.2, bringing support to Z12.6 |
| Cover PCB travel stop bottom | Z13.85: 0.25 free lift, no clamp preload |
| Lateral/end PCB locating clearance | Nominal 0.25 at fences/end stops; inspect actual outline |
| Battery allowance | X2..23, Y6.5..37.5, Z1.8..6.1 |
| Battery flat pocket | X1.8..23.2, Y6.3..37.7; 0.2 nominal per side |
| Separator | Z6.8..8.0; 0.7 above complete-pack allowance |
| Worst USB shell-tail underside | Z11.4: 3.4 above separator |
| Body-side pack liner | Z1.4..1.6; 0.2 nominal adhesive/air allocation to pack bottom |
| North antenna exclusion boundary | Y39; allowance and lead reserve stop at Y37.5 or earlier |
| Sleeve radial gap / insertion flex | 0.18 / 0.12 nominal |
| Seated groove radial clearance | 0.12 nominal, axial clearance 0.12 each side |

Dimensions are not an accumulated manufacturing tolerance analysis. Check maximum board thickness, warp, surface copper/solder, film compression and actual pack dimensions before fitting. **Do not make the pouch a structural shim or force the covers shut.** The 0.7 mm gap is a geometry allowance, not an approved swelling specification. If the pack manufacturer requires more, enlarge/requalify the design.

## Assembly sequence (unpowered)

1. Inspect and deburr the prints, especially all pouch-facing surfaces, internal wire corridor and snap edges. Check snap coupons and bare three-part fit without electronics; perimeter hard stops must close without the pack. Service by flexing the cover near the side rails using a nonmetal tool; no service-force or cycle life is established.
2. Fit 0.2 mm dielectric film on the four PCB lands (west contact width 0.7, east 0.9; length 2). Use a controlled 0.2 mm dielectric shim for the no-glue option or qualified 0.2 mm nonconductive removable adhesive. Do not bond over vias, bare pads, solder or components. Optional adhesive must not wick into the electronics or create new load paths. Button pressing must not bend the unsupported PCB excessively; bench-test displacement.
3. Seat the PCB from above on the midframe, facing components outward. Four cover-integral broad stops capture the board loosely when the top is installed. No screw load, no pressure on IMU/module/switch bodies, no claim of a perfectly rigid sensor mount. If adequate rigidity cannot be obtained without stress, stop and revise the support design.
4. Measure the **complete qualified pack**, including protection, seals, tabs and lead exit. The nominal candidate is not a purchased/approved pack. Insert from below into the frame pocket, with smooth 0.2 mm floor insulation and optional qualified removable PSA on the flat body-side contact area. The midframe locates the pack laterally and separates it from electronics; the bottom cover captures it vertically. The smaller 3 mm candidate may rattle without a qualified low-stress retention method; do not fill the gap with compressed foam or press on a pouch seal. The pocket dimensions are for the full allowance, not a custom cradle for an unknown actual pack.
5. Route two individually insulated OD≤1.2 mm leads UP (+Z) from unchanged BAT pads, not below the PCB. R2 centreline bends turn west at Z16.4, follow the INTERNAL perimeter at X−1.5 and X−3.0, descend at Y22 and Y25 around the separator's west edge to Z3.2, then return east to X1.95 through the battery locator-only relief. The separator remains continuous over the complete pack. See orange paths in `dist/assembled-wire-path.png` and exact coordinates in `validation/mechanical.json`. Do not cut a wire hole through the separator.
6. Keep the complete 0.25 mm radial extra route reserve clear. Nominal minimum lead-to-print gap is 0.43 mm; no physical pinch tolerance is guaranteed. Optional qualified nonconductive strain relief may use the west land at X−4.4..−3.9, Y28..31, Z3..6, but no bond thickness or adhesive process is qualified. Actual pack lead exit to the modeled battery entry remains a pack-selection gate. Stiffer/larger wires or different bend limits require rerouting and revalidation. Keep slack away from snap joints, antenna and USB.
7. BAT+ is J2.1 at native (104.5,105.57); BAT− is J2.2 at (104.5,103.03). No pad/drill/routing edits. The enclosure reserves solder radius 1.1 mm and height 0.55 mm above the top pad plus an upward wire bend. The actual through-hole termination and opposite-face solder/trim must be inspected for insulation and fit; wire gauge/termination process is not qualified. Do not solder directly to a pouch or connect USB during assembly.
8. Fit covers only after confirming wire slack cannot be pinched and the pack has no preload. Use the blunt-tool RESET/BOOT accesses, LED window and actual USB plug as gauges. Do not power or charge merely because the case closes.

## Remaining physical release gates

- Actual full pack, lead exit, protection, cell charge limits, charger compatibility and swelling/thermal allowance.
- Print dimensional accuracy, local supports/removal quality, snap insertion/extraction force, fatigue/creep, drops and skin-contact/material suitability.
- Board/film/adhesive coplanarity, insulation abrasion, button-induced bending and IMU stability; adhesive serviceability and chemical compatibility.
- Lead bend rating, pack-to-entry connection, solder clearance, pull/flex strain relief, pinch checks and polarity.
- Physical USB/RESET/BOOT/LED access, RF on-body performance, magnetometer bias and temperature. The existing compact housing **does not meet a full 15 mm all-direction RF clearance recommendation**; retaining the accepted forward exclusion is not RF compliance.

No charging, manufacturing or physical-fit release. No merge. Prior screw/two-part records remain historical only.

## Protected extension and USB

Keep the original module antenna end inside the thin integral cap; use no metal/conductive coating. Cap floor is part of the midframe; top skirt/roof is part of the top cover. No external antenna substitution. This is not full Espressif housing-clearance compliance; run on-player RF tests and enlarge if needed. No sweat seal is claimed.

HRO TYPE-C-31-M-12 nominal mouth and local exterior surround coincide at case X24.78. Opening 10×4.3 mm uses source maxima and explicit placement/print allowance; inspect the selected plug overmould. No universal cable fit guarantee. See source drawing and tolerance derivation in README.

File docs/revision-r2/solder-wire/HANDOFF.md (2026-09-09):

# Complete-commit integration handoff

This work is based on main `4cb3c32193bda18d624b7974b65162a7a44f69a0`, branch `okbrain/smove-files/023-b6a2a21d`, preserved workspace `/home/azero/.okbrain/workspaces/smove-files/023`.

**Do not merge a selected subset of files.** Native PCB/schematic/library changes, generators, BOM, Gerbers/drills, STEP/STL, FreeCAD native assembly, images, interfaces and documentation/reports form one revision. Integrate the entire committed revision, including the deleted obsolete JST footprint. No merge or push was performed by this task.

## Authoritative delivery inventory

- `commit-paths.txt`: exact complete changed pathname set, including this handoff, manifests and the removed connector footprint.
- `delivery-manifest.json`: baseline commit, branch, complete changed-path count, A/M/D status, before hashes, after hashes, and SHA256 for the complete scoped source/export/report set (including unchanged required inputs).
- `PCB/main/dist/manifest.json` and `housing/dist/manifest.json`: refreshed subtree manifests. Historical manifests in earlier revision/recovery directories describe their old trees and are not current validation.
- The master manifest cannot hash itself recursively. Its independent SHA256 and the verified Git commit ID are reported at task completion; its committed blob is separately compared byte-for-byte with the preserved workspace.

`seal_wire.py seal` explicitly stages all intended files and deletions and verifies the complete index path set and blob bytes. The task then makes a normal Git commit and independently verifies committed blobs, not merely working-tree content. No autostash is the delivery mechanism.

## Verification after fetching the complete revision

```sh
# In the delivered workspace / checked-out revision:
/usr/bin/python3 scripts/r2/integrated/seal_wire.py verify HEAD

# After an eventual full integration, validate delivery bytes against the manifest:
/usr/bin/python3 scripts/r2/integrated/seal_wire.py verify --worktree

# Confirm exactly which files the delivered commit changes:
git diff --name-status --no-renames 4cb3c32193bda18d624b7974b65162a7a44f69a0 HEAD
```

The first verification compares the revision's exact changed path set with the manifest and verifies all manifest-covered committed blobs plus intended deletions. The worktree form checks preserved delivery contents after integration; additional unrelated base changes are not mistaken for missing deliverables. If an intentional integration edit changes covered content, investigate and regenerate/revalidate relevant native exports rather than overwriting the hash to conceal a mismatch.

## Current checks and release limits

Baseline and post ERC/DRC/opens/parity are zero under unchanged configured severities. Electrical assertions, mechanical geometry/fastener/wire screens, full four-layer bearing audit, source/export consistency and native GUI assembly controls pass. A rigid nominal-body insertion route is sampled without compression; a complete protected pack and wire/lacing assembly still require physical qualification.

No physical battery approval, manufacturing/charging release, firmware, advisor work or merge. Runtime binaries, local caches and temporary routing intermediates are ignored workspace state, not committed deliverables. The native files and the documented rebuild scripts are included; historical source snapshots remain provenance, not current placements.

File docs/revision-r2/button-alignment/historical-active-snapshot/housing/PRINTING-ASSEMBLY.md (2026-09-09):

# Simplified central-H1 two-part case — assembly and release hold

## What to print

Print **only `dist/base.stl` and `dist/lid.stl`**. Each is one connected part. The PCB components, battery, screw, nut and thin insulating films shown in FreeCAD are purchased/reference items, not extra 3D prints. Internal CSG boxes and cylinders are editable construction features, not a parts list.

The latest simplification keeps the accepted central-screw layout and battery choice:
- Four **2.6 mm wide wall-rooted corner blocks** replace skinny seats, webs and separate 0.3 mm fences. Their stepped surfaces locate the PCB without screw preload.
- Four integral lid pads are now **at least 1.4 × 1.4 mm**, replacing 0.6 mm-wide lips.
- Removed both hooks and their undercut pockets. Lid now drops **straight down**; no slide, snap tabs or separate clips. The front nut stop is joined into the broad front skirt instead of a freestanding thin tab.
- The insulated central nut socket and battery ceiling remain necessary. This is simpler, **not certified support-free**. No new small printed part was added.

## Current revision and dimensions

**Base + Lid only. One M3×8 socket-cap screw through the existing PCB H1. No side screw, ear, wire bay, wire channels, lead exits, lacing, solder or modeled/reserved leads.** The integral battery ceiling and lid entry skirt are not separate parts.

| Overall L × W × H (mm), including hardware | Preserved b49ade5 | Current |
|---|---:|---:|
| Length | 42.0 | 42.0 |
| Width | 36.8 | **28.8** |
| Height | 16.6 | **19.6** |

The accepted central draft and this simpler revision are both **42.0 × 28.8 × 19.6 mm**. Width is 8.0 mm smaller and below 30 mm without reducing the battery envelope. Height increases 3.0 mm to keep the central M3×8 tip/nut entirely **above** the sealed battery ceiling. Reusing the old under-head plane Z13.2 would put the tip at Z5.2, inside the maximum battery Z1.8..6.1: **that old-height central stack is blocked**. No side-screw fallback or longer screw was added. Neither 120 mm nor an unconfirmed 12 mm target is assumed.

Coordinates: X=nativeX−100, Y=139−nativeY. PCB bounds X0..25, Y9..39, bottom Z12.6, top Z13.6. Main underside faces the body; IMU accel/gyro +Z points outward. No PCB placement, orientation, pad, routing, rule or firmware changes.

## Central insulated interface and load path

H1 stays Ø3.2 **NPTH**, at native (111.8,125.65), local **(11.8,13.35)**. ONLY this axis has a screw.

- Screw head bears on the **integral insulating lid bearing**, not a metal washer on the PCB. Nut is inside a raised base boss above the battery ceiling, retained against rotation by its hex pocket and against front escape by the integrated front skirt/stop.
- Closure preload travels from head → lid bearing/roof → case perimeter → base structure/transverse beam → captive nut. The beam connects to the insulating pocket walls. The battery and PCB are **not clamp spacers**. The central screw passes through H1 while split edge grooves capture the PCB inside the closed base/lid.
- Four insulated stepped corner seats and four broad lid pads preserve positive antirotation. Groove height 1.55 mm around the nominal 1 mm board; thickness/print/liner budget leaves **0.20 mm minimum axial freedom**. Nominal lateral play is 0.30 mm per side; ±0.15 print and 0.10 board-edge allowance leave 0.05 mm minimum.
- An **annular R2.2 mm plastic stop** below H1 is initially 0.35 mm below the board (0.05 mm after adverse ±0.15 seat/stop errors). The wide nut-boss roof stays 0.70 mm below PCB (0.40 mm adverse). These are abnormal-deflection stops, not a screw clamp or supports resting on the pouch.
- The inherited minimum filled-copper radius around H1 is 3.442612 mm. R2.2 stop margin is 1.242612 nominal; subtract 0.30 board play +0.15 placement +0.15 radius +0.10 registration = **0.542612 mm residual**. The retired R3.4 loaded bearing's 0.042612 mm margin is not reused.
- There is **no fictitious printed sleeve** in the 0.10 mm nominal radial space between M3 and Ø3.2 H1. The hole wall is insulating, unplated FR4. The shank can touch that FR4 at the float limit; it must not touch copper. Even using Ø3.25 maximum hole and 0.10 copper registration, the radial copper separation beyond the hole is **1.717612 mm**. Head and nut are axially isolated by plastic and gaps, not solder mask.

**Alignment acceptance is mandatory, not proven by nominal CAD.** Gauge the finished NPTH (screen Ø3.15..3.25), use a shank ≤3.00 mm, and prove a smooth Ø3.00 gauge passes the assembled stack without forcing or bending PCB. At Ø3.15 the centered radial allowance is only 0.075 mm. Board/nut float may be used for hand alignment, but the independent ±0.15 print registration budgets do NOT guarantee every manufactured combination will align. Reject a binding assembly; do not drill the PCB larger, force the screw, or use tightening to pull holes into alignment.

## M3×8 stack and tolerances

Screen actual M3×8 hardware against the stated maximum envelope: head Ø5.68 × 3 mm, 0.5 mm pitch, length 7.71..8.29 mm, 2.5 mm hex drive. Reference dimensions are from ISO 4762. [source](https://www.fasteners.eu/standards/ISO/4762/)

| Interface | Nominal Z / dimension (mm) | Adverse check |
|---|---|---|
| Max pack top / ceiling underside / ceiling top | 6.1 / 6.6 / 7.4 | Pack gap 0.20 after 0.15 print +0.15 liner error |
| Blind-bore floor / screw tip | 7.4 / 8.4 | **0.56** tip-floor clearance after 0.29 length +0.15 seat error |
| Screw tip to maximum pack | 2.30 | **1.86**, in addition to intact barrier; no pouch penetration |
| Nut (AF5.5 × 2.4 envelope) | 8.6..11.0 | Pocket AF5.8, Z8.3..11.0; gauge actual fit |
| Nut roof / PCB bottom | 11.9 / 12.6 | Roof 0.90 nominal / **0.60** minimum thickness |
| Stop top / PCB bottom | 12.25 / 12.6 | 0.35 nominal / **0.05** initial gap |
| Lid bearing bottom / screw under-head | 15.1 / 16.4 | Bearing 1.30 nominal / **1.00** minimum |
| Screw head top / lid top | 19.4 / 19.6 | Head recessed 0.20 nominal |
| Thread overlap | **2.40** | **2.01** geometric; **1.61** after additional 0.40 combined chamfer reserve |

CAD threads are cylindrical envelopes, not helices. The Ø3.6 case bores and Ø7.0 recess allow an additive head eccentricity/radius budget with 0.06 mm residual. Actual head access and nut-pocket fit must be gauged. The small RGB opening intersects the recess edge locally; the screw head does not obstruct its optical axis. Do not add a metal washer at H1.

**No tightening torque or strength rating is released.** The 0.9 mm nominal captive-pocket roof, beam, lid bearing and printed walls need proof-load, creep and repeated-opening tests. Tighten only under an approved low-preload prototype procedure, never a generic metal-joint M3 torque. After closure, verify the PCB remains unbowed/free of clamp preload and the ceiling remains clear of the pouch. Low-magnetic hardware suitability is unqualified. Dimensional clearance does not establish stiffness, fatigue or insulation-wear safety.

## Battery and user-routed leads

Candidate **30×20×3 mm**; complete protected-pack allowance **31×21×4.3 mm**, including seals, tabs and PCM (leads excluded and entirely user-managed). No supplier pack or charging suitability is approved. The pocket was not narrowed to reach the width target. Stop if the complete pack exceeds the admission envelope; no squeezing, foam preload or battery compression.

Pack lower face Z1.8 rests on 0.2 mm smooth insulating film above the 1.6 mm body-facing floor. The integral 0.8 mm ceiling retains the pack with side walls, north stop and the lid's integral front skirt. PCB sits on separate plastic/film seats, never on the battery. The battery may translate within the pocket; at the north stop it stays 1 mm behind local RF boundary Y39. No screw bore or nut pocket opens into the battery tunnel.

**All dedicated lead geometry was removed. BAT+ and BAT− pads are unchanged.** Soldering, wire choice, actual route, bend radius, strain relief, trim, polarity and closure/pinch inspection belong to the user's physical assembly. No space is dedicated/reserved and no lead fit, insertion, strain relief or RF route is claimed verified. A user-chosen route may not fit this closed case; do not pinch a lead to make it close. Stop for review if it cannot be routed safely. User-routed leads must avoid the antenna/all-layer RF area, screw, pouch pressure and sharp edges. No powered-pack soldering or live-cell handling procedure is provided.

## Mechanical assembly (not exploded display offsets)

1. With power disconnected and pack safely isolated, gauge/deburr the two insulating prints. Fit smooth floor/seat films and verify coplanar seats, intact ceiling and no bridge sag or sharp edges. Use nonconductive, non-metal/carbon-filled material only.
2. Insert the hex nut from the **front interior**, above the battery ceiling, before PCB/lid. It sits against the pocket roof. Slide the uncompressed pack north through the front tunnel opening with lid off. This maximum-envelope continuous translation was checked against the base.
3. Lower the populated PCB vertically into its seats/positive edge stops, aligning H1. User handles leads independently; they were deliberately absent from all CAD collision/path checks.
4. Lower the lid **vertically at its final XY location**. The integral front skirt closes battery entry and its thicker central extension retains the nut. There are no hooks, latches or sliding sequence. Screw is still absent. Check all perimeter edges seat; the single screw is not permission to force a warped lid flat.
5. Verify smooth gauge passage and insert ONLY M3×8 from the top through H1, last. Reverse for servicing: screw out, then lift vertically. Never use screw preload to flatten the board, close a trapped lead or compress the pouch.

STLs are already **floor-down Base and roof-down Lid**. Broad corner blocks grow from the base floor and lid pads grow from the lid roof; there are no hook undercuts or detached islands. Both meshes are closed manifold single parts.

**Remaining print limitations:** the battery-ceiling bridge spans **21.8 mm** and the captive-nut slot is about **5.8 mm across flats**. Those retained safety features still require a real bridge/slot trial, sag inspection and dimensional gauges. Do not blindly generate inaccessible supports inside the battery slot or nut pocket; if the printer cannot bridge cleanly, stop for process/design review rather than leave trapped support or shorten battery clearance. Lid screw-bore/recess and access holes also require clean bridging/edges in the delivered orientation. No universal support-free claim, slicer profile, production material or torque rating is supplied. The far lid edge no longer has a hook: verify single-screw closure does not lift/warp there during handling.

Top RGB, USB and nonconductive-tool BOOT/RESET access are retained. Conservative component models are not vendor-exact connectors/buttons. Broad RF clearance limitations from the inherited design remain; this compact enclosure does not meet a broad 15 mm antenna clearance in every direction and has no RF certification. No new wire qualification or RF study was performed.

**Manufacturing/charging release remains false.** Remaining gates: physical coaxial fit, print stiffness/creep/preload, seat/insulation wear, complete protected-pack/charger suitability, user lead routing, access usability and existing RF/thermal/magnetic qualifications. These are real blockers to physical release, not missing CAD files. See the inherited [battery/charging constraints](../docs/revision-r2/integrated/RADIO-BATTERY.md).

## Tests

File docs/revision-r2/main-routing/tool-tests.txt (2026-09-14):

test_blocked (pcb_tools.test_tools.GeometryTests.test_blocked) ... [32mok[0m
test_deterministic (pcb_tools.test_tools.GeometryTests.test_deterministic) ... [32mok[0m
test_duplicates_collinear_and_reversal (pcb_tools.test_tools.GeometryTests.test_duplicates_collinear_and_reversal) ... [32mok[0m
test_exact_endpoints_all_quadrants (pcb_tools.test_tools.GeometryTests.test_exact_endpoints_all_quadrants) ... [32mok[0m
test_staircase_removed (pcb_tools.test_tools.GeometryTests.test_staircase_removed) ... [32mok[0m
test_straight_preferred (pcb_tools.test_tools.GeometryTests.test_straight_preferred) ... [32mok[0m
test_bend_aware_search (pcb_tools.test_tools.NativeTests.test_bend_aware_search) ... [32mok[0m
test_edge_clearance (pcb_tools.test_tools.NativeTests.test_edge_clearance) ... [32mok[0m
test_internal_layer_rejected (pcb_tools.test_tools.NativeTests.test_internal_layer_rejected) ... [32mok[0m
test_locked_ripup_rejected (pcb_tools.test_tools.NativeTests.test_locked_ripup_rejected) ... [32mok[0m
test_manual_two_layers (pcb_tools.test_tools.NativeTests.test_manual_two_layers) ... [32mok[0m
test_no_diagonal_layer_change (pcb_tools.test_tools.NativeTests.test_no_diagonal_layer_change) ... [32mok[0m
test_nonfinite_and_negative (pcb_tools.test_tools.NativeTests.test_nonfinite_and_negative) ... [32mok[0m
test_output_guard (pcb_tools.test_tools.NativeTests.test_output_guard) ... [32mok[0m
test_paste_via_rejected (pcb_tools.test_tools.NativeTests.test_paste_via_rejected) ... [32mok[0m
test_route_no_mutation_until_apply (pcb_tools.test_tools.NativeTests.test_route_no_mutation_until_apply) ... [32mok[0m
test_router_uses_bottom_and_vias (pcb_tools.test_tools.NativeTests.test_router_uses_bottom_and_vias) ... [32mok[0m
test_stale_plan_and_no_partial_insertion (pcb_tools.test_tools.NativeTests.test_stale_plan_and_no_partial_insertion) ... [32mok[0m
test_transaction_rollback (pcb_tools.test_tools.NativeTests.test_transaction_rollback) ... [32mok[0m
test_unknown_net_rejected (pcb_tools.test_tools.NativeTests.test_unknown_net_rejected) ... [32mok[0m
test_width_checked_not_just_centerline (pcb_tools.test_tools.NativeTests.test_width_checked_not_just_centerline) ... [32mok[0m

----------------------------------------------------------------------
Ran 21 tests in 0.053s

[32mOK[0m

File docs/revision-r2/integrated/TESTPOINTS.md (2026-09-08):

# External debug interface removed

Latest owner revision removes **ALL TP1–TP14 and J3 UART/service header**, including BOOT/EN probe branches. This supersedes the earlier testpoint map. No external testpoints are populated or exposed in the native PCB or schematic. USB programming, BOOT/RESET buttons and their functional circuits remain. U1 pins30/31 and ICM INT1 are deliberately NC. See [current handoff](README.md) and [intentional net migrations](validation/centered/net-migrations.json).

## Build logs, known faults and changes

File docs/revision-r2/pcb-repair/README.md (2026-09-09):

# PCB-only bounded recovery — electrically clean, mounting release blocked

**Review only; not merged, not released for manufacture/assembly. Board remains 25 × 30 mm.**

## Recovery and bounded routing outcome

- Main baseline: `554e4fe`. The failed `faf335b` object was recoverable. Four PCB placement/source files were extracted, not cherry-picked; no housing work was recovered.
- Real native KiCad Computer Use was available. C7 was moved in its properties dialog and two B.Cu 1.8V segments were interactively routed and saved. The attempted 0.25mm C7 move caused a courtyard overlap; C7 was manually returned to Y120.25 and zones refilled/saved. This attempt reduced 16 to 15 opens, without weakening any rules.
- One FreeRouting invocation, maximum eight autorouting passes / 120-second wall cap / one optimizer thread, completed within the cap. Exact input, session and log are preserved. Candidate import plus fixed-route restoration and removal of 12 rounded duplicate vias left **3 opens and 4 dangling violations**, but added **45 signal segments on In1**, the intended GND reference plane. **Rejected**, not represented as successful routing or copied to the final PCB. No second routing invocation or generation loop was run.
- The subsequently supplied clean commit `96e081b9b29db2bb852a43be9e6060a8a99aadf9` was inspected and selectively reused: PCB/main sources and associated PCB exports, plus the placement-sync script only. **No merge, casing files or enclosure scripts.** The final native PCB is byte-identical to that commit. The manual/FreeRouting attempts remain archived under `review/attempts/`; they are NOT fabrication inputs. Manual routing evidence describes the attempt, not authorship of the selected final routes.

## Independent final checks

`validation/final-checks.json` records 170 passing electrical/source/geometry checks, alongside a separate **blocked mechanical-release gate**:

- Native KiCad final ERC: 0 issues. DRC with all severities, all track errors and schematic parity: 0 violations, **0 unconnected items, 0 dangling items, 0 parity issues**.
- Baseline/final schematic netlists and native pad-to-net assignments equivalent; parts, side and pad geometry retained. All four USB data-net routing geometries exactly equal baseline, not merely endpoint-equivalent.
- Native project, rule file, schematic and stack/setup unchanged from baseline, with SHA-256 proof. **No severity downgrades or new exclusions.** No In1 signal routing in the selected PCB.
- Placement sources/native-layout contract match the selected native PCB. Gerbers/drills, CPL/BOM, schematic/assembly PDFs, STEP and renders were reused from the exact same native PCB source; not regenerated over manual routing. `PCB/main/dist/manifest.json` identifies provenance and release status.
- J2 BAT+ `(104.5,105.57)`, BAT− `(104.5,103.03)` mm: 2.54mm pitch, 1mm drill, 2mm pads. Minimum BAT copper gap to the RF exclusion: **2.03mm**. This is a geometric corridor check, not RF certification. Wire routing and on-body RF performance remain unqualified.
- H1 `(111.8,125.65)` mm: 3.2mm NPTH, 3.45mm nominal all-layer copper exclusion; **8.180006mm** from U2 centre (8.15mm below in native Y). U2 remains `(112.5,117.5)`, top side, −90°. Accel/gyro +Z outward, PCB underside body-facing. USB, buttons and RGB retained; no UART/testpoints added.

## Precise unresolved release blocker

The existing keepout is polygonal. Actual minimum filled-copper radius is **3.442612mm**, not an ideal 3.45mm circle. The previous bearing radius was **3.4mm**, leaving only **0.042612mm** nominal clearance. Nearest track copper is at radius **3.478167mm**. These margins are **not robust insulation** and do not include shank/hole play, eccentricity, print/fabrication tolerances, preload or wear. Solder mask is not accepted as the missing tolerance allowance.

The board is electrically clean but **do not assemble using the prior bearing/case**. A tolerance-qualified insulating mounting interface (or a local copper/placement revision with repeat DRC) must be reviewed before release. No new hardware specification, smaller bearing, casing fix or mechanical robustness claim is silently substituted here. Magnetometer bias, IMU strain, RF on-body performance, current/thermal and impedance qualification remain prototype tests.

**All old housing is incompatible/unvalidated for this PCB placement.** Existing housing files are unchanged. Historical mechanical coordinates/STEP frames are not proof of fit. No casing generation or assembly validation was done in this repair.

## Evidence and repeatability

- [Native GUI screenshot evidence](images/README.md)
- `validation/`: baseline/recovered/manual/refilled/FreeRouting/final DRC; baseline/final ERC and actual XML netlists; recovery, selection, geometry/rule/net checks and router log.
- `review/critical-diff.md` and `review/critical-diff.patch`: selected placement and source-policy changes; no weaker rules.
- `manifest.json`: source, attempt, validation and export hashes; exact reusable provenance.
- Run `/usr/bin/python3 scripts/r2/integrated/verify_pcb_repair.py` after the recorded CLI checks. This verifier does not save the PCB. `sync.py` only publishes placement metadata and now reapplies the explicit PCB-only/no-housing-release policy. **Do not run board generators or route helpers over this native PCB.**

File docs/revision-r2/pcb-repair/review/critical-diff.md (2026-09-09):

# Critical review excerpts

- Main `554e4fe` unchanged; no merge. Native PCB selected exactly from `96e081b`.
- BAT source pose: {'baseline': [121.3, 126.5, 0.0], 'final': [104.5, 104.3, 90.0]}
- H1: (103.6,103.6) -> (111.8,125.65)mm. Outline still 25x30mm.
- C7 final selected position (111.25,120.25)mm. Manual correction and attempted route are archived.
- Project/rules/schematic/board stack/setup: byte/semantic equal to baseline; no exclusions or severity edits. SHA-256 proofs in final-checks.json.
- Four USB data-net route geometries exactly retained; no In1 signal tracks.
- Added explicit manufacturing hold and incompatible/unvalidated housing policy; sync reapplies it without saving PCB.
- Capped FreeRouting candidate rejected for 3 opens, 4 dangling violations and 45 In1 segments.

Complete placement delta: placement-diff.json. Focused metadata/source patch: critical-diff.patch.

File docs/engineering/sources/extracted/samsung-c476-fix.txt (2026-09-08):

CL21A476MQYNNN# | MLCC | SAMSUNG ELECTRO-MECHANICS
SAMSUNG ELECTRO-MECHANICS
Component
Center
Product Search
MLCC
Basic Search
Lineup Search
Cross Reference
Power Inductor
Basic Search
Lineup Search
Tantalum
Basic Search
Lineup Search
Chip Resistor
Basic Search
Silicon Capacitor
Basic Search
Component Library
MLCC
Power Inductor
Tantalum
Converter Simulation Tool
Buck Converter Simulation
Design Support Tools
S-parameter
Linear Technology LTspice
Cadence Pspice
Synopsys Hspice
Cadence AWR
SIMetrix/SIMPLIS
Keysight ADS
Cadence Sigrity Power SI
Ansys Slwave
Technical Resources
Product News
Technical Articles
Video Library
Product Catalog
Support
FAQ
Inquiry
Certificate
Product Environmental Certificate
Environment/Safety/Quality
Sales Partners
Korea
Greater China
Japan
Southeast Asia
Americas
Europe
Sales Representatives
Americas
About Us
Company
Company Information
CEO Message
Global Network
History & Awards
IR
Earnings Release
Financial Information
Shareholder
Corporate Governance
IR Archives
Stocks
Sustainable Management
Newsroom
ENG
ENG
CHN
close
MLCC
CL21A476MQYNNN#
Mass Production
General
Standard
2T
Lineup Normal
85
N/A
RoHS
REACH
open guide
"#" indicates a package code.
List of part numbers with package codes
open guide
CL21A476MQYNNN5
CL21A476MQYNNNE
CL21A476MQYNNNF
CL21A476MQYNNNG
CL21A476MQYNNNR
CL21A476MQYNNNW
※ If the packaging code is Z or R, the horizontal package type (HMC) is applied to reduce the acoustic noise.
Simulation
Inquiry
Size
inch(mm)
Size table
Size Code
0805 (2012)
L Size
2.00±0.20mm
W Size
1.25±0.20mm
T Size
1.25±0.20mm
Features Normal
Characteristics
Size table
Temperature Characteristic
X5R(-55 ~ +85)
Capacitance
47.0uF
Tolerance
±20%
Rated Voltage
6.3Vdc
Status
Mass Production
Any data in this page are subject to change, modify or discontinue without notice.
This page includes the typical data for design reference only.
If there is any question regarding the data, please contact our sales personnel or application engineers.
Created :
2026/09/08 05:38:01
KST (Korea Standard Time), UTC/GMT +9 hours
Download This Page (.PDF)
Data
Specsheet
Datasheet
S2P & SPICE
Symbol, Footprint, 3D Model
Recommended For You
Part Search Tool
Product Search
Simulation Tool
Component Library
Technical Data Archive
Software Library
Sales Partners
Product Environmental Certificate
Certificate
Latest Newsletter
Caution
Contact Us
Copyright. SAMSUNG ELECTRO-MECHANICS All rights reserved.
Package Code : Last # of The Part Number
Size table
Code
Type
Reel
Remark
C/8/H
Cardboard
7"
Normal (Q'ty option)
J
1mm pitch
Z
Horizontal aligned (Low Acoustic)
Y
Vertical aligned
O
10"
Normal
3/D/L
13"
Normal (Q'ty option)
2
1mm pitch
7
Vertical aligned
5/E/G
Embossed
7"
Normal (Q'ty option)
R
Horizontal aligned (Low Acoustic)
W
Vertical aligned
S
10"
Normal
F
13"
Normal
close layer
close layer

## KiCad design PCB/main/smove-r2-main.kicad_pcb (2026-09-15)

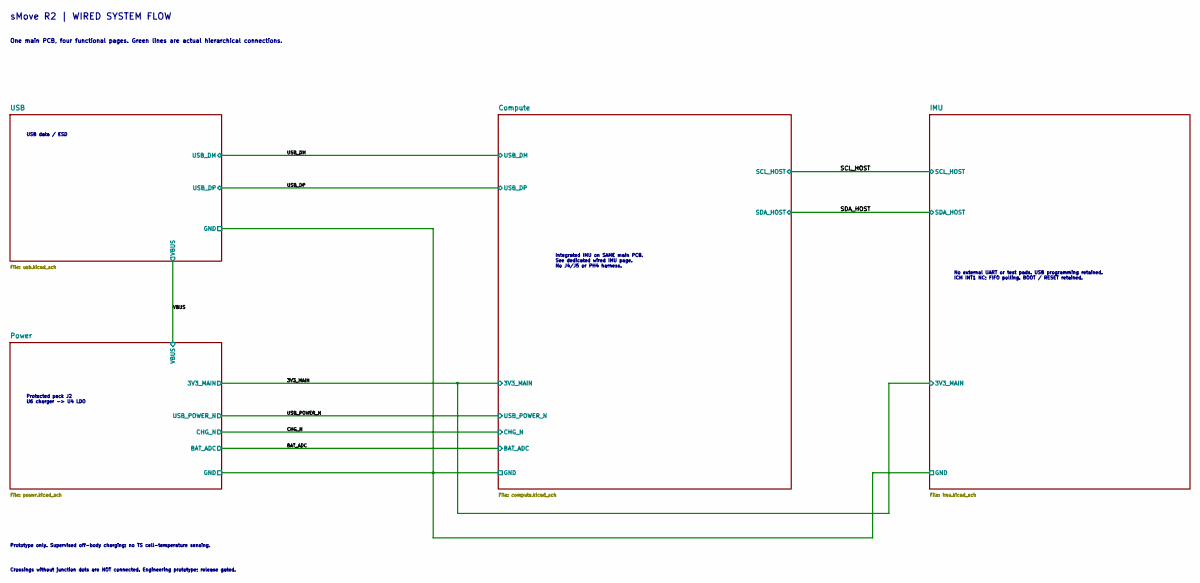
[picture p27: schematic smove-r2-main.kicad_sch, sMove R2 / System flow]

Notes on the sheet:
sMove R2 | WIRED SYSTEM FLOW
One main PCB, four functional pages. Green lines are actual hierarchical connections.
USB data / ESD
Protected pack J2 U6 charger -> U4 LDO
Integrated IMU on SAME main PCB. See dedicated wired IMU page. No J4/J5 or PH4 harness.
Prototype only. Supervised off-body charging; no TS cell-temperature sensing.
Crossings without junction dots are NOT connected. Engineering prototype; release gated.
No external UART or test pads. USB programming retained. ICM INT1 NC; FIFO polling. BOOT / RESET retained.

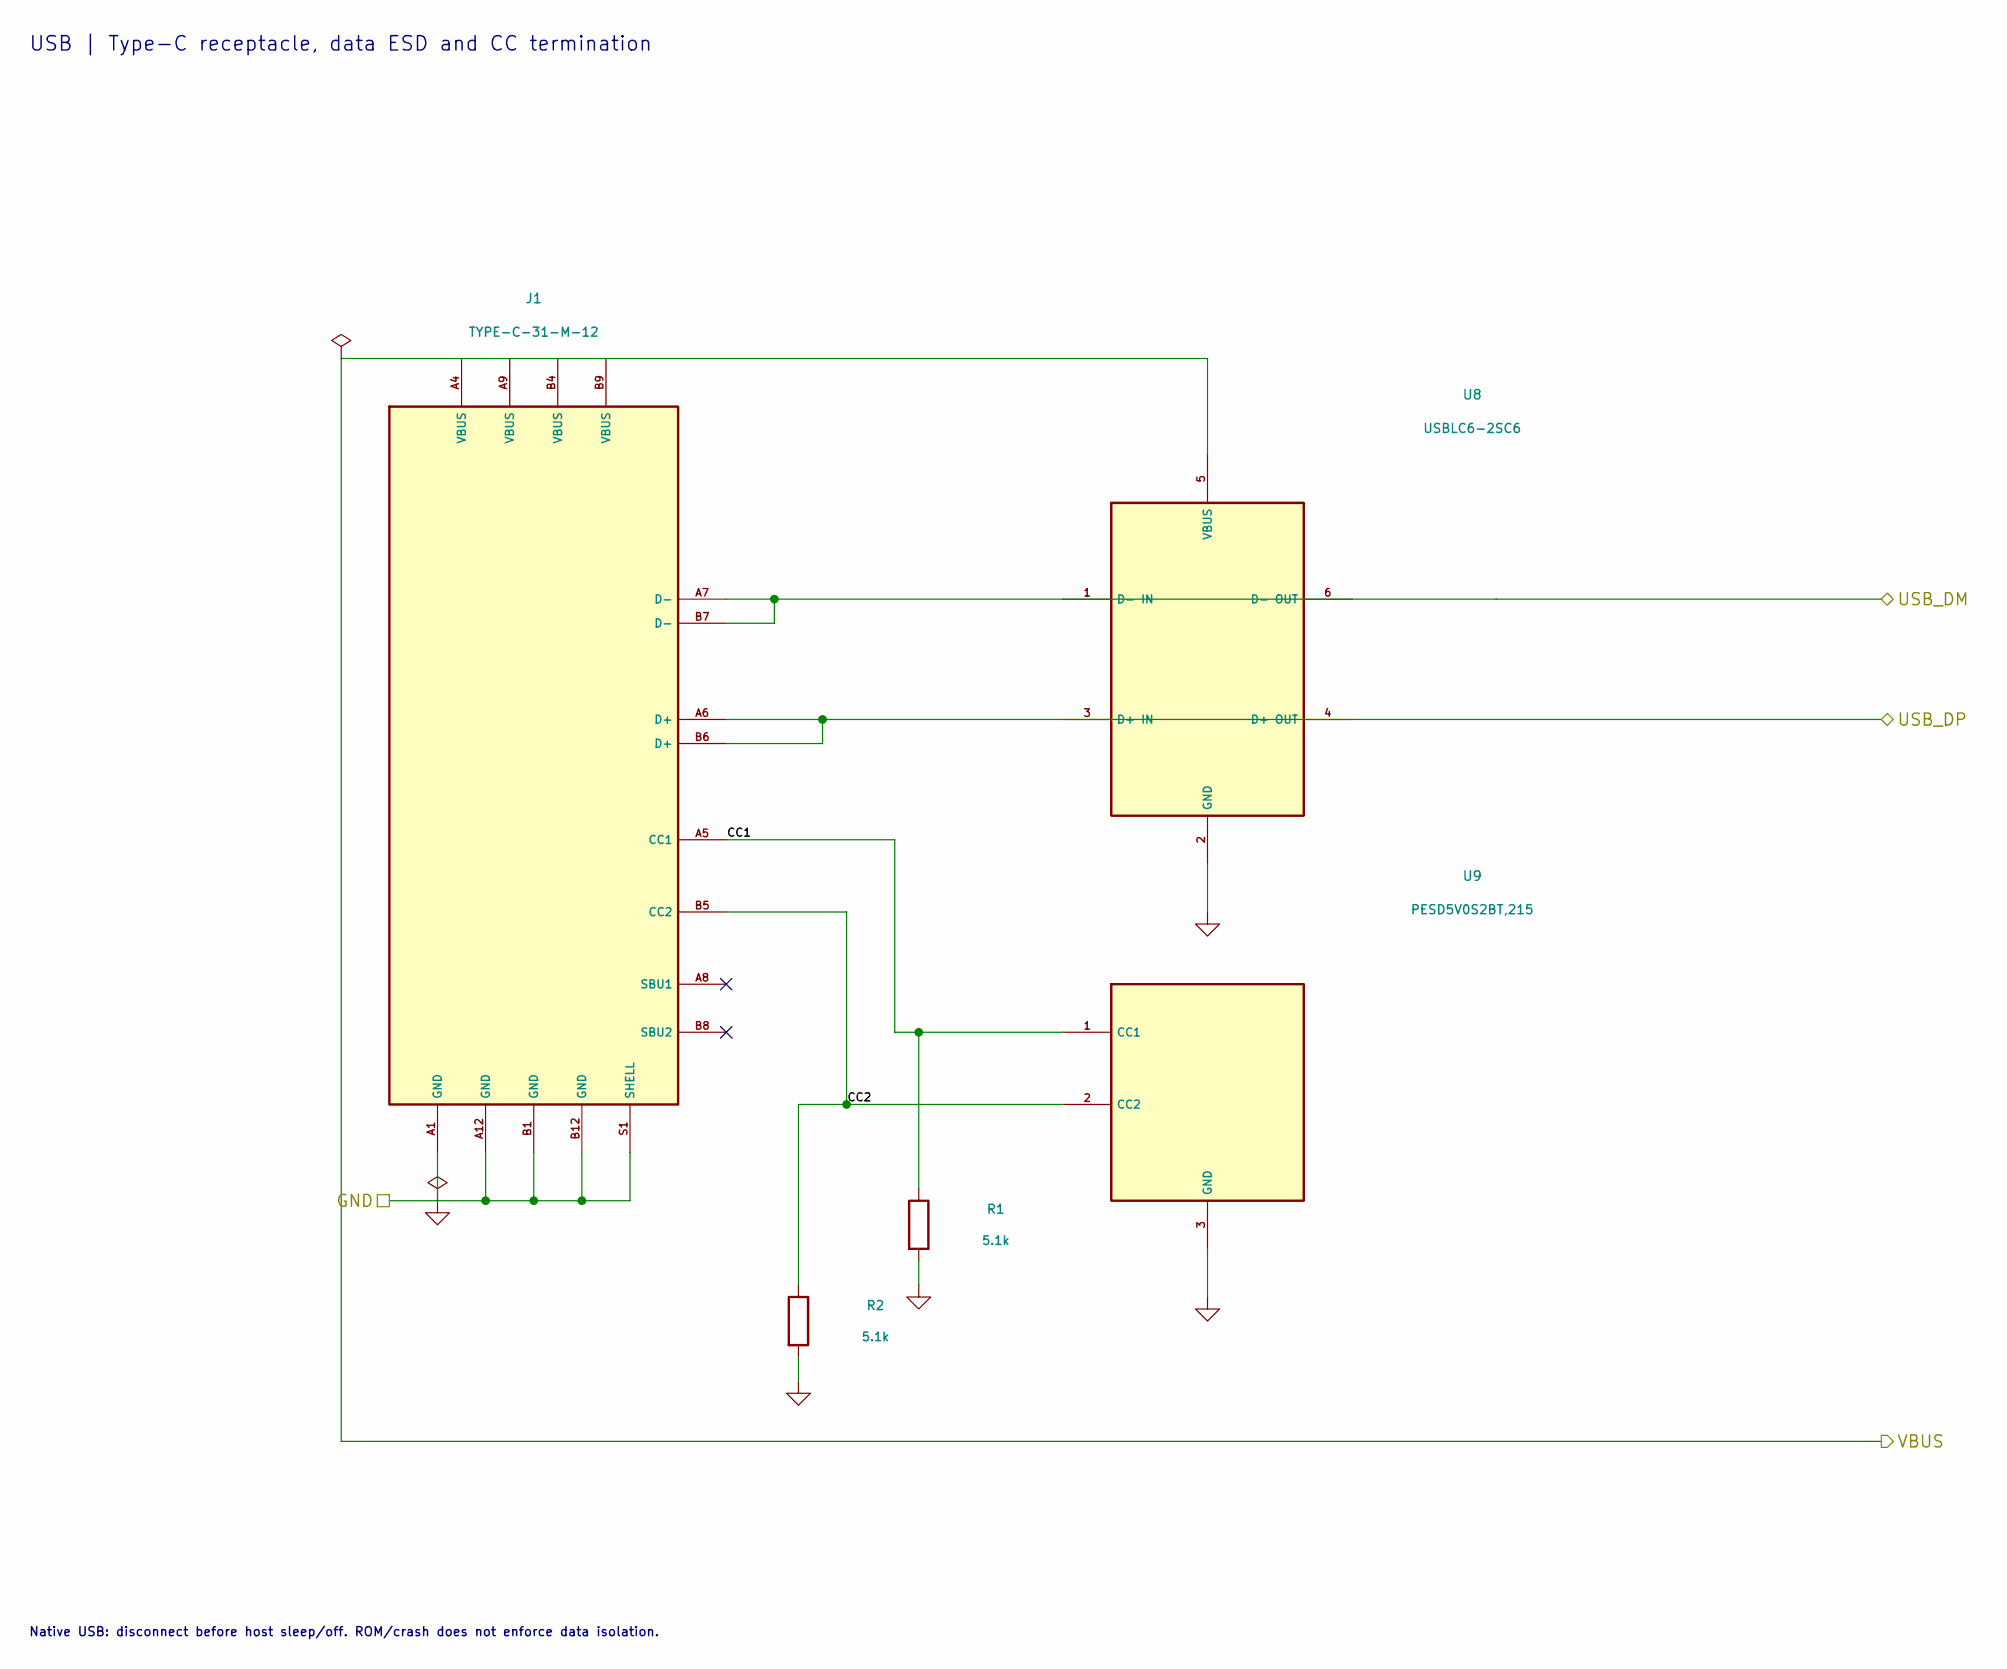
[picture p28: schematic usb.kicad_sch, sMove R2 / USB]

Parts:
J1: TYPE-C-31-M-12; USB_C_Receptacle_HRO_TYPE-C-31-M-12; MPN TYPE-C-31-M-12; LCSC C165948
R1, R2: 5.1k; R_0402_1005Metric; MPN 0402WGF5101TCE; LCSC C25905
U8: USBLC6-2SC6; SOT-23-6; MPN USBLC6-2SC6; LCSC C7519
U9: PESD5V0S2BT,215; SOT-23; MPN PESD5V0S2BT,215; LCSC C49338

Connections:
/USB/CC1: J1.A5 (CC1), R1.1, U9.1 (CC1)
/USB/CC2: J1.B5 (CC2), R2.1, U9.2 (CC2)
/USB_DM: J1.A7 (D-), J1.B7 (D-), U8.1 (D-_IN), U8.6 (D-_OUT); also elsewhere on the board
/USB_DP: J1.A6 (D+), J1.B6 (D+), U8.3 (D+_IN), U8.4 (D+_OUT); also elsewhere on the board
/VBUS: J1.A4 (VBUS), J1.A9 (VBUS), J1.B4 (VBUS), J1.B9 (VBUS), U8.5 (VBUS); also elsewhere on the board
GND: J1.A1 (GND), J1.A12 (GND), J1.B1 (GND), J1.B12 (GND), J1.S1 (SHELL), R1.2, R2.2, U8.2 (GND), U9.3 (GND); also elsewhere on the board

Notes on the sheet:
Native USB: disconnect before host sleep/off. ROM/crash does not enforce data isolation.
USB | Type-C receptacle, data ESD and CC termination

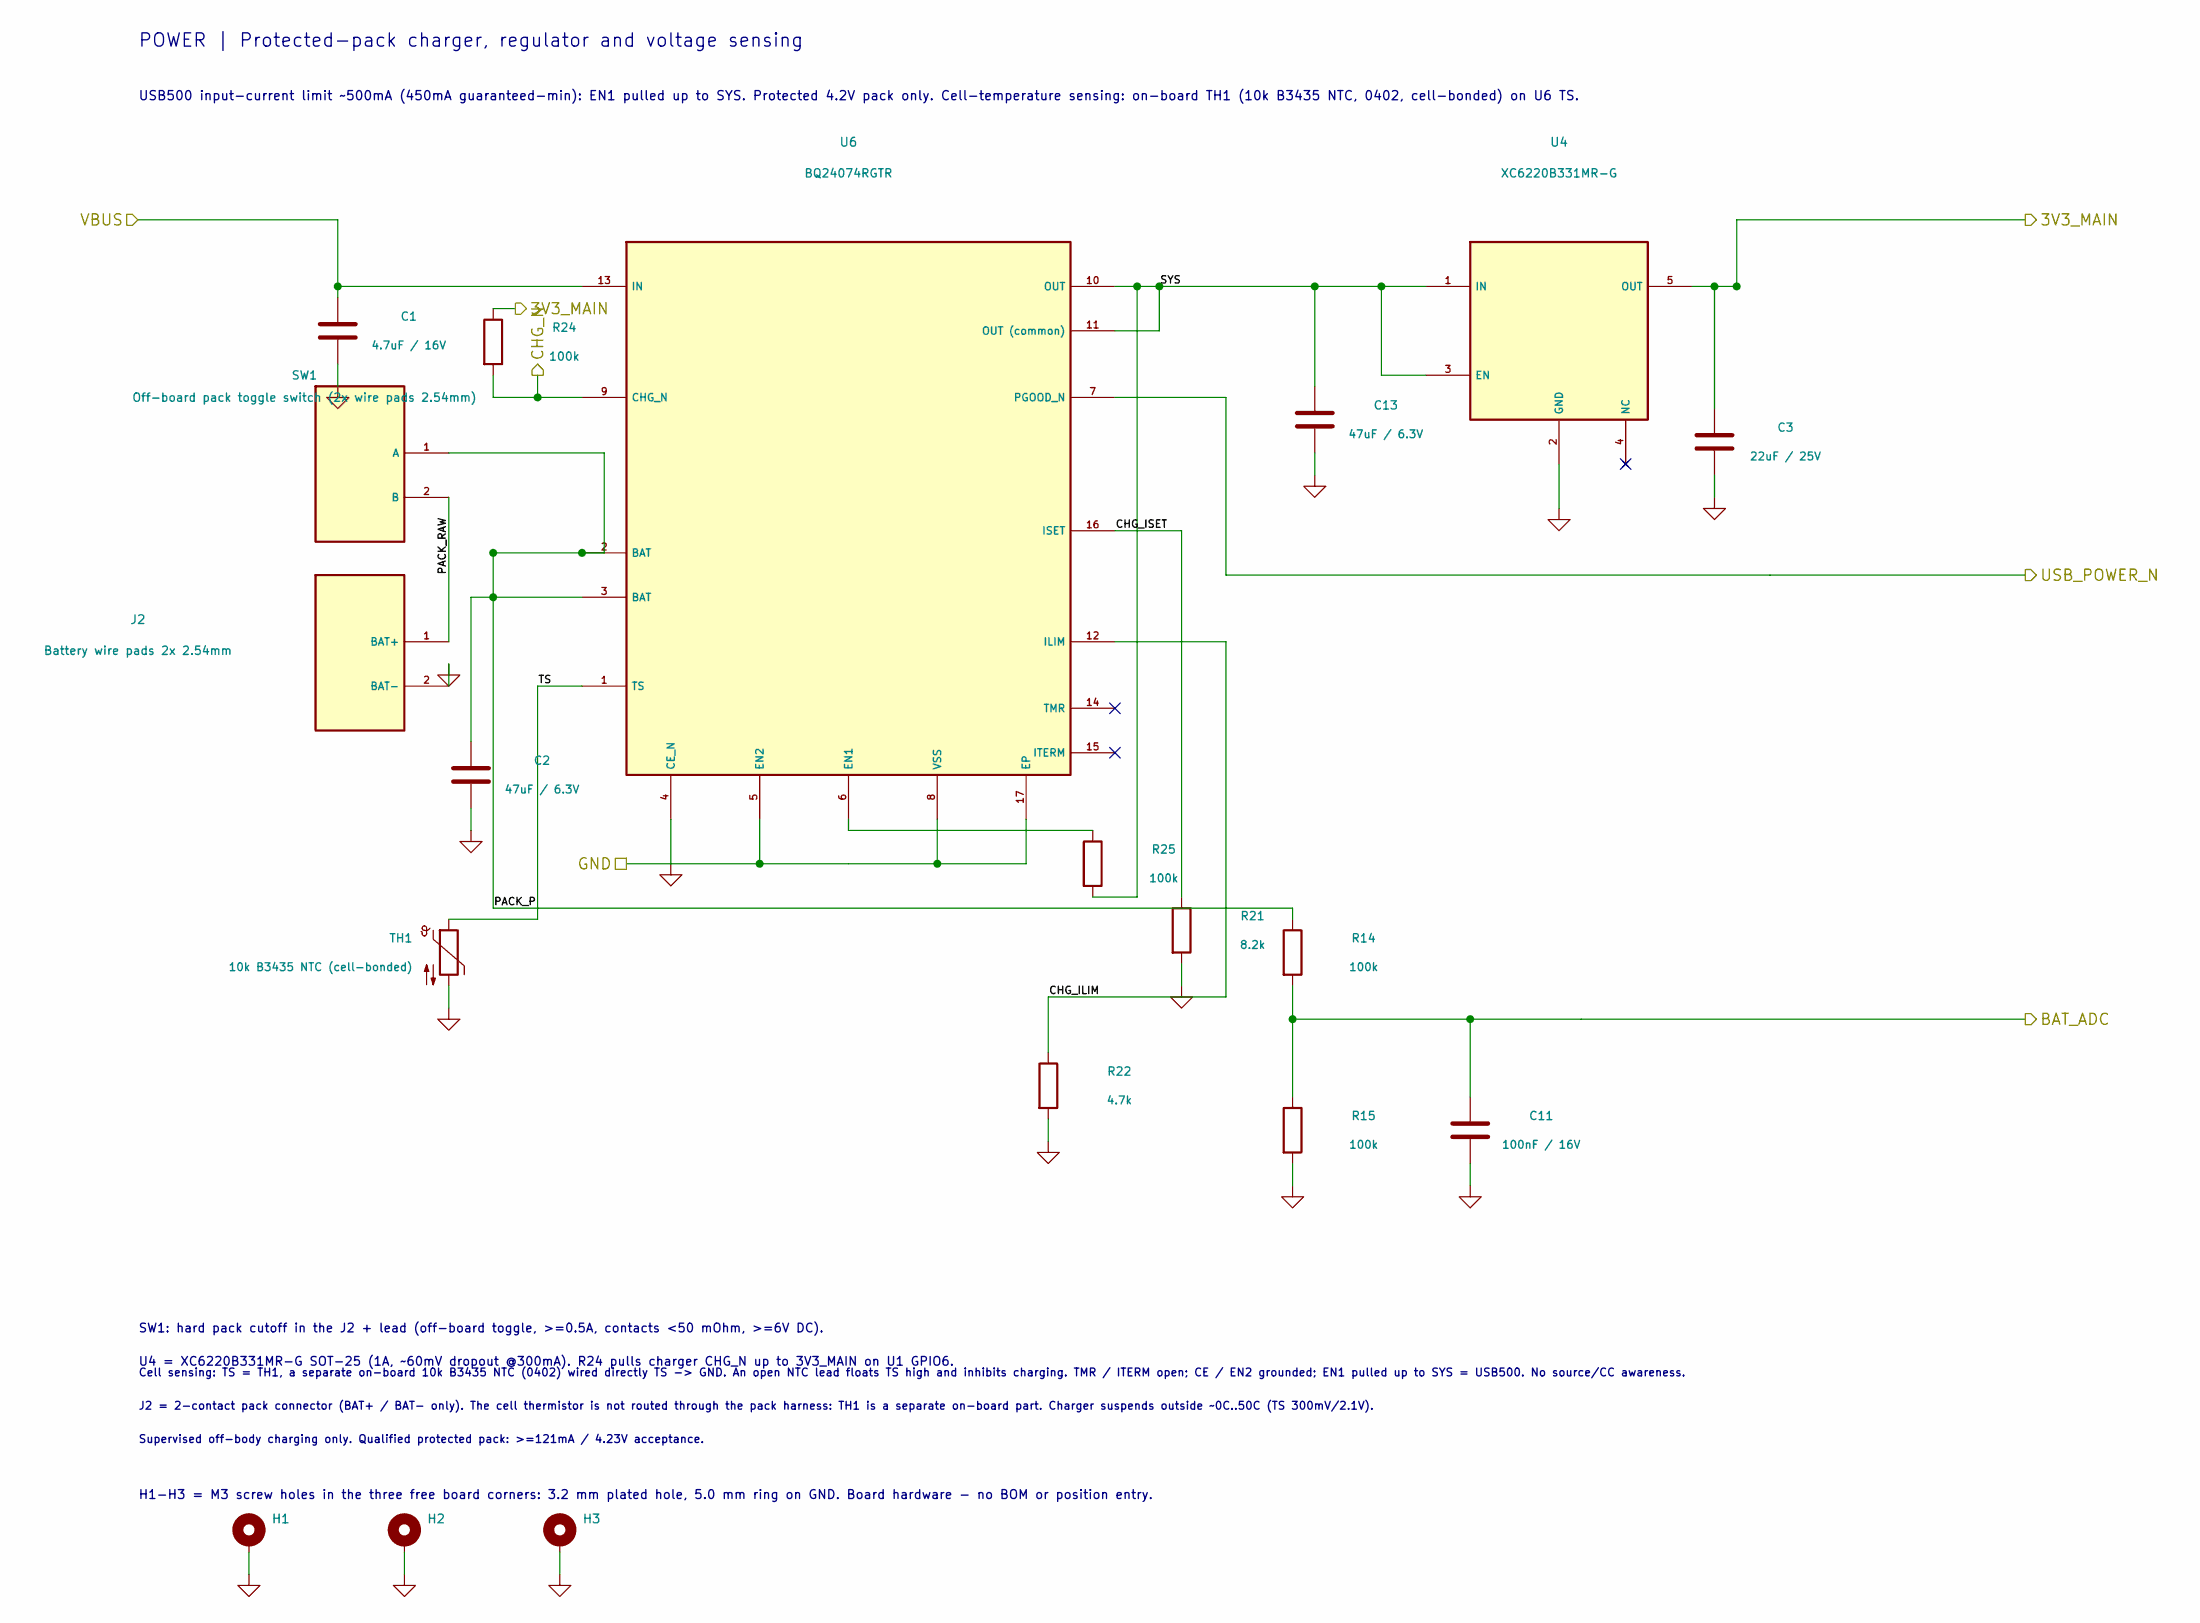
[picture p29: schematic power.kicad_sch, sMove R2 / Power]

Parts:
C1: 4.7uF / 16V; C_0603_1608Metric; MPN CL10A475KO8NNNC; LCSC C19666
C2, C13: 47uF / 6.3V; C_0805_2012Metric; MPN CL21A476MQYNNNE; LCSC C16780
C3: 22uF / 25V; C_0805_2012Metric; MPN CL21A226MAQNNNE; LCSC C45783
C11: 100nF / 16V; C_0402_1005Metric; MPN CL05B104KO5NNNC; LCSC C1525
H1, H2, H3: MountingHole_3.2mm_M3_Pad_5mm
J2: Battery wire pads 2x 2.54mm; BatteryWire_2x_PTH_P2.54mm_D1.0mm
R14, R15, R24, R25: 100k; R_0402_1005Metric; MPN 0402WGF1003TCE; LCSC C25741
R21: 8.2k; R_0402_1005Metric; MPN 0402WGF8201TCE; LCSC C25924
R22: 4.7k; R_0402_1005Metric; MPN 0402WGF4701TCE; LCSC C25900
SW1: Off-board pack toggle switch (2x wire pads 2.54mm); BatteryWire_2x_PTH_P2.54mm_D1.0mm
TH1: 10k B3435 NTC (cell-bonded); NTC_0402_1005Metric; MPN NTCG103JF103FT1; LCSC C209959
U4: XC6220B331MR-G; SOT-25_XC6220; MPN XC6220B331MR-G; LCSC C86534
U6: BQ24074RGTR; BQ24074_RGT; MPN BQ24074RGTR; LCSC C54313

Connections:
/3V3_MAIN: C3.1, R24.1, U4.5 (OUT); also elsewhere on the board
/BAT_ADC: C11.1, R14.2, R15.1; also elsewhere on the board
/CHG_N: R24.2, U6.9 (CHG_N); also elsewhere on the board
/Power/CHG_ILIM: R22.1, U6.12 (ILIM)
/Power/CHG_ISET: R21.1, U6.16 (ISET)
/Power/PACK_P: C2.1, R14.1, SW1.1 (A), U6.2 (BAT), U6.3 (BAT)
/Power/PACK_RAW: J2.1 (BAT+), SW1.2 (B)
/Power/SYS: C13.1, R25.2, U4.1 (IN), U4.3 (EN), U6.10 (OUT), U6.11 (OUT_(common))
/Power/TS: TH1.1, U6.1 (TS)
/USB_POWER_N: U6.7 (PGOOD_N); also elsewhere on the board
/VBUS: C1.1, U6.13 (IN); also elsewhere on the board
GND: C1.2, C2.2, C3.2, C11.2, C13.2, H1.1, H2.1, H3.1, J2.2 (BAT-), R15.2, R21.2, R22.2, TH1.2, U4.2 (GND), U6.4 (CE_N), U6.5 (EN2), U6.8 (VSS), U6.17 (EP); also elsewhere on the board
unnamed: R25.1, U6.6 (EN1)

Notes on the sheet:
USB500 input-current limit ~500mA (450mA guaranteed-min): EN1 pulled up to SYS. Protected 4.2V pack only. Cell-temperature sensing: on-board TH1 (10k B3435 NTC, 0402, cell-bonded) on U6 TS.
Cell sensing: TS = TH1, a separate on-board 10k B3435 NTC (0402) wired directly TS -> GND. An open NTC lead floats TS high and inhibits charging. TMR / ITERM open; CE / EN2 grounded; EN1 pulled up to SYS = USB500. No source/CC awareness.
J2 = 2-contact pack connector (BAT+ / BAT- only). The cell thermistor is not routed through the pack harness: TH1 is a separate on-board part. Charger suspends outside ~0C..50C (TS 300mV/2.1V).
Supervised off-body charging only. Qualified protected pack: >=121mA / 4.23V acceptance.
POWER | Protected-pack charger, regulator and voltage sensing
SW1: hard pack cutoff in the J2 + lead (off-board toggle, >=0.5A, contacts <50 mOhm, >=6V DC).
U4 = XC6220B331MR-G SOT-25 (1A, ~60mV dropout @300mA). R24 pulls charger CHG_N up to 3V3_MAIN on U1 GPIO6.
H1-H3 = M3 screw holes in the three free board corners: 3.2 mm plated hole, 5.0 mm ring on GND. Board hardware - no BOM or position entry.

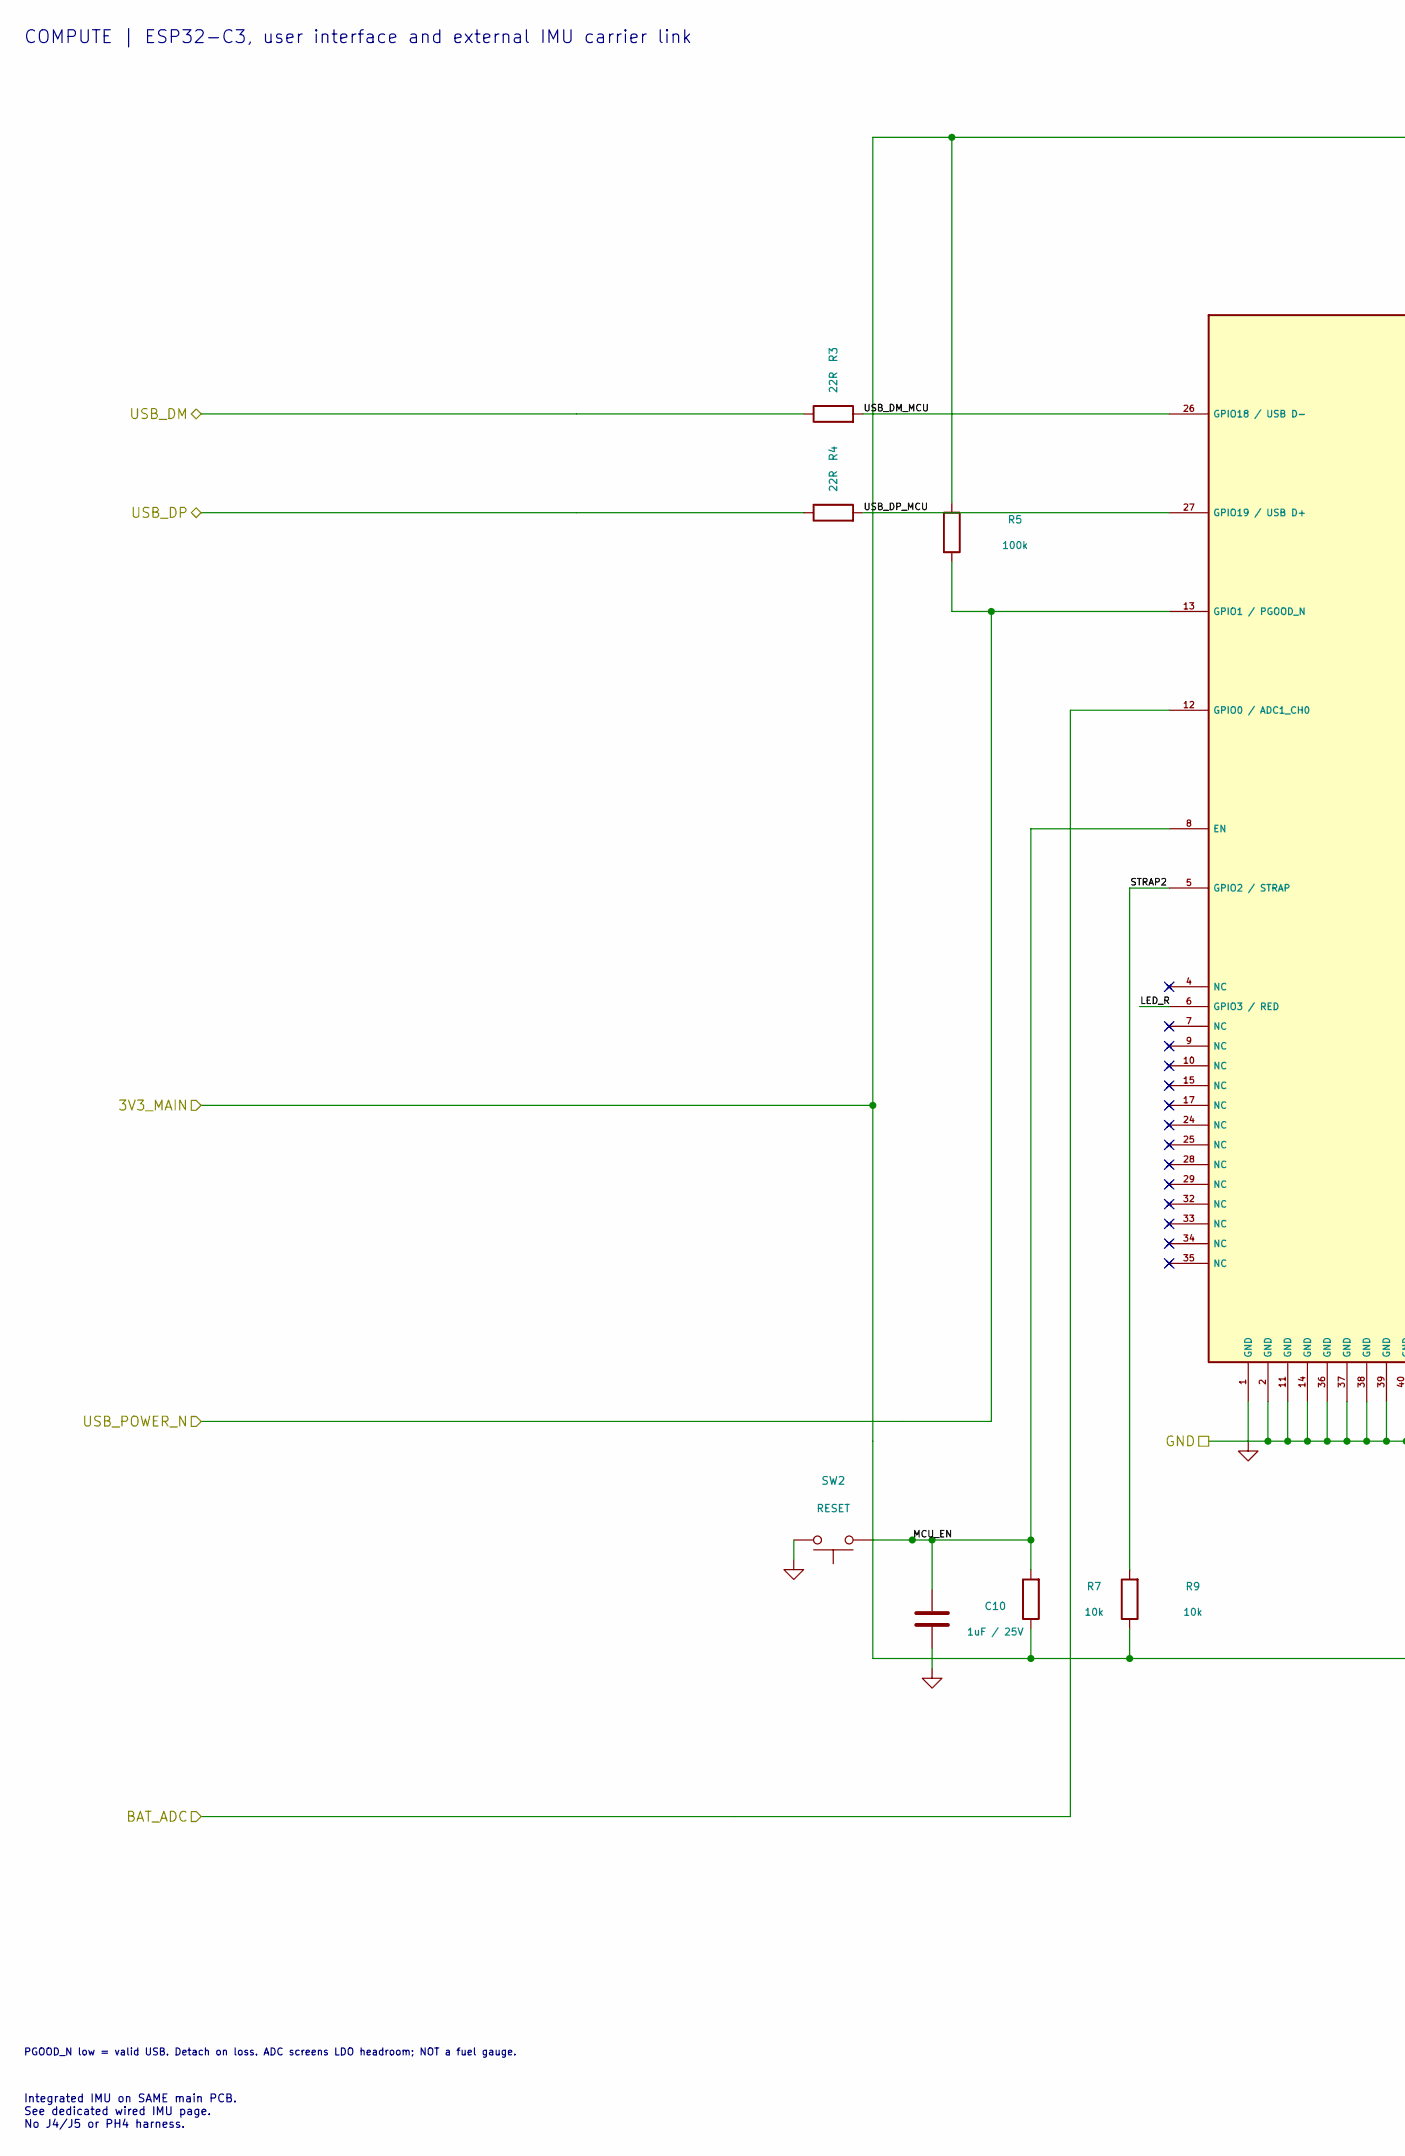
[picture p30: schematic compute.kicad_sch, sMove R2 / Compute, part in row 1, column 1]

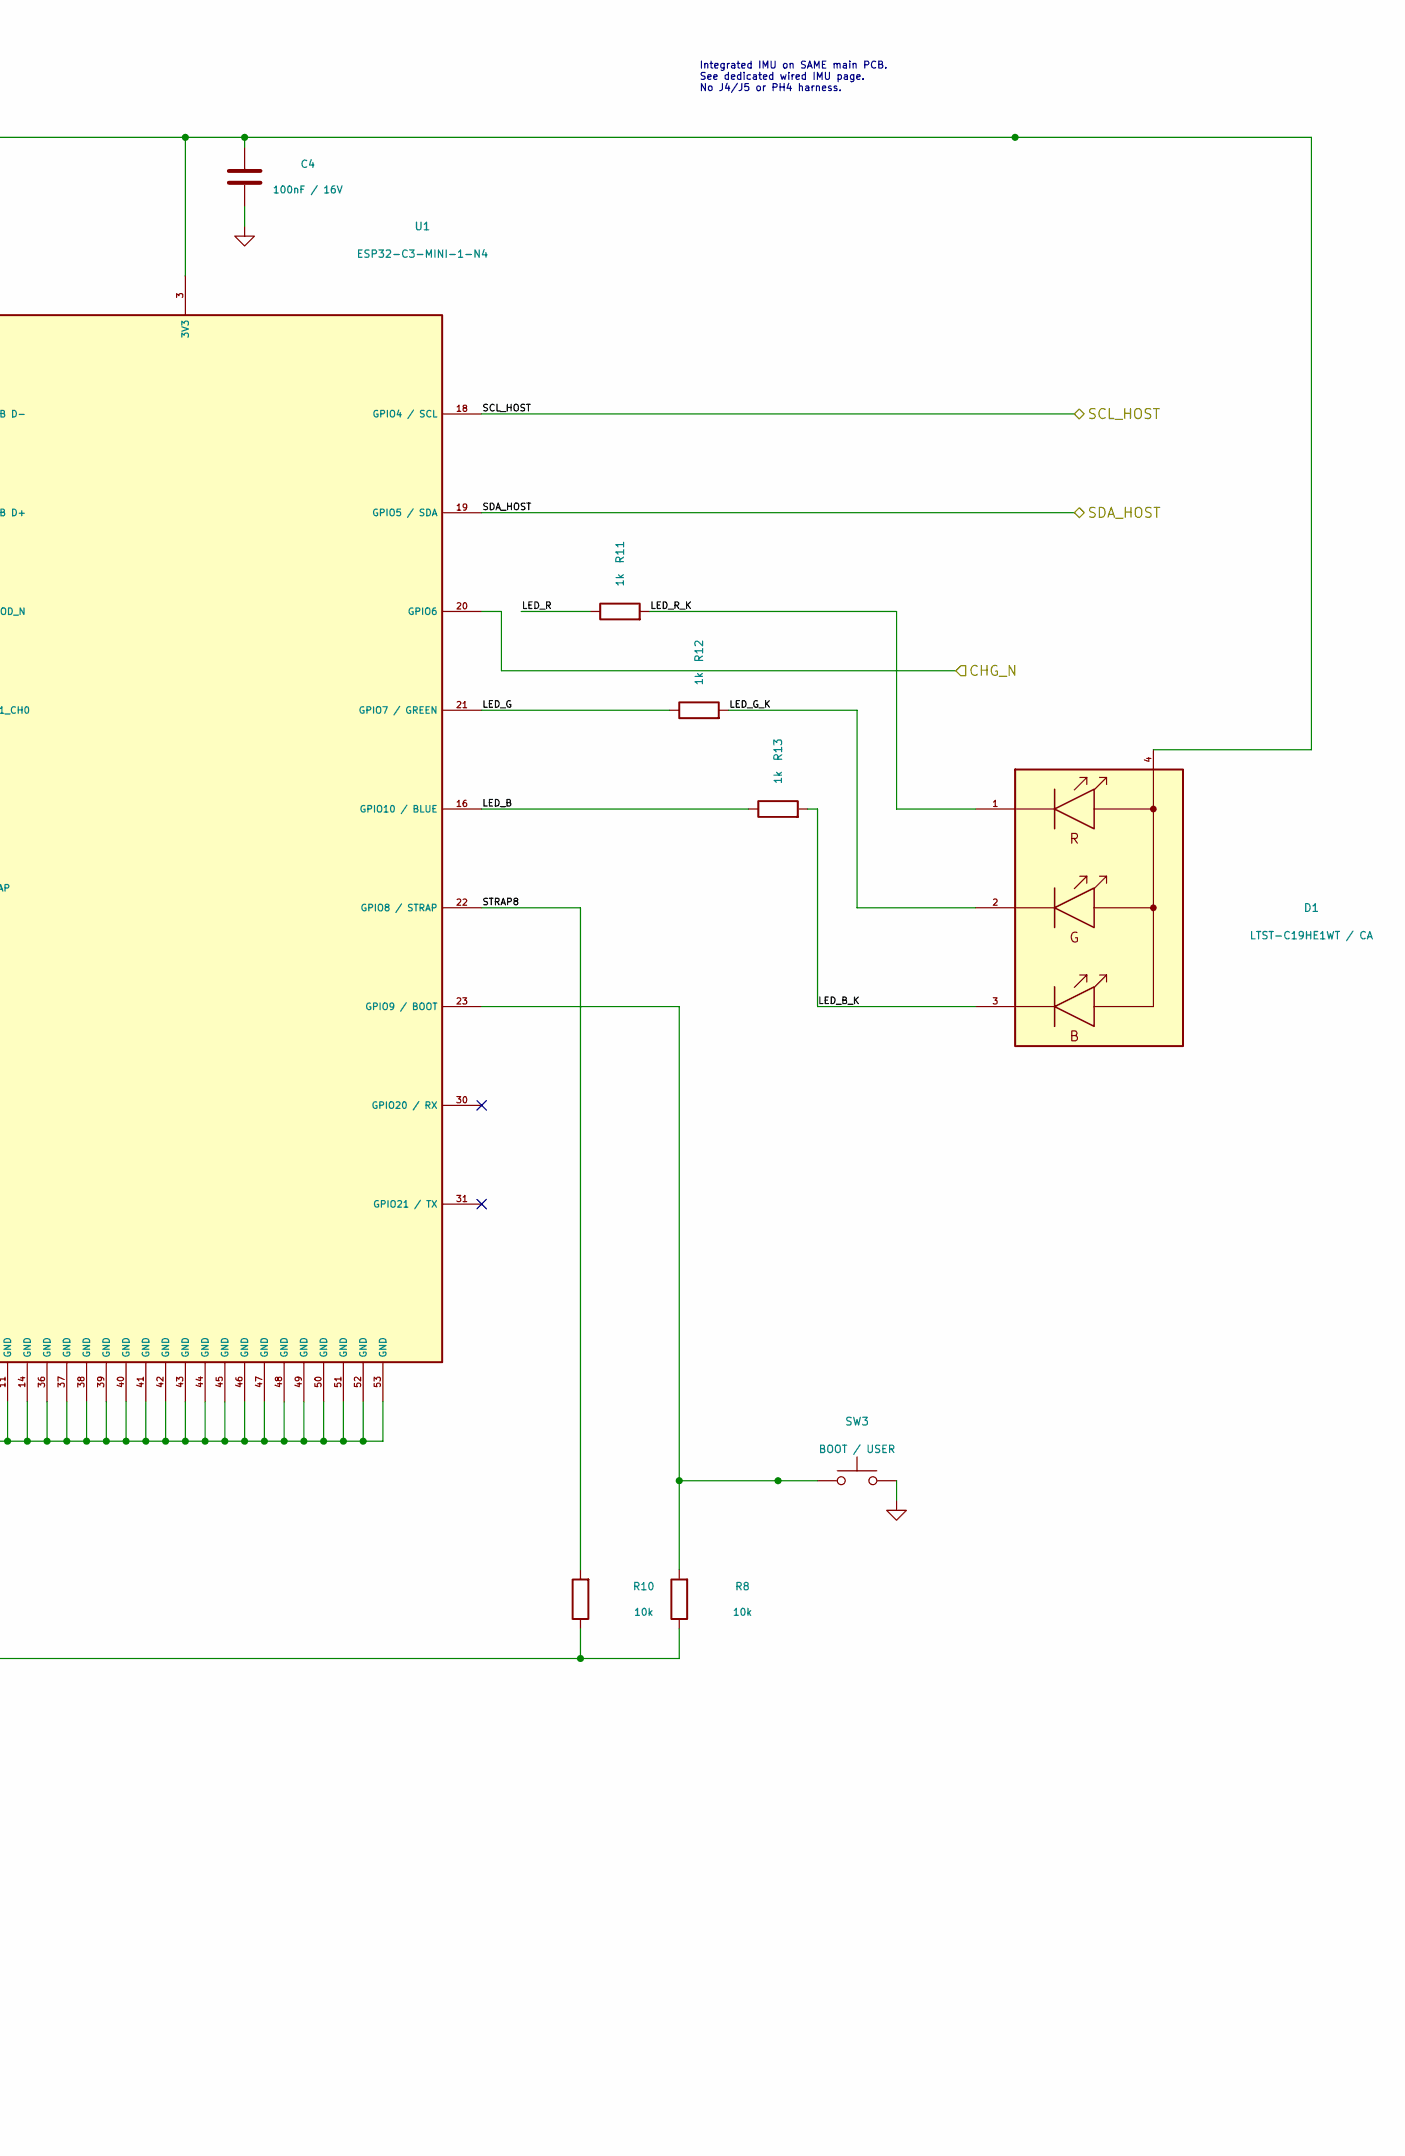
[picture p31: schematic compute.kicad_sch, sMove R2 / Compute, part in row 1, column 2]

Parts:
C4: 100nF / 16V; C_0402_1005Metric; MPN CL05B104KO5NNNC; LCSC C1525
C10: 1uF / 25V; C_0402_1005Metric; MPN CL05A105KA5NQNC; LCSC C52923
D1: LTST-C19HE1WT / CA; LED_LiteOn_LTST-C19HE1WT; MPN LTST-C19HE1WT; LCSC C458749
R3, R4: 22R; R_0402_1005Metric; MPN 0402WGF220JTCE; LCSC C25092
R5: 100k; R_0402_1005Metric; MPN 0402WGF1003TCE; LCSC C25741
R7, R8, R9, R10: 10k; R_0402_1005Metric; MPN 0402WGF1002TCE; LCSC C25744
R11, R12, R13: 1k; R_0402_1005Metric; MPN 0402WGF1001TCE; LCSC C11702
SW2: RESET; TS1088; MPN TS-1088-AR02016; LCSC C720477
SW3: BOOT / USER; TS1088; MPN TS-1088-AR02016; LCSC C720477
U1: ESP32-C3-MINI-1-N4; ESP32-C3-MINI-1; MPN ESP32-C3-MINI-1-N4; LCSC C2838502

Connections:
/3V3_MAIN: C4.1, D1.4 (A), R5.1, R7.1, R8.1, R9.1, R10.1, U1.3 (3V3); also elsewhere on the board
/BAT_ADC: U1.12 (GPIO0_/_ADC1_CH0); also elsewhere on the board
/CHG_N: U1.20 (GPIO6); also elsewhere on the board
/Compute/LED_B: R13.1, U1.16 (GPIO10_/_BLUE)
/Compute/LED_B_K: D1.3 (B_K), R13.2
/Compute/LED_G: R12.1, U1.21 (GPIO7_/_GREEN)
/Compute/LED_G_K: D1.2 (G_K), R12.2
/Compute/LED_R: R11.1, U1.6 (GPIO3_/_RED)
/Compute/LED_R_K: D1.1 (R_K), R11.2
/Compute/MCU_EN: C10.1, R7.2, SW2.1, U1.8 (EN)
/Compute/STRAP2: R9.2, U1.5 (GPIO2_/_STRAP)
/Compute/STRAP8: R10.2, U1.22 (GPIO8_/_STRAP)
/Compute/USB_DM_MCU: R3.2, U1.26 (GPIO18_/_USB_D-)
/Compute/USB_DP_MCU: R4.2, U1.27 (GPIO19_/_USB_D+)
/SCL_HOST: U1.18 (GPIO4_/_SCL); also elsewhere on the board
/SDA_HOST: U1.19 (GPIO5_/_SDA); also elsewhere on the board
/USB_DM: R3.1; also elsewhere on the board
/USB_DP: R4.1; also elsewhere on the board
/USB_POWER_N: R5.2, U1.13 (GPIO1_/_PGOOD_N); also elsewhere on the board
GND: C4.2, C10.2, SW2.2, SW3.2, U1.1 (GND), U1.2 (GND), U1.11 (GND), U1.14 (GND), U1.36 (GND), U1.37 (GND), U1.38 (GND), U1.39 (GND), U1.40 (GND), U1.41 (GND), U1.42 (GND), U1.43 (GND), U1.44 (GND), U1.45 (GND), U1.46 (GND), U1.47 (GND), U1.48 (GND), U1.49 (GND), U1.50 (GND), U1.51 (GND), U1.52 (GND), U1.53 (GND); also elsewhere on the board
unnamed: R8.2, SW3.1, U1.23 (GPIO9_/_BOOT)

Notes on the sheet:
COMPUTE | ESP32-C3, user interface and external IMU carrier link
PGOOD_N low = valid USB. Detach on loss. ADC screens LDO headroom; NOT a fuel gauge.
Integrated IMU on SAME main PCB. See dedicated wired IMU page. No J4/J5 or PH4 harness.

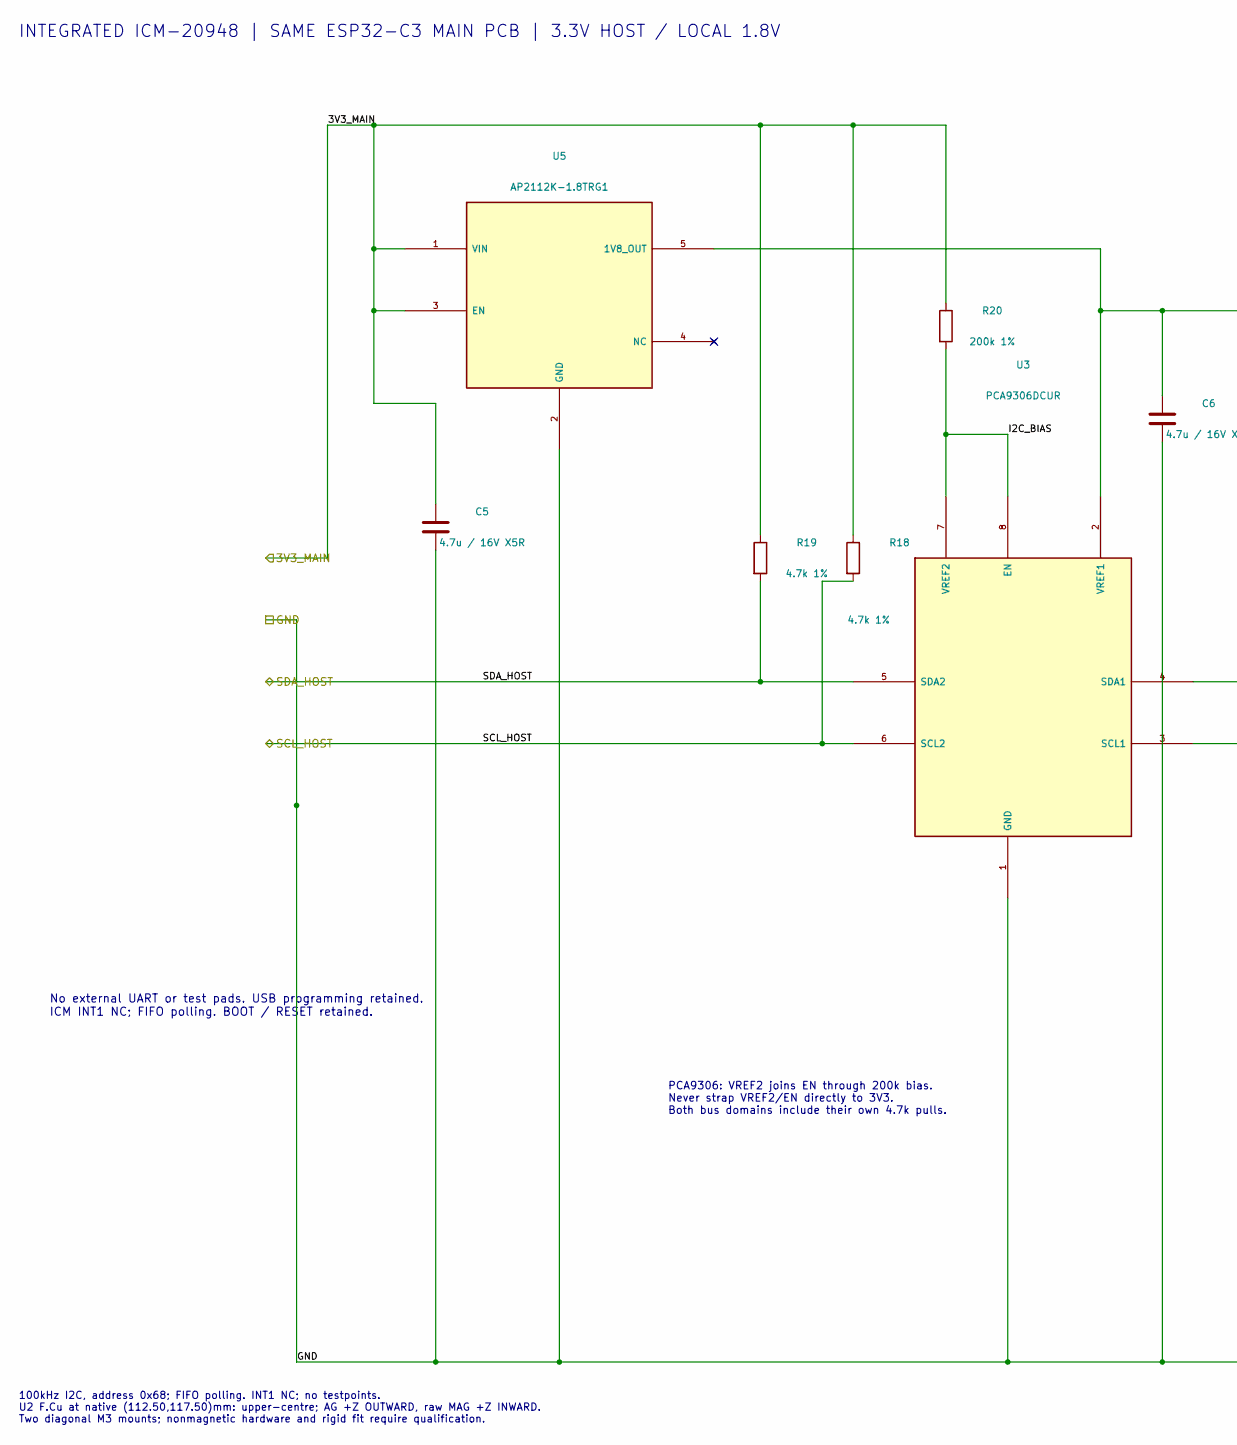
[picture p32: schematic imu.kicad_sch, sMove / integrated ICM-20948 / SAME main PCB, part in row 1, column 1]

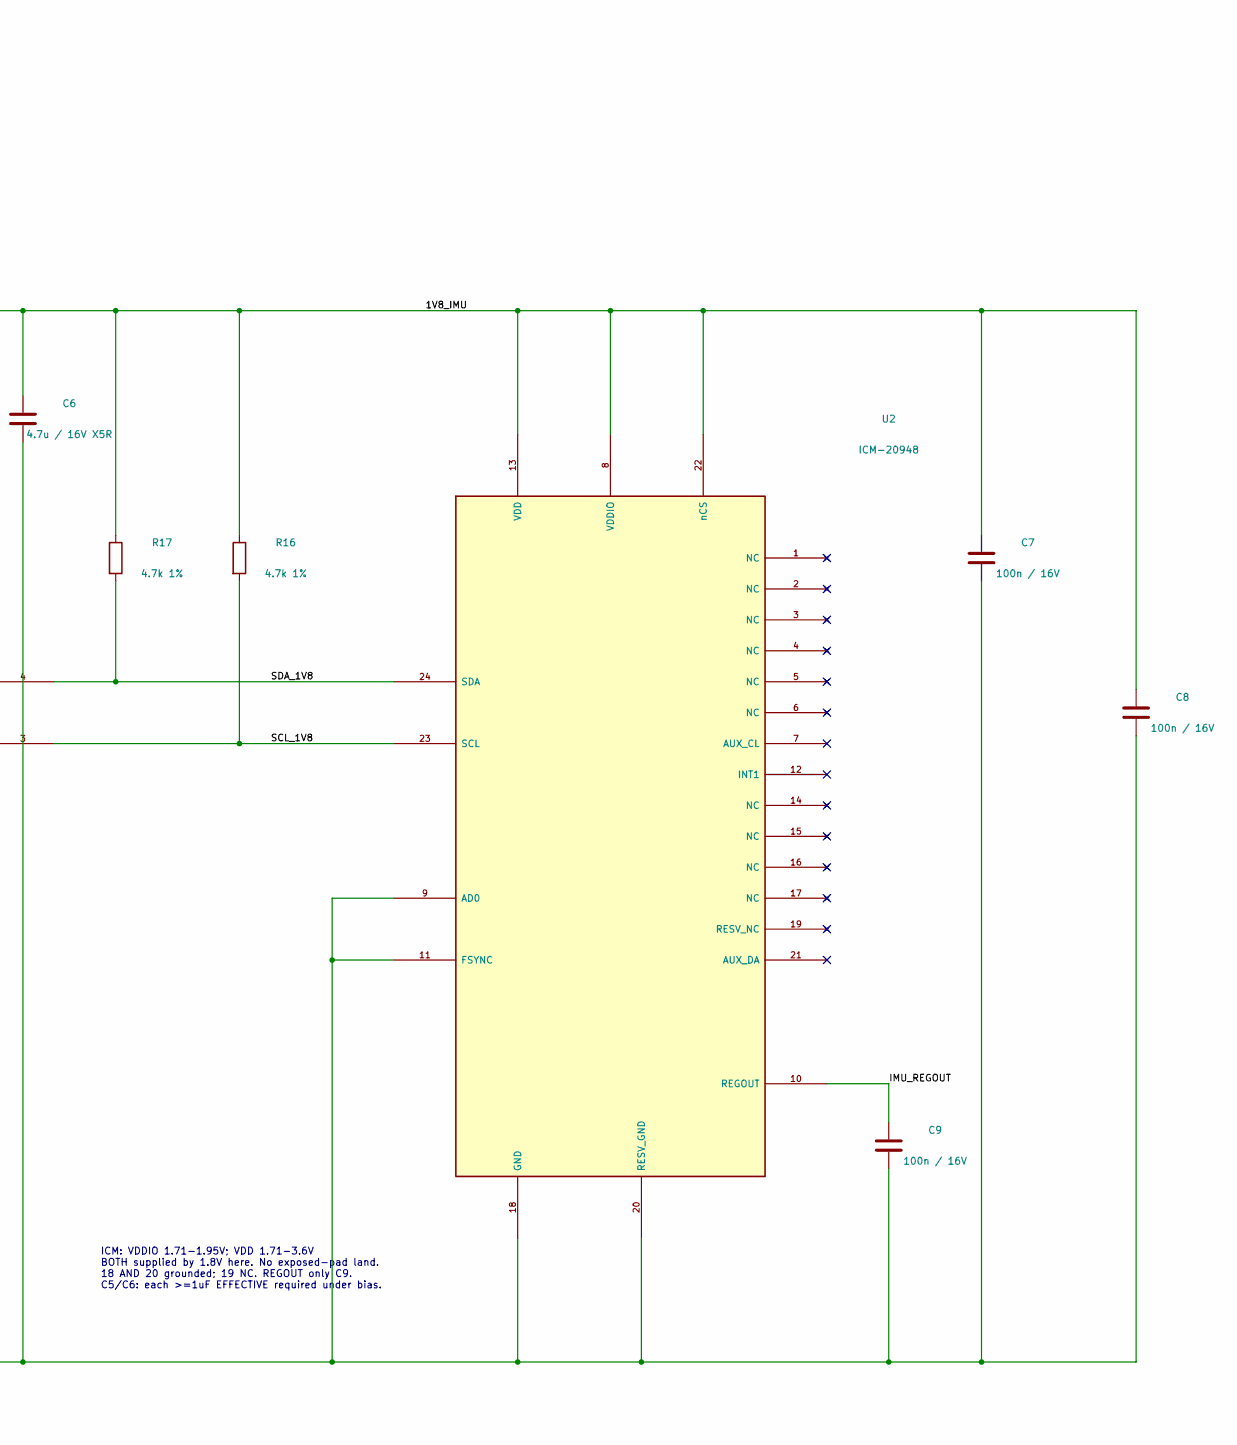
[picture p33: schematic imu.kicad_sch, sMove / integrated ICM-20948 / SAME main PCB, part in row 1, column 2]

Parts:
C5, C6: 4.7u / 16V X5R; C_0603_1608Metric; MPN CL10A475KO8NNNC; LCSC C19666
C7, C8, C9: 100n / 16V; C_0402_1005Metric; MPN CL05B104KO5NNNC; LCSC C1525
R16, R17, R18, R19: 4.7k 1%; R_0402_1005Metric; MPN 0402WGF4701TCE; LCSC C25900
R20: 200k 1%; R_0402_1005Metric; MPN 0402WGF2003TCE; LCSC C25764
U2: ICM-20948; InvenSense_QFN-24_3x3mm_P0.4mm; MPN ICM-20948; LCSC C726001
U3: PCA9306DCUR; PCA9306_DCU0008A; MPN PCA9306DCUR; LCSC C33196
U5: AP2112K-1.8TRG1; SOT-23-5; MPN AP2112K-1.8TRG1; LCSC C176944

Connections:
/3V3_MAIN: C5.1, R18.1, R19.1, R20.1, U5.1 (VIN), U5.3 (EN); also elsewhere on the board
/IMU/1V8_IMU: C6.1, C7.1, C8.1, R16.1, R17.1, U2.8 (VDDIO), U2.13 (VDD), U2.22 (nCS), U3.2 (VREF1), U5.5 (1V8_OUT)
/IMU/I2C_BIAS: R20.2, U3.7 (VREF2), U3.8 (EN)
/IMU/IMU_REGOUT: C9.1, U2.10 (REGOUT)
/IMU/SCL_1V8: R16.2, U2.23 (SCL), U3.3 (SCL1)
/IMU/SDA_1V8: R17.2, U2.24 (SDA), U3.4 (SDA1)
/SCL_HOST: R18.2, U3.6 (SCL2); also elsewhere on the board
/SDA_HOST: R19.2, U3.5 (SDA2); also elsewhere on the board
GND: C5.2, C6.2, C7.2, C8.2, C9.2, U2.9 (AD0), U2.11 (FSYNC), U2.18 (GND), U2.20 (RESV_GND), U3.1 (GND), U5.2 (GND); also elsewhere on the board

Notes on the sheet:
INTEGRATED ICM-20948 | SAME ESP32-C3 MAIN PCB | 3.3V HOST / LOCAL 1.8V
No external UART or test pads. USB programming retained. ICM INT1 NC; FIFO polling. BOOT / RESET retained.
PCA9306: VREF2 joins EN through 200k bias. Never strap VREF2/EN directly to 3V3. Both bus domains include their own 4.7k pulls.
ICM: VDDIO 1.71-1.95V; VDD 1.71-3.6V BOTH supplied by 1.8V here. No exposed-pad land. 18 AND 20 grounded; 19 NC. REGOUT only C9. C5/C6: each >=1uF EFFECTIVE required under bias.
100kHz I2C, address 0x68; FIFO polling. INT1 NC; no testpoints. U2 F.Cu at native (112.50,117.50)mm: upper-centre; AG +Z OUTWARD, raw MAG +Z INWARD. Two diagonal M3 mounts; nonmagnetic hardware and rigid fit require qualification.

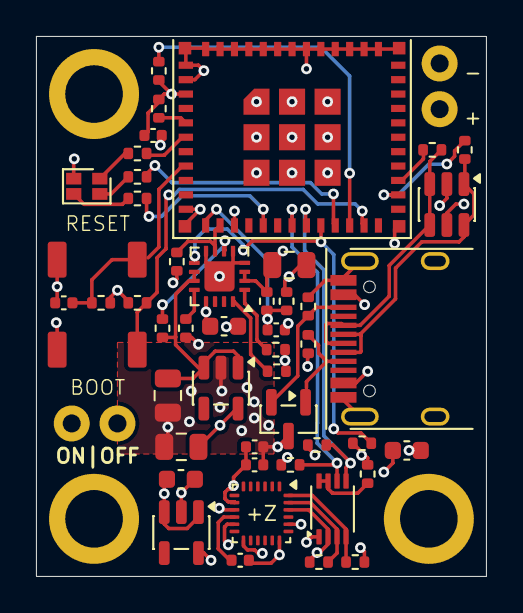
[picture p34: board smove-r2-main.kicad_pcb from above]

Board: 4 copper layers, 25.0 x 30.0 mm, 53 parts (0 on the bottom side), 36 nets.

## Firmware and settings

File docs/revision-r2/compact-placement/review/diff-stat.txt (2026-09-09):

Payload diff at review snapshot; this summary, generated diffs and outer manifest are excluded from their own diff. Complete changed-file list/count is in delivery-manifest.json.

 PCB/README.md                                                           |     9 +-
 PCB/main/README.md                                                      |    20 +-
 PCB/main/dist/ASSEMBLY.md                                               |    34 +-
 PCB/main/dist/assembly-placements.json                                  |   292 +-
 PCB/main/dist/assembly-top.pdf                                          |   Bin 71637 -> 70562 bytes
 PCB/main/dist/bottom-3d.png                                             |   Bin 62942 -> 70238 bytes
 PCB/main/dist/bottom.svg                                                |  7397 +++++++++++------------
 PCB/main/dist/conservative-step-frame.json                              |     2 +-
 PCB/main/dist/gerbers.zip                                               |   Bin 124103 -> 130675 bytes
 PCB/main/dist/gerbers/smove-r2-main-B_Cu.gbl                            |  6884 +++++++++++-----------
 PCB/main/dist/gerbers/smove-r2-main-B_Mask.gbs                          |     8 +-
 PCB/main/dist/gerbers/smove-r2-main-B_Silkscreen.gbo                    |   104 +-
 PCB/main/dist/gerbers/smove-r2-main-Edge_Cuts.gm1                       |    12 +-
 PCB/main/dist/gerbers/smove-r2-main-F_Cu.gtl                            | 11048 ++++++++++++++++++----------------
 PCB/main/dist/gerbers/smove-r2-main-F_Mask.gts                          |   200 +-
 PCB/main/dist/gerbers/smove-r2-main-F_Paste.gtp                         |   181 +-
 PCB/main/dist/gerbers/smove-r2-main-F_Silkscreen.gto                    |   766 ++-
 PCB/main/dist/gerbers/smove-r2-main-In1_Cu.g1                           |  5904 ++++++++++---------
 PCB/main/dist/gerbers/smove-r2-main-In2_Cu.g2                           |  5601 ++++++++++--------
 PCB/main/dist/gerbers/smove-r2-main-NPTH.drl                            |     5 +-
 PCB/main/dist/gerbers/smove-r2-main-PTH.drl                             |   127 +-
 PCB/main/dist/gerbers/smove-r2-main-job.gbrjob                          |     4 +-
 PCB/main/dist/main-board-only.step                                      |  1731 +++---
 PCB/main/dist/main-installed-models.step                                | 10861 +++++++++++++++++-----------------
 PCB/main/dist/main-populated-with-conservative-envelopes.step           | 31570 +++++++++++++++++++++++++++++++++++++++++++++++++-------------------------------------------------
 PCB/main/dist/manifest.json                                             |   124 +-
 PCB/main/dist/pick-and-place.csv                                        |    32 +-
 PCB/main/dist/schematic-svg/smove-r2-main-Compute.svg                   |     2 +-
 PCB/main/dist/schematic-svg/smove-r2-main-IMU.svg                       |     2 +-
 PCB/main/dist/schematic-svg/smove-r2-main-Power.svg                     |     2 +-
 PCB/main/dist/schematic-svg/smove-r2-main-USB.svg                       |     2 +-
 PCB/main/dist/schematic-svg/smove-r2-main.svg                           |     2 +-
 PCB/main/dist/schematic.pdf                                             |   Bin 570876 -> 570876 bytes
 PCB/main/dist/top-3d.png                                                |   Bin 122263 -> 139745 bytes
 PCB/main/dist/top.svg                                                   | 15789 ++++++++++++++++++++++++++-----------------------
 PCB/main/interface.json                                                 |   431 +-
 PCB/main/native-layout-contract.json                                    |   106 +-
 PCB/main/parts-main.json                                                |    78 +-
 PCB/main/smove-r2-main.kicad_pcb                                        | 16528 +++++++++++++++++++++++++++------------------------
 README.md                                                               |    14 +-
 docs/revision-r2/compact-placement/README.md                            |    73 +
 docs/revision-r2/compact-placement/images/A_32_two_M3.png               |   Bin 0 -> 48357 bytes
 docs/revision-r2/compact-placement/images/B_30_single_M3_keyed.png      |   Bin 0 -> 49679 bytes
 docs/revision-r2/compact-placement/images/C_29_single_M3_tight.png      |   Bin 0 -> 48616 bytes
 docs/revision-r2/compact-placement/images/before-dimensions.png         |   Bin 0 -> 22348 bytes
 docs/revision-r2/compact-placement/images/before-housing.png            |   Bin 0 -> 101463 bytes
 docs/revision-r2/compact-placement/images/before-pcb.png                |   Bin 0 -> 122263 bytes
 docs/revision-r2/compact-placement/images/housing-comparison.png        |   Bin 0 -> 241853 bytes
 docs/revision-r2/compact-placement/images/pcb-comparison.png            |   Bin 0 -> 329213 bytes
 docs/revision-r2/compact-placement/images/switch-drawing.png            |   Bin 0 -> 271069 bytes
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

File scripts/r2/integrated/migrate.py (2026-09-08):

#!/usr/bin/python3
"""Explicit, reproducible R2-to-integrated ECO from c1050a0 native sources.
Overwrites main schematic/layout ONLY with --apply; routing is a separate checked step.
Carrier remains a frozen reference, NOT part of the integrated assembly/BOM.
"""
if __name__ == '__main__':
 raise SystemExit('Historical destructive ECO helper disabled for the finalized layout; see integrated/README.md native-CAD rebuild workflow.')
from pathlib import Path
import argparse, copy, json, subprocess as sp, shutil
from sexp import *
ROOT=Path(__file__).resolve().parents[3]; H=ROOT/'PCB/main'; C=ROOT/'PCB/imu-carrier'
BASE='c1050a07339897e7203f43137aec96de5bbc41cc'
TOP='8e261347-838a-5848-981d-f693675e8aa0'; COMP='eeb5ed75-de0b-5a0c-8356-c78aafd0bbd1'; IMU=uid('sheet-imu')
def old(path):return sp.check_output(['git','show',BASE+':'+path],cwd=ROOT,text=True)
def save(path,a):path.write_text(dump(a)+'\n')
def wire(a,b):return node(f'(wire (pts (xy {a[0]} {a[1]}) (xy {b[0]} {b[1]})) (stroke (width 0) (type default)) (uuid {uid((a,b))}))')
def label(name,xy,kind='label',shape='passive',angle=0):
 return node(f'({kind} {q(name)} '+(f'(shape {shape}) ' if kind=='hierarchical_label' else '')+f'(at {xy[0]} {xy[1]} {angle}) (effects (font (size 1.27 1.27)) (justify left bottom)) (uuid {uid((name,xy,kind))}))')
def text(s,xy,size=1.27):return node(f'(text {q(s)} (at {xy[0]} {xy[1]} 0) (effects (font (size {size} {size})) (justify left)) (uuid {uid((s,xy))}))')
def tp_symbol():return node('''(symbol "debug:TestPad" (pin_names (offset 0) (hide yes)) (in_bom no) (on_board yes)
(property "Reference" "TP" (at 0 4 0) (effects (font (size 1.27 1.27))))
(property "Value" "TestPad" (at 0 6 0) (effects (font (size 1.27 1.27))))
(symbol "TestPad_0_1" (circle (center 0 2) (radius 1) (stroke (width .2) (type default)) (fill (type none))))
(symbol "TestPad_1_1" (pin passive line (at 0 0 90) (length 1) (name "1" (effects (font (size 1 1)))) (number "1" (effects (font (size 1 1)))))))''')
# Existing service header J3 remains; duplicate convenient power/bus test pads are NO BOM/NO paste.
TP=[('TP1','GND','Power',101.5,136.5),('TP2','VBUS','Power',105,136.5),('TP3','PACK_P','Power',108.5,136.5),
 ('TP4','SYS','Power',112,136.5),('TP5','3V3_MAIN','Compute',115.5,136.5),('TP6','MCU_EN','Compute',119,136.5),
 ('TP7','BOOT','Compute',122.5,136.5),('TP8','UART_RX','Compute',123.5,110.8),('TP9','UART_TX','Compute',121,111.8),
 ('TP10','SCL_HOST','IMU',103,134),('TP11','SDA_HOST','IMU',105.5,134),
 ('TP12','1V8_IMU','IMU',101.5,131.5),('TP13','GND','IMU',107.8,131.7),('TP14','INT1_1V8','IMU',108.7,128)]

def schematic():
 root=parse(old('PCB/main/smove-r2-main.kicad_sch')); comp=parse(old('PCB/main/compute.kicad_sch'))
 imu=parse((C/'smove-imu-carrier.kicad_sch').read_text())
 for a in [root,comp]:
  for t in many(a,'text'):
   if 'separate' in val(t[1]) or 'PH4:' in val(t[1]) or 'No nested' in val(t[1]): t[1]=q('Integrated IMU on SAME main PCB.\nSee dedicated wired IMU page.\nNo J4/J5 or PH4 harness.')
   if 'three functional' in val(t[1]):t[1]=q('One main PCB, four functional pages. Green lines are actual hierarchical connections.')
   if 'Placement and routing unchanged' in val(t[1]):t[1]=q('Crossings without junction dots are NOT connected. Engineering prototype; release gated.')
 one(root,'paper')[1]=q('A3')
 one(one(root,'title_block'),'comment')[2]=q('MAIN PCB - USB / POWER / COMPUTE / INTEGRATED IMU')
 # Remove only former connector and its dead supply/ground ends; preserve shared D1 supply rail.
 comp[:]=[x for x in comp if not(isinstance(x,list) and x[0]=='symbol' and prop(x,'Reference') in ['J4','#PWR6','#PWR7'])]
 for w in many(comp,'wire'):
  pts=[[float(v) for v in p[1:]] for p in one(w,'pts')[1:]]
  if pts in [[[309.88,50.8],[317.5,50.8]],[[309.88,27.94],[309.88,50.8]],[[317.5,88.9],[317.5,101.6]],[[330.2,99.06],[330.2,101.6]]]:comp.remove(w)
 for n,y in [('SCL_HOST',63.5),('SDA_HOST',76.2)]:comp.append(label(n,(317.5,y),'hierarchical_label','bidirectional',0))
 # Add IMU to root, without hiding the inter-sheet wires behind net labels.
 cs=next(s for s in many(root,'sheet') if prop(s,'Sheetname')=='Compute')
 for n,y in [('SCL_HOST',63.5),('SDA_HOST',76.2)]:
  cs.append(node(f'(pin {q(n)} bidirectional (at 269.24 {y} 0) (effects (font (size 1.27 1.27)) (justify right)) (uuid {uid("compute-"+n)}))'))
 ims=node(f'''(sheet (at 312.42 45.72) (size 81.28 116.84) (stroke (width .254) (type default)) (fill (color 0 0 0 0)) (uuid {IMU})
 (property "Sheetname" "IMU" (at 312.42 44.45 0) (effects (font (size 1.52 1.52)) (justify left bottom)))
 (property "Sheetfile" "imu.kicad_sch" (at 312.42 163.83 0) (effects (font (size 1 1)) (justify left top)))
 (instances (project "smove-r2-main" (path "/{TOP}" (page "5")))))''')
 for n,y,kind in [('SCL_HOST',63.5,'bidirectional'),('SDA_HOST',76.2,'bidirectional'),('3V3_MAIN',129.54,'input'),('GND',157.48,'passive')]:
  ims.append(node(f'(pin {q(n)} {kind} (at 312.42 {y} 180) (effects (font (size 1.27 1.27)) (justify left)) (uuid {uid("imu-"+n)}))'))
  if n.endswith('HOST'):root.append(wire((269.24,y),(312.42,y)))
 root.append(ims);root.append(text('U5 local 1.8V\nU3 PCA9306 + BOTH pull-up pairs\nU2 ICM-20948\n1.8V INT1: test only; FIFO polling\nTop package +Z OUTWARD',(320,96),1.02))
 for x1,y1,x2,y2 in [(165.1,129.54,165.1,170.18),(165.1,170.18,299.72,170.18),(299.72,170.18,299.72,129.54),(299.72,129.54,312.42,129.54),(157.48,157.48,157.48,177.8),(157.48,177.8,294.64,177.8),(294.64,177.8,294.64,157.48),(294.64,157.48,312.42,157.48)]:root.append(wire((x1,y1),(x2,y2)))
 w=next(w for w in many(root,'wire') if one(w,'uuid')[1]=='c79cd7c1-c1d6-5348-9f01-77da356b27a3');root.remove(w);root.extend([wire((91.44,129.54),(165.1,129.54)),wire((165.1,129.54),(177.8,129.54))])
 root.append(node(f'(junction (at 165.1 129.54) (diameter 0) (color 0 0 0 0) (uuid {uid("3v3-branch")}))'))
 # Explicit root name prevents Compute/ scope drift, maps documented below.
 for n,y in [('SCL_HOST',63.5),('SDA_HOST',76.2)]:root.append(label(n,(284.48,y)))
 one(imu,'uuid')[1]=IMU
 one(one(imu,'title_block'),'title')[1]=q('sMove / integrated ICM-20948 / SAME main PCB')
 one(one(imu,'title_block'),'comment')[2]=q('Actual carrier circuitry transferred; no sensor substitution; +Z outward')
 imu[:]=[x for x in imu if not(isinstance(x,list) and ((x[0]=='symbol' and prop(x,'Reference') in ['J5','#FLG01','#FLG02']) or x[0]=='sheet_instances'))]
 # Former connector pin wires become hierarchy interfaces; shield branch is removed.
 for w in many(imu,'wire'):
  pts=[[float(v) for v in p[1:]] for p in one(w,'pts')[1:]]
  if pts==[[55.88,142.24],[60.96,142.24]]:imu.remove(w)
 for n,xy,kind in [('3V3_MAIN',(55.88,101.6),'input'),('GND',(55.88,111.76),'passive'),('SDA_HOST',(55.88,121.92),'bidirectional'),('SCL_HOST',(55.88,132.08),'bidirectional')]:imu.append(label(n,xy,'hierarchical_label',kind,180))
 for l in many(imu,'label'):
  l[1]=q({'3V3_IMU_IN':'3V3_MAIN','SDA_3V3':'SDA_HOST','SCL_3V3':'SCL_HOST'}.get(val(l[1]),val(l[1])))
 for t in many(imu,'text'):
  st=val(t[1])
  if 'REUSABLE' in st:t[1]=q('INTEGRATED ICM-20948 | SAME ESP32-C3 MAIN PCB | 3.3V HOST / LOCAL 1.8V')
  elif st.startswith('J5:'):t[1]=q('Internal PCB interconnect, NO harness.\nHost open-drain; no extra host pulls.\nTP14 INT1 is 1.8V TEST ONLY: no 3.3V injection.\nFIFO polling retained, no MCU IRQ/wake connection.')
  elif '100kHz' in st:
   one(t,'at')[2]='241.3';t[1]=q('100kHz I2C, address 0x68. FIFO polling retained. TP14 exposes INT1 (1.8V) for scope ONLY.\nU2 TOP, rotated -90 degrees in PCB: accel/gyro +Z OUTWARD, magnetometer raw +Z INWARD.\nRigid registered peripheral main-PCB seats; no support/clamping under U2. RF/magnetic/thermal/fit tests still required.')
 # Preserve all component UUIDs and references; deliberate project/path and library migration.
 for s in many(imu,'symbol'):
  for x in walk(s):
   if x[0]=='project':x[1]=q('smove-r2-main')
   if x[0]=='path':x[1]=q('/'+TOP+'/'+IMU)
   if x[0]=='lib_id' and val(x[1]).startswith('carrier:'):x[1]=q(val(x[1]).replace('carrier:','imu:'))
   if x[0]=='property' and val(x[1])=='Footprint':x[2]=q(val(x[2]).replace('carrier:','imu:'))
 for s in many(one(imu,'lib_symbols'),'symbol'):
  if val(s[1]).startswith('carrier:'):s[1]=q(val(s[1]).replace('carrier:','imu:'))
  for x in walk(s):
   if x[0]=='property' and val(x[1])=='Footprint':x[2]=q(val(x[2]).replace('carrier:','imu:'))
 # INT1 was intentionally NC; only a short passive debug pad is added, NOT 3.3V GPIO.
 for nc in many(imu,'no_connect'):
  if [float(v) for v in one(nc,'at')[1:]]==[335.28,137.16]:imu.remove(nc)
 imu.append(wire((335.28,137.16),(353.06,137.16)));imu.append(label('INT1_1V8',(353.06,137.16)))
 power=parse(old('PCB/main/power.kicad_sch')); sheets={'Power':power,'Compute':comp,'IMU':imu}
 for name,a in sheets.items():
  one(a,'lib_symbols').append(tp_symbol())
  rows=[t for t in TP if t[2]==name]
  for i,(ref,net,_,_,_) in enumerate(rows):
   x=40.64+i*35.56;y=257.81 if name=='IMU' else 261.62
   sid={'Power':'a926f61e-132d-5af0-876e-12788077b17d','Compute':COMP,'IMU':IMU}[name]
   inst=node(f'''(symbol (lib_id "debug:TestPad") (at {x} {y} 0) (unit 1) (in_bom no) (on_board yes) (dnp no) (uuid {uid(ref)})
 (property "Reference" "{ref}" (at {x} {y-5} 0) (effects (font (size 1.27 1.27))))
 (property "Value" "{net}" (at {x} {y-7.5} 0) (effects (font (size 1.0 1.0))))
 (property "Footprint" "debug:TestPad_1mm" (at {x} {y} 0) (effects (font (size 1 1)) (hide yes)))
 (pin "1" (uuid {uid(ref+'pin')})) (instances (project "smove-r2-main" (path "/{TOP}/{sid}" (reference "{ref}") (unit 1)))))''')
   a.extend([inst,wire((x,y),(x,y+5.08)),label(net,(x,y+5.08))])
 for f,a in [('smove-r2-main.kicad_sch',root),('compute.kicad_sch',comp),('power.kicad_sch',power),('imu.kicad_sch',imu)]:save(H/f,a)
 # Local caches and libraries: exact original sensor footprint/package, not a substitute.
 shutil.copytree(C/'carrier.pretty',H/'imu.pretty',dirs_exist_ok=True)
 shutil.copytree(C/'models',H/'imu-models',dirs_exist_ok=True)
 (H/'imu-models/J5_MAX_HEADER_ENVELOPE.step').unlink(missing_ok=True)
 ms=json.loads((H/'imu-models/model-status.json').read_text());ms.pop('J5',None);(H/'imu-models/model-status.json').write_text(json.dumps(ms,indent=2)+'\n')
 for model in (H/'imu-models').glob('*.step'):model.write_text('\n'.join(line.rstrip() for line in model.read_text().splitlines())+'\n')
 for f in (H/'imu.pretty').glob('*.kicad_mod'):f.write_text(f.read_text().replace('${KIPRJMOD}/models/','${KIPRJMOD}/imu-models/'))
 for f in ['JST_PH_S4B-PH-SM4-TB_1x04-1MP_P2.00mm_Horizontal.kicad_mod','H1_Locator.kicad_mod','H2_Locator.kicad_mod']:(H/'imu.pretty'/f).unlink()
 (H/'imu.kicad_sym').write_text((C/'carrier.kicad_sym').read_text().replace('carrier:','imu:'))
 for n in ['Device','power']:
  # Main uses its own embedded power GND symbols; table's imported power supplies PWR_FLAG only.
  lib=parse((C/(n+'.kicad_sym')).read_text()); names={val(x[1]) for x in many(lib,'symbol')}
  for sym in many(one(parse(old('PCB/main/compute.kicad_sch')),'lib_symbols'),'symbol'):
   if val(sym[1]).startswith(n+':') and val(sym[1]).split(':')[1] not in names:
    cp=copy.deepcopy(sym);cp[1]=q(val(sym[1]).split(':')[1]);lib.append(cp)
  save(H/(n+'.kicad_sym'),lib)
 save(H/'debug.kicad_sym',['kicad_symbol_lib',['version','20241209'],['generator',q('kicad_symbol_editor')],copy.deepcopy(tp_symbol())])
 a=parse((H/'debug.kicad_sym').read_text());many(a,'symbol')[0][1]=q('TestPad');save(H/'debug.kicad_sym',a)
 for filename,typ,libs in [('sym-lib-table','KiCad',{'imu':'imu.kicad_sym','debug':'debug.kicad_sym','Device':'Device.kicad_sym','power':'power.kicad_sym'}),('fp-lib-table','KiCad',{'imu':'imu.pretty','debug':'debug.pretty'})]:
  a=parse(old('PCB/main/'+filename));names={val(one(l,'name')[1]) for l in many(a,'lib')}
  for n,p in libs.items():
   if n not in names:a.append(node(f'(lib (name "{n}") (type "{typ}") (uri "${{KIPRJMOD}}/{p}") (options "") (descr "Project-local integrated circuit source"))'))
  save(H/filename,a)
 (H/'debug.pretty').mkdir(exist_ok=True)
 (H/'debug.pretty/TestPad_1mm.kicad_mod').write_text('''(footprint "TestPad_1mm" (version 20241229) (generator "pcbnew") (layer "F.Cu")
 (attr smd exclude_from_pos_files exclude_from_bom)
 (property "Reference" "TP**" (at 0 -1.2 0) (layer "F.SilkS") (effects (font (size .7 .7) (thickness .12))))
 (property "Value" "TestPad_1mm" (at 0 1.2 0) (layer "F.Fab") (effects (font (size .7 .7) (thickness .1))))
 (fp_circle (center 0 0) (end .65 0) (stroke (width .05) (type default)) (layer "F.CrtYd"))
 (pad "1" smd circle (at 0 0) (size 1 1) (layers "F.Cu" "F.Mask") (solder_mask_margin .05)))\n''')
 # Emit expected connection contract from two genuine sources with explicit mapping.
 parts=json.loads(old('PCB/main/parts-main.json'));del parts['J4']
 for r,v in parts.items():v['path']='/'+TOP+'/'+({'Compute':COMP,'Power':'a926f61e-132d-5af0-876e-12788077b17d','USB':'2bda09d7-02a6-5813-8901-250e661184c8'}[next(n for n,a in [('Compute',comp),('Power',power),('USB',parse(old('PCB/main/usb.kicad_sch')))] if any(prop(s,'Reference')==r for s in many(a,'symbol')))])+'/'+v['uuid']
 cp=json.loads((C/'parts.json').read_text());contract=json.loads((C/'electrical-contract.json').read_text())
 for r,v in cp.items():
  if r=='J5':continue
  s=next(s for s in many(imu,'symbol') if prop(s,'Reference')==r);v.update(board='main',ref=r,fitted=True,uuid=one(s,'uuid')[1],path='/'+TOP+'/'+IMU+'/'+one(s,'uuid')[1],fp=prop(s,'Footprint').split(':')[1],pins={k: {'3V3_IMU_IN':'3V3_MAIN','SDA_3V3':'SDA_HOST','SCL_3V3':'SCL_HOST'}.get(n,n) for k,n in contract[r]['pins'].items()})
  if r=='U2':v['pins']['12']='INT1_1V8'
  parts[r]=v
 for r,n,s,x,y in TP:parts[r]=dict(board='main',ref=r,value=n,fitted=False,fp='TestPad_1mm',mpn=None,jlc=None,pins={'1':n},uuid=uid(r),path='/'+TOP+'/'+{'Power':'a926f61e-132d-5af0-876e-12788077b17d','Compute':COMP,'IMU':IMU}[s]+'/'+uid(r),placement=[x,y,0])
 (H/'parts-main.json').write_text(json.dumps(parts,indent=2)+'\n')

if __name__=='__main__':
 ap=argparse.ArgumentParser(description=__doc__);ap.add_argument('--apply',action='store_true',required=True);ap.parse_args();schematic();print('Schematic/source migration complete. Native PCB routing must be applied and validated separately.')

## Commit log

2026-09-08 sMove R2: verified current-only local root snapshot
    Preserve native CAD and deliverable bytes; consolidate approved workspace 016 cleanup. Retain other workspace and remote histories.
    [BOM.csv, C_0402_1005Metric.step, C_0603_1608Metric.step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]
2026-09-08 Split main schematic into wired USB Power Compute sheets and document IMU housing alignment
    [compute.kicad_sch, power.kicad_sch, smove-r2-main.kicad_pcb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]
2026-09-08 Add ESP32 BOOT and RESET silkscreen labels and verification artifacts
    [smove-r2-main.kicad_pcb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]
2026-09-08 Unify RGB symbol and add coplanar body-facing enclosure with FreeCAD inspection UI
    [base.stl, compute.kicad_sch, lid.stl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]
2026-09-08 Recover compact native delivery from preserved autostash and hash-matched objects
    Explicitly commit all 142 recovery paths (51 restored tracked modifications, 91 additions including recovered assets and forensic verification evidence). Preserve the original 30 merged paths unchang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
    Restore exact compact PCB/schematics/FCStd/source/export bytes; all 138 delivery-manifest entries match. Fresh electrical 1214/1214, source/export coherence 657/657, mechanical 2087/2088 with origina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
    Original 152-path staging index is unavailable: preserve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
    [C_0402_1005Metric.step, C_0603_1608Metric.step, R_0402_1005Metric.step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]
2026-09-09 Compact PCB and housing with 2.54mm PTH battery wire pads
    [BOM.csv, base.stl, divider.stl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]
2026-09-09 Correct PCB-only battery wire metadata and reseal complete delivery
    [smove-r2-main.kicad_pcb]
2026-09-09 Compact main PCB to 25x30mm with keyed single-M3 housing and validated complete delivery
    [BOM.csv, base.stl, diff-stat.txt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]
2026-09-09 Preserve bounded KiCad routing repair and recover clean PCB-only review with mounting release hold
    [faf335b-recovered.kicad_pcb, freerouting-input.dsn, freerouting-rejected-3-opens-In1.kicad_pcb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]
2026-09-09 Deliver two-part case with isolated M3 closure over fully recovered PCB repair
    Preserve complete e033031 recovery as parent 0610d60. No PCB routing, copper, rule or firmware changes during casing. Two printed parts, integral insulated battery tunnel, split PCB grooves, off-PCB 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
    [BOM.csv, base.stl, divider.stl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]
2026-09-09 Deliver simplified central-H1 two-print case with intact PCB repair
    Replace the side closure with only M3x8 through existing H1, preserve complete repair 0610d60, and remove all modeled wires/reserved lead geometry. Keep accepted 42x28.8x19.6 layout and pack envelope. Consolidate small seats/fences into solid corner blocks and broad lid pads; remove hooks and sliding lid motion. Regenerate native/STEP/manifold STLs and GUI review images, critical diffs, exact package manifest and pending cleanup inventory. 374 CAD checks and zero ERC/DRC/opens/parity. Physical print, alignment, preload and pack/lead qualification remain held. Review only; no merge or cleanup.
    [BOM.csv, base.stl, lid.stl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]
2026-09-10 Align buttons.
    [lid.stl, main-board-only.step, main-installed-models.step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]
2026-09-10 Replace screw mounting with configurable three-piece screwless enclosure and PCB ECO
    [BOM.csv, base.stl, bottom-cover.stl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]
2026-09-10 Complete screwless delivery: include 23 paths omitted from initial integration
    [smove-r2-enclosure.FCStd, top-cover.stl]
2026-09-10 Add protected antenna cap, flush USB opening and perimeter battery wiring to enclosure
    [BOM.csv, bottom-cover.stl, midframe.stl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]
2026-09-14 Add a different routing setup
    [smove-r2-main.kicad_pcb]
2026-09-14 Fix routing issues.
    [smove-r2-main.kicad_pcb]
2026-09-14 Add better component placements for efficient routing.
    [compute.kicad_sch, placements.csv, smove-r2-main.kicad_pcb]
2026-09-14 Add some decent routing.
    [smove-r2-main.kicad_pcb]
2026-09-14 Setting up for manual placements.
    [smove-r2-main.kicad_pcb]
2026-09-14 Add some partial routing for the main PCB
    [smove-r2-main.kicad_pcb]
2026-09-15 Add manual PCB routing for the main
    [smove-r2-main.kicad_pcb]
2026-09-15 Cleanup the repo
    [BOM.csv, C_0402_1005Metric.step, C_0603_1608Metric.step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]
2026-09-15 Remove dist
    [BOM.csv, main-board-only.step, main-installed-models.step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]
2026-09-15 Add new JLCPCB export tool
    [bom.csv, pick_and_place.csv]
2026-09-15 Make sure it's printer friendly
    [bom.csv, main-parts.csv, power.kicad_sch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]
2026-09-15 Add mounting holes
    [smove-r2-main.kicad_pcb]
2026-09-15 Add Battery on/off switch
    [compute.kicad_sch, main-parts.csv, power.kicad_sch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]
2026-09-15 power: hardwire BQ24074 EN1 high to select USB500 input limit
    - Remove EN1 (U6.6) tie to GND; add R25 (100k 0402, 0402WGF1003TCE) from EN1 to SYS (U6 OUT rail)
    - CE_N/EN2/VSS/EP remain grounded; ISET/ILIM/TS unchanged
    - Update stale sheet annotations (USB500 ~500 mA; no source/CC awareness)
    - Schematic-only ECO: layout/routing intentionally not updated
    [power.kicad_sch]
2026-09-15 power: add pack-NTC cell-temperature sensing on charger TS (Option A)
    - J2 becomes a 3-contact pack pad group (BAT+ / BAT- / NTC): new symbol + new footprint BatteryWire_3x_PTH_P2.54mm_D1.0mm (pad 3 added 2.54mm beyond pad 2, existing pads 1/2 unchanged)
    - TS (U6 pin 1) now senses the in-pack 10k B3435 NTC (TH1, off-board, in_bom no) instead of the 10k fixed bias; charger suspends ~0..51C natively
    - R23 (10k TS bias) set DNP / in_bom no - fallback for 2-wire packs only; must NOT be fitted with an NTC pack
    - Annotations updated. Schematic-only ECO: layout/routing/footprint placement intentionally not updated
    [power.kicad_sch]
2026-09-15 power: separate on-board NTC part, drawn TS/SYS nets, drop R23 and J2 NTC contact
    - J2 restored to the 2-contact pack connector (BAT+ / BAT-); the NTC contact is gone.
    - TH1 is now its own part: project symbol smove-r2-main:NTC_10K_B3435 + project footprint
    smove-r2-main:NTC_0402_1005Metric (TDK NTCG103JF103FT1, LCSC C209959), in_bom/on_board yes,
    wired directly U6.1 (TS) -> TH1.1 and TH1.2 -> GND.
    - TS and SYS nets are now single continuous drawn wires (one label each kept for net naming);
    the label-only joins are gone, and the dangling TS stub is removed.
    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
    [power.kicad_sch]
2026-09-15 Implement routing changes
    [smove-r2-main.kicad_pcb]
2026-09-15 fab: regenerate JLCPCB assembly/fab outputs for the routed board
    - Complete the missing Manufacturer fields (verified against the live LCSC/JLC
    library) on the affected symbols and footprints; no connectivity, geometry,
    routing or value changes.
    - Regenerate dist/jlcpcb: bom.csv, pick_and_place.csv, gerber.zip, export-report.json
    from the current board (export.py --overwrite --side top --require-part-numbers).
    - BOM: R23 removed, R24/R25 added, TH1 (TDK NTCG103JF103FT1 / C209959) added,
    U4 corrected to XC6220B331MR-G / C86534.
    - CPL: R23 row gone; R24, R25 and TH1 rows added.
    - DRC: 0 violations, 0 unrouted; one schematic-parity warning (U4 symbol Footprint
    field reads SOT-23-5 whi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
    [bom.csv, compute.kicad_sch, pick_and_place.csv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]
2026-09-15 board: user routing + direct C11 ground path (thermal-ECO baseline)
    [smove-r2-main.kicad_pcb]
2026-09-15 layout: U4 thermal ECO — 8 GND vias + solid GND pours (F.Cu 26.0 mm² / B.Cu 50.0 mm² attached)
    - Add 8 × 0.6/0.3 mm GND through vias adjacent to U4's GND pad (no via-in-pad),
    staggered around existing routing; measured min gap to any foreign copper 0.2095 mm.
    - Add two solid-connected GND zones U4_THERMAL_F.Cu / U4_THERMAL_B.Cu (priority 1,
    0.2 mm min fill, 0.21 mm clearance) giving 26.008 mm² directly attached copper on
    F.Cu (was 1.058 mm²) and a 50.025 mm² bottom spreader (was 0.212 mm²).
    - smove-r2-main.kicad_dru: +6 lines, a 0.21 mm clearance rule scoped to those two
    named zones only (the global 0.15 mm rule overrides zone-local clearance).
    - No tracks added/moved/delete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
    [smove-r2-main.kicad_pcb]
2026-09-15 fab: eliminate JLCPCB export warnings (H1-H3 mounting holes in schematic, U4 footprint aligned)
    [bom.csv, power.kicad_sch, smove-r2-main.kicad_pcb]
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2026-10-29 Add ESP-NOW IMU link: sMove tx + bench ESP32 rx (05-espnow-imu).
    tx/ reads the ICM-20948 every 100 ms and transmits a 36-byte frame on
    channel 1; rx/ relays each frame to /dev/ttyUSB0 as S,... lines and
    beacons a 1 Hz HELLO so the transmitter pairs by MAC (broadcast until
    then, back to broadcast if the ACKs stop). host/espnow_monitor.py shows
    rate, loss, RSSI, delay jitter and the live 6-axis values.

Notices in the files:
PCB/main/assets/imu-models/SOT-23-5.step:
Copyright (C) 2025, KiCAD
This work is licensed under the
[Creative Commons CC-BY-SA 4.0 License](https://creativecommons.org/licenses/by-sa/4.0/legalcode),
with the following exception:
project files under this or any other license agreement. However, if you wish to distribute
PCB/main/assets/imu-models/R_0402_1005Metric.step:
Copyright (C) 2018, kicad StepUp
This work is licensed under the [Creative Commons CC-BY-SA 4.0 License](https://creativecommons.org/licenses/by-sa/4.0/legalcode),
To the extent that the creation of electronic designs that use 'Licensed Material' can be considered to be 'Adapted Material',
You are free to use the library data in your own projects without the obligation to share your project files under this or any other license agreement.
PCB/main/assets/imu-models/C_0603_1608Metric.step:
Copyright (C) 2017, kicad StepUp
